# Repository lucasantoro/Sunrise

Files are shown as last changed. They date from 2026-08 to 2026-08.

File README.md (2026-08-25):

# Sunrise

Drone-mounted visible-light communication. The goal is an optical link that a
drone can carry: modulated light instead of RF, with the mechanical, optical,
electronic and firmware work kept as separate areas that reference each other.

The link itself works and is documented in
[`communications/openvlc/`](communications/openvlc/): two nodes, each a
Raspberry Pi with an STM32H723 Pi HAT, carrying IP traffic over Manchester OOK
at 1 Mbit/s in both directions.

## Structure

```text
Sunrise/
  communications/     the optical link — firmware, gateways, control software
  hardware/           PCBs — LED driver, photodiode front end, power, Pi HAT
  mechanical_design/  CAD: mounts, optical housing
  simulations/        link, optical, channel and integration studies
  drone_software/     flight stack and companion-computer integration
  docs/               cross-area architecture and integration notes
  outputs/            generated artefacts
```

`hardware/` and `mechanical_design/` sit beside each other deliberately: the
optical housing and the board geometry are one problem. The current open issue
on the link — isolating a node's transmitter from its own receiver — needs
both.

## Where to start

| you want to | read |
|---|---|
| run the link at the bench | [`communications/openvlc/raspberry-gateway/NOTES.md`](communications/openvlc/raspberry-gateway/NOTES.md) |
| understand how it works | [`communications/openvlc/firmware-v2/docs/modem_design.md`](communications/openvlc/firmware-v2/docs/modem_design.md) |
| know what goes over the light | [`communications/openvlc/firmware-v2/docs/wire_format.md`](communications/openvlc/firmware-v2/docs/wire_format.md) |
| see the boards | [`hardware/README.md`](hardware/README.md) |

## Status

The link is in service and measured: about 830 kbit/s of delivered UDP each
way, 124.6 of 125 frames per second, ~0.30% loss after CRC and Reed-Solomon.

Its open problem is physical rather than software. With both nodes
transmitting, a node's own LED couples into its own photodiode strongly enough
to destroy reception — the transmitter occupies roughly 90% of the frame
period, so there is no dark window to receive in. The fix is optical isolation
between the two, which is where this area meets `hardware/` and
`mechanical_design/`.

## Licence

MIT — see [`LICENSE`](LICENSE).

The Arm CMSIS and STMicroelectronics driver trees under
`communications/openvlc/firmware-v*/Drivers/` are redistributed under their own
Apache-2.0 and BSD-3-Clause terms, and `hardware/` is board design data rather
than software. [`THIRD-PARTY-NOTICES.md`](THIRD-PARTY-NOTICES.md) sets out what
the MIT licence does and does not cover.

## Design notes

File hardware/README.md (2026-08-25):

# Hardware (PCBs)

Altium Designer source and fabrication outputs for the custom boards of the
OpenVLC optical link. These are the physical layer the firmware in the sibling
firmware under communications/openvlc/ runs on: the LED transmitter, the photodiode/comparator
receiver front-end, their power and interconnect boards, and the STM32 +
Raspberry Pi carrier.

```mermaid
flowchart LR
    PDB["power/<br/>PCB_PDB<br/>power distribution"] --> TX
    PDB --> INTER
    TX["tx/<br/>PCB_TX<br/>LED driver (Cree XHP70)"] -->|light| RX
    INTER["interconnect/<br/>PCB_INTER<br/>LED carrier / interface"] --- TX
    RX["rx/<br/>PCB_RX<br/>photodiode + comparator slicer"] --> HAT
    HAT["stm32-pi-hat/<br/>STM32_Pi_HAT<br/>STM32 RX MCU + Pi carrier"]
```

| Folder | Board family | Role in the link |
| --- | --- | --- |
| [`tx/`](tx/) | `PCB_TX` | Optical **transmitter** — high-power LED (Cree XHP70) driver. Driven by the Pi HAT in [`../firmware-v2/`](../communications/openvlc/firmware-v2/). |
| [`rx/`](rx/) | `PCB_RX` | Optical **receiver** front-end — photodiode + analog comparator slicer feeding the STM32. Feeds the Pi HAT in [`../firmware-v2/`](../communications/openvlc/firmware-v2/). |
| [`interconnect/`](interconnect/) | `PCB_INTER` | Interconnect / LED carrier board between the driver and the optics. |
| [`power/`](power/) | `PCB_PDB` | Power Distribution Board supplying the LED / driver chain. |
| [`stm32-pi-hat/`](stm32-pi-hat/) | `STM32_Pi_HAT` | Carrier HAT for the STM32 receiver MCU and the Raspberry Pi gateway ([`../raspberry-gateway/`](../communications/openvlc/raspberry-gateway/)). |

## Revision history

Newest revision per family is listed last and is the current design. A
**Fab date** means a manufacturer order package (`P-<job>_<date>_…`) is
included, i.e. that revision was actually built; revisions with only a
*Project Outputs* archive are design/output snapshots.

### Transmitter — `tx/`
| Revision | 3D | Fab package | Notes |
| --- | :-: | --- | --- |
| `PCB_TX_V2.1.3_B` | ✓ | output archive | bundles footprint libs (XHP70 LED, 0603 R/C) |
| `PCB_TX_V2.1.3_C` | ✓ | output archive | |
| `PCB_TX_V2.2_A` | ✓ | output archive | **current TX** |

### Receiver — `rx/`
| Revision | 3D | Fab package | Notes |
| --- | :-: | --- | --- |
| `PCB_RX_V2.4` | ✓ | — | with footprint libs |
| `PCB_RX_V2.4_B` | ✓ | — | with footprint libs |
| `PCB_RX_V2.5_A` | ✓ | output archive | |
| `PCB_RX_V2.5_B` | ✓ | output archive | |
| `PCB_RX_V2.5_C` | ✓ | output archive | |
| `PCB_RX_V2.6` | ✓ | **2025-12-13** (P-17464) | manufactured |
| `PCB_RX_V2.7` | ✓ | **2025-12-13** (P-17464) | manufactured — **current RX** |

### Interconnect — `interconnect/`
| Revision | 3D | Fab package | Notes |
| --- | :-: | --- | --- |
| `PCB_INTER_V1.1` | ✓ | — | with footprint libs |
| `PCB_INTER_V1.2` | ✓ | **2025-12-13** (P-17464) | manufactured — **current** |

### Power Distribution — `power/`
| Revision | 3D | Fab package | Notes |
| --- | :-: | --- | --- |
| `PCB_PDB_V1.1` | ✓ | — | with footprint libs |
| `PCB_PDB_V1.2` | — | output archive | **current** |

### STM32 / Raspberry Pi carrier — `stm32-pi-hat/`
| Revision | 3D | Fab package | Notes |
| --- | :-: | --- | --- |
| `STM32_Pi_HAT` | ✓ | **2026-05-29** (P-18729) | manufactured. Schematic file is `SRM32_Pi_HAT.SchDoc` (original typo, kept to preserve the Altium project link). |

## What each revision folder contains

- **Editable source** (open in Altium Designer):
  - `*.PrjPcb` — the project file (open this);
  - `*.SchDoc` — schematic;
  - `*.PcbDoc` — board layout;
  - `*.PcbLib` — local footprint libraries used by that revision (where present).
- **`*.step`** — 3D model of the assembled board (mechanical / enclosure work).
- **Fabrication package** — a `.zip` of Gerbers, NC drill, and drill reports,
  ready to send to a board house. The `P-<job>_<date>_…` archives are the
  exact packages that were ordered.

## What was intentionally excluded

To keep the repository lean, the following Altium working artifacts were **not**
imported (they are regenerated locally by Altium and were ~1.1 GB):

- `History/` — automatic per-save backups;
- per-board nested `.git/` repositories (would have become broken submodules);
- `__Previews/`, `Project Logs for …/`;
- `*.PrjPcbStructure`, `*.SchDocPreview` — regenerated index/preview files;
- the loose `Project Outputs for …/` Gerber folders — already captured by the
  per-revision fabrication `.zip`.

See [`../.gitignore`](../communications/openvlc/.gitignore) for the patterns that keep these out if the
original Altium folders are ever re-synced over this tree.

## Opening a board

1. Install Altium Designer.
2. Open the revision's `*.PrjPcb`.
3. The schematic, layout, and local libraries resolve relative to that file.

To re-manufacture a revision, send its fabrication `.zip` to a board house
as-is, or regenerate outputs from Altium (Fabrication Outputs → Gerber/NC Drill).

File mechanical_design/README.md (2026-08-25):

# Mechanical Design

Use this folder for drone-mounted VLC hardware design.

Suggested structure:

```text
mechanical_design/
  inventor/       # Native Autodesk Inventor files
  exports/        # STEP/STL/PDF exports intended for sharing
  mounts/         # LED, photodiode, lens, and PCB supports
  notes/          # Assembly notes, tolerances, alignment notes
```

Avoid committing large generated exports unless they are needed for review or fabrication.

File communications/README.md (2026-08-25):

# Communications

Communication systems for Sunrise. At present that is one thing: the
visible-light link.

```text
communications/
  openvlc/       the VLC link — firmware, Raspberry Pi gateway, control panel
```

## openvlc

An OpenVLC-derived optical link carrying ordinary IP traffic. Two nodes, each a
Raspberry Pi with an STM32H723 Pi HAT, exchange packets over modulated light
and present the result to Linux as a `tun0` interface — so anything with an IP
address on one Pi reaches the other.

Manchester OOK at 1 Mbit/s, full duplex, framed with Reed-Solomon and a CRC.

| | |
|---|---|
| in service | `openvlc/firmware-v2/` |
| in development | `openvlc/firmware-v3/` |
| superseded | five earlier STM32 stages and a BeagleBone chain — not published |

Start at [`openvlc/README.md`](openvlc/README.md).

The boards are not here: they are in [`../hardware/`](../hardware/), beside the
mechanical design, because the PCB geometry and the optical housing are one
problem.

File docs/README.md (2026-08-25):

# System Documentation

Use this folder for Sunrise-level documentation that spans mechanical design, simulations, drone software, and communication firmware.

Suggested documents:

- system architecture;
- drone integration plan;
- hardware block diagrams;
- optical alignment notes;
- test campaign reports;
- bill of materials;
- risk and limitation notes.

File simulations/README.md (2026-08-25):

# Simulations

Use this folder for simulations related to the drone-mounted VLC link.

Possible topics:

- optical link budget;
- LED/photodiode geometry;
- drone motion and pointing error;
- channel noise and ambient light;
- BER/PER simulations;
- network behavior between drones.

Suggested structure:

```text
simulations/
  optical_link/
  drone_motion/
  channel_model/
  notebooks/
  results_sample/
```

## What is here

| file | |
|---|---|
| `Carclo10391_CREE_XHP35_White.zmx` | Zemax model: Carclo 10391 lens over a CREE XHP35 White emitter |

The matching `.ZDA` ray database is **not** in the repository. It is 1.4 GB of
traced rays generated from the `.zmx` above, which exceeds GitHub's 100 MB
per-file limit; Zemax regenerates it from the source model, and the emitter ray
file it starts from comes from the LED vendor.

Keep heavy generated results outside Git or store them as release artifacts.

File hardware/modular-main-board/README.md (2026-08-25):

# OpenVLC modular main board proposal

This note defines a manufacturable direction for splitting the current OpenVLC
hardware into three boards:

- `TX_MODULE`: optical transmitter daughterboard.
- `RX_MODULE`: optical receiver daughterboard.
- `MAIN_BOARD`: power, host/control, protection, service connectors, and
  interconnect between TX/RX.

## Source revisions used

Current hardware in this repository:

| Function | Current source | Fab/output package | Notes |
| --- | --- | --- | --- |
| TX | `tx/PCB_TX_V2.2_A` | `Project Outputs for PCB_TX_V2.2_A.zip` | Current transmitter; ODB++ package present. |
| RX | `rx/PCB_RX_V2.7` | `P-17464_2025-12-13_IMDEA_PCB_RX_V2.7.zip` | Current receiver; manufactured package present. |
| Power | `power/PCB_PDB_V1.2` | `Project Outputs for PCB_PDB_V1.2.zip` | Current PDB. |
| STM32/Pi carrier | `stm32-pi-hat/STM32_Pi_HAT` | `P-18729_2026-05-29_IMDEA_STM32_Pi_HAT.zip` | Current host carrier. |

The source files are Altium `.SchDoc/.PcbDoc`. Gerbers for a new design should
be regenerated from Altium after schematic/layout work and DRC/ERC. The current
workspace does not include an EDA CLI capable of modifying Altium files or
producing verified new Gerbers directly.

## Current board facts

Measured from Gerber/ODB extents:

| Board | Approx. size |
| --- | ---: |
| `PCB_TX_V2.2_A` | 85.0 mm x 54.6 mm |
| `PCB_RX_V2.7` | 85.0 mm x 54.6 mm |
| `PCB_INTER_V1.2` | 48.0 mm x 54.6 mm |
| `PCB_PDB_V1.2` | 100.0 mm x 100.0 mm |
| `STM32_Pi_HAT` | 175.1 mm x 124.4 mm |

Important TX nets/components identified:

- Rails/signals: `+13.8V`, `+5V`, `+3.3V`, `GND`, `P8_45`, `PS_ON`,
  `CS_PD`, `MISO_PD`, `MOSI_PD`, `LED`, `HeatSink`.
- Core TX parts: `LM3409QMY/NOPB`, `LZ4-04MDCA-0000`, `SLF12575T-330M3R2-PF`,
  `PMEG3050EP`, `FDC6333C`, `DMT67M8LSS-13`, `ZXMP7A17KTC`,
  `SN74AHC1G126DBVR`, current-sense resistor `CRA2512-FZ-R075ELF`.

Important RX rails/signals identified:

- Rails/signals: `+5V`, `-5V`, `VCC`, `GND`, `VREF`, `VAGC`, `MODE`, `OFSN`,
  `AGC_P`, `AGC_N`, `LNA_P`, `LNA_N`, `BPF_P`, `BPF_N`, `LPF_IN`, `LPF_OUT`,
  `GAIN_OUT`, `ADC_IN`, `CS_PD`, `MISO_PD`, `MOSI_PD`, `+IP`, `-IP`,
  `+VT`, `-VT`, `+VB`, `-VB`, `+eOP`, `-eOP`.
- Core RX parts visible in schematic: `ADA4817-2`, `AD80xx` gain/filter
  stages, `ADS788x` ADC, `LM2661` charge pump, trim pots, analog filters and
  bias networks.

## Proposed partition

### TX_MODULE

Keep the high-current optical transmitter loop on the TX module:

- LED and optics/mechanical alignment.
- LM3409 LED driver, switch MOSFET, diode, inductor, current-sense resistor,
  compensation network, and local high-frequency decoupling.
- Gate/control buffer only if needed to preserve PWM edge quality at the
  driver.
- Local temperature/fan connector if mechanically tied to the LED/heatsink.

Move to `MAIN_BOARD`:

- BeagleBone/Pi/STM32 headers and host-specific wiring.
- Global `+13.8V`, `+5V`, `+3.3V` generation and power sequencing.
- Bulk input protection, fuse/eFuse, reverse polarity protection, power switch,
  service/test connectors.
- Any debug-only test headers not required at the optical module.

Reason: the LED switching current loop must stay physically compact. Moving the
LM3409 power stage to the main board and routing LED current over a connector
would increase EMI and optical-current ringing.

### RX_MODULE

Keep the low-noise receive chain on the RX module:

- Photodiode and optical/mechanical interface.
- First transimpedance/low-noise amplifier stage.
- Critical gain/filter stages whose nodes are `LNA_*`, `BPF_*`, `LPF_*`.
- ADC or comparator/slicer close to the analog front-end unless the main board
  can guarantee a shielded, controlled-impedance short analog path.
- Local analog decoupling, guard ring, and bias/reference filtering.

Move to `MAIN_BOARD`:

- Host MCU/Raspberry Pi/BeagleBone carrier functions.
- SPI/UART/control routing and level shifting.
- Global rails and power supervision.
- Non-critical debug headers.

Preferred RX interface is digital after ADC/comparator. Exporting `ADC_IN` as
an analog signal across a board-to-board connector is possible but should be
treated as the fallback option because it is the most noise-sensitive boundary.

### MAIN_BOARD

Integrate the current PDB and STM32/Pi carrier roles:

- Input power connector, fuse/eFuse, reverse polarity, TVS, current monitoring.
- Buck rail generation: `+13.8V` distribution, `+5V`, `+3.3V`.
- Quiet analog rail generation/filtering for RX: `+5VA`, `-5VA`, `VREF`.
- MCU/host connector and firmware/debug access.
- Board-to-board connectors for one or more TX/RX modules.
- Star-ground strategy and physical zoning for power, digital, and analog.

## Proposed module interfaces

Use locking board-to-board or cable connectors with ground pins interleaved
between noisy or sensitive signals. Do not reuse generic 2.54 mm headers for
final flight/field hardware unless mechanical retention is added.

### TX connector

Minimum signals:

| Pin group | Signal |
| --- | --- |
| Power | `+13.8V_LED`, multiple pins |
| Power return | `PGND_LED`, multiple pins adjacent to `+13.8V_LED` |
| Logic | `TX_PWM` / current modulation input |
| Control | `TX_EN` / `PS_ON` |
| Telemetry | `TX_FAULT`, `TX_TEMP` optional |
| Service | `SCL/SDA` or spare GPIO optional |
| Shield | Chassis/shield if cable is used |

Keep `+13.8V_LED` and `PGND_LED` connector current rating at least 2x the
expected continuous LED current, with derating for temperature.

### RX connector

Preferred digital boundary:

| Pin group | Signal |
| --- | --- |
| Analog power | `+5VA`, `-5VA`, `AGND` |
| Digital power | `+3V3D` or `+5VD`, `DGND` |
| Data | `RX_SPI_SCK`, `RX_SPI_MISO`, `RX_SPI_MOSI`, `RX_CS` |
| Timing | `RX_SAMPLE_CLK` or `RX_DATA_READY` |
| Control | `RX_MODE`, `RX_GAIN`, `RX_EN` |
| Reference/monitor | `VREF_MON`, `RSSI/GAIN_OUT` optional |

Fallback analog boundary:

- `ADC_IN` must be surrounded by ground pins, routed short, shielded, and kept
  away from TX power routing.
- Add an RC input filter and clamp at the main-board ADC input.

## EMC, noise, and layout constraints

- Use at least a 4-layer stackup for the main board: signal, solid GND, power,
  signal. Prefer 6 layers if TX current and RX analog coexist on the same PCB.
- Physically separate zones: TX power stage, digital host/MCU, RX analog.
- Put RX analog at the quiet edge of the board. Put TX power at the opposite
  edge. Do not route LED current below the RX module.
- Use a single low-impedance ground system, but route high-current LED return
  directly back to the input/power stage so it does not share narrow copper with
  RX analog returns.
- Add ferrite beads or small LC filters at RX module power entry:
  `+5V_MAIN -> +5VA_RX`, `-5V_MAIN -> -5VA_RX`.
- Keep switching converters, charge pumps, inductors, and fast LED nodes away
  from photodiode/TIA input. If `LM2661` remains on RX, place it in its own
  noisy island with filtering and guard spacing from the photodiode input.
- Route SPI/control to RX with series damping resistors near the driver and
  ground reference pins beside the clock/chip-select.
- Route TX PWM/enable with series damping near the MCU/buffer. Avoid long,
  unterminated fast edges into the LED driver.
- Add TVS/ESD at external connectors, not at the sensitive photodiode node.
- Place test points for `+13.8V`, `+5V`, `+3.3V`, `+5VA`, `-5VA`, `TX_PWM`,
  `TX_EN`, `RX_CS`, `RX_MISO`, `ADC_IN`/digital RX output, and `GND`.

## Gerber/schematic generation path

1. Clone `PCB_TX_V2.2_A` and `PCB_RX_V2.7` into new Altium projects:
   `TX_MODULE_V1`, `RX_MODULE_V1`, `MAIN_BOARD_V1`.
2. Remove host/header/global-power circuitry from TX/RX according to the
   partition above.
3. Add explicit board-to-board connector symbols with locked pinout tables.
4. Move PDB and STM32/Pi carrier functions into `MAIN_BOARD_V1`.
5. Compile all three projects and run ERC.
6. Push ECO from schematic to PCB for each board.
7. Layout with the EMC constraints above; run DRC.
8. Generate Gerber X2, NC drill, ODB++, pick/place, BOM, and STEP.
9. Before fabrication, review Gerbers in an independent viewer and check:
   board outline, drill registration, polarity, solder mask openings,
   connector pin-1 orientation, and TX/RX mating orientation.

## Open decisions before layout

- Number of TX/RX module slots: single link, dual link, or multi-TX array.
- Host architecture: keep STM32 + Raspberry Pi HAT, or replace with a custom
  MCU section on the main board.
- RX boundary: digital after ADC/comparator, or analog `ADC_IN` to main board.
- Mechanical stack: mezzanine modules, cabled modules, or edge-mounted modules.
- LED thermal solution and whether fan control is local to TX or on main board.

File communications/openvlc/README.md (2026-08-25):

# OpenVLC

A visible-light IP link. Two nodes, each a Raspberry Pi carrying an STM32H723
Pi HAT, exchange Linux IP traffic over modulated light — Manchester OOK at
1 Mbit/s, full duplex, presented to Linux as an ordinary `tun0` interface.

```text
   Pi node A                                   Pi node B
   tun0 192.168.0.1                            tun0 192.168.0.2
        |                                            |
   UART 2 Mbaud                                 UART 2 Mbaud
        |                                            |
   H723 Pi HAT      ~~~~~ modulated light ~~~~~  H723 Pi HAT
   optical addr 7      TIM1 TX / COMP1 RX        optical addr 8
```

Anything with an IP address on one Pi can reach the other. The bench runs
`iperf` and streams video over it.

## State

| | |
|---|---|
| **In service** | [`firmware-v2/`](firmware-v2/) |
| Best measured | 124.6 of 125 frames/s delivered, ~0.30% loss, ~830 kbit/s each way |
| **In development** | [`firmware-v3/`](firmware-v3/) — not deployed |
| Superseded | five earlier STM32 stages and the BeagleBone chain — not published |

**Open issue, physical:** with both nodes transmitting, a node's own LED
couples into its own photodiode strongly enough to destroy reception. The
transmitter occupies ~90% of the frame period, so there is no dark window to
hide in. This is being fixed with optical isolation, not in software — see
`firmware-v2/docs/two_transceiver_test.md`.

## Layout

| folder | runs on | what |
|---|---|---|
| [`firmware-v2/`](firmware-v2/) | STM32H723 Pi HAT | **the firmware in service** — comparator RX, TIM1 TX, framing, RS, CRC |
| [`firmware-v3/`](firmware-v3/) | STM32H723 Pi HAT | streaming-decoder experiment; carries a faithful port of the reference implementation for A/B work |
| [`raspberry-gateway/`](raspberry-gateway/) | Raspberry Pi | the bridge: `tun0` ↔ UART, pacing, capture collection, install scripts |
| [`control-app/`](control-app/) | lab PC | PySide6 panel driving the nodes over SSH, live telemetry, diagnostics |

The link went through five earlier STM32 stages and a BeagleBone-transmitter
chain before this one. They are not published: they are superseded, and none of
them builds against the current hardware. One thing from that lineage does
survive here — the frame layout and Reed-Solomon scheme are the upstream
OpenVLC BeagleBone protocol, which `OPENVLC_BEAGLEBONE_COMPAT` selects.

The boards these run on are one level up, in [`../../hardware/`](../../hardware/):
LED driver, photodiode front end, interconnect, power and the STM32 Pi HAT
carrier. They live beside `mechanical_design/` because the optical housing and
the PCB geometry are one problem, not two.

## Start here

**At the bench**, on a Pi:
[`raspberry-gateway/NOTES.md`](raspberry-gateway/NOTES.md) — the commands, how
to enable and save logs, and the meaning of every field in the `COMP`, `TX` and
`trx-bridge` diagnostic lines, plus the failure signatures that are worth
recognising on sight.

**Understanding the link:**

- [`firmware-v2/docs/wire_format.md`](firmware-v2/docs/wire_format.md)
  — line code, frame layout, addressing, Reed-Solomon, and the airtime budget
  that governs most of the system's behaviour
- [`firmware-v2/docs/modem_design.md`](firmware-v2/docs/modem_design.md)
  — how the transmitter and receiver work, and why the comparator threshold
  decides whether the decoder has any margin at all
- [`firmware-v2/docs/comparison_reference_impl.md`](firmware-v2/docs/comparison_reference_impl.md)
  — v2 against a colleague's 884-line implementation of the same link, measured
  side by side

**Bringing up two nodes:**
[`firmware-v2/docs/two_transceiver_test.md`](firmware-v2/docs/two_transceiver_test.md)

## Node naming

Hosts are named `nodeA`, `nodeB`, … and the Pi side derives everything from
that: node letter, tun address (`nodeC` → `192.168.0.3`), and the tag written
into capture filenames. Adding a node means naming the host and running the
installer.

The optical address is separate and set at firmware build time
(`OPENVLC_TRANSCEIVER_NODE`). A receiver discards frames carrying its own
address as source, so **the two boards must never be flashed with the same node
firmware**.

## Quick start

Install the bridge on each Pi:

```bash
cd raspberry-gateway && sudo bash ./install/install_transceiver_service.sh
```

Check the interface came up and the path carries a full-size frame:

```bash
ip -br addr show tun0 && ping -c 5 -M do -s 872 192.168.0.2
```

Measure one direction:

```bash
iperf -u -c 192.168.0.2 -b 800k -l 800 -p 10001 -t 60 -i 1
```

Watch what the modem is doing while it runs:

```bash
journalctl -u openvlc-transceiver -f | grep -E "COMP|TX uart|trx-bridge"
```

Reading those numbers is [`raspberry-gateway/NOTES.md`](raspberry-gateway/NOTES.md).

## A note on the numbers

Loss figures in this repository are counted **after** CRC and Reed-Solomon, so
a "lost" frame is one that failed integrity, not one that arrived corrupt and
was passed on. Implementations without an integrity check report a different
quantity under the same name; the comparison document above goes into why that
makes throughput numbers across implementations incomparable.

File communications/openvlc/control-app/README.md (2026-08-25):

# OpenVLC Control Panel

PySide6 desktop app that runs on the lab PC and controls OpenVLC lab nodes over
SSH. It supports both the legacy RX Pi / TX Pi / BeagleBone video chain and the
two-node STM32 Pi HAT transceiver setup (`openvlc-transceiver` on node A/B).

```mermaid
flowchart LR
    PC["PC\ncontrol panel + VLC"] -->|SSH| RX["RX Pi\nopenvlc-rx + relay"]
    PC -->|SSH| TX["TX Pi\nroute + webcam"]
    PC -->|"SSH via TX Pi"| BBB["BeagleBone\noptical TX"]
    RX -->|"TCP/UDP relay"| PC
    PC -->|SSH| A["Transceiver A Pi\nopenvlc-transceiver"]
    PC -->|SSH| B["Transceiver B Pi\nopenvlc-transceiver"]
    A <-->|"optical + UART bridge"| B
```

## Install on Windows

```powershell
winget install Python.Python.3.12
cd communications\openvlc\control-app
py -m venv .venv
.\.venv\Scripts\Activate.ps1
pip install -r requirements.txt
py run.py
```

Install VLC on the PC and keep the path configured in the Settings tab.

## First run

1. Open **Settings**.
2. Fill in the SSH settings for the nodes you use. For the Pi HAT transceiver
   workflow, configure **Transceiver A Pi** and **Transceiver B Pi**. For the
   legacy video workflow, configure **RX Pi**, **TX Pi**, and **BeagleBone TX**.
   The BBB can use the TX Pi as jump host when it is reachable only through USB
   gadget Ethernet.
3. Set **This PC IP**, **VLC path**, and the validated **TX budget profile**.
4. Save, then run **Test connections**.
5. Run **Check system** before starting traffic.

The configuration is stored in `~/.openvlc_panel.json`. It is plain JSON for lab
convenience, not secure credential storage.

The **RX bridge** and **TX route** buttons run privileged commands on the
Raspberry Pis. Either save the SSH password for those devices in Settings or
configure passwordless sudo for the lab user. Without one of those, systemd and
route setup commands fail with `sudo: a terminal is required`.

For the BBB, prefer a numeric host address. The usual direct USB-gadget target
is `192.168.7.2`; if the BBB is reachable only from the TX Pi, set
`192.168.7.2` as the BBB host and configure the TX Pi fields as its jump host.

## Tabs

### Control

The first tab separates the workflow into three explicit stages:

1. **Verify** - run read-only checks for devices, paths, routes and tools.
2. **Prepare link** - start monitoring, restart the RX bridge, configure the
   TX route and start the selected BBB optical profile.
3. **Performance test** - choose UDP target rate, duration and direction, then
   run iperf.

For the Pi HAT transceiver workflow, the app provides service controls for
node A, node B, and A+B together. The `openvlc-transceiver` daemon is
bidirectional by design, so the app separates TX and RX at test level:

- **Transceiver A -> B** starts iperf server on B and client on A.
- **Transceiver B -> A** starts iperf server on A and client on B.
- **Transceiver full duplex** starts servers on both nodes and clients in both
  directions concurrently.

The **Journal TRX A/B** buttons switch the live monitor to
`journalctl -u openvlc-transceiver -f -o cat -n 0` on the selected node.

Video controls are intentionally absent from this tab. The complete live
session is started and stopped from the **Video** tab.

The iperf result shown by the panel is based on the receiver/server output for
each flow, because that is the authoritative result for delivered throughput
and loss. The transmitter/client output is still included for context.

The iperf runner starts remote processes through PID files:

- receiver/server: `/tmp/openvlc_panel_iperf_server.pid` and
  `/tmp/openvlc_panel_iperf_server.log`;
- transmitter/client: `/tmp/openvlc_panel_iperf_client.pid` and
  `/tmp/openvlc_panel_iperf_client.log`.

Use **Stop iperf** to terminate any server/client started by the panel. The app
then collects the receiver and transmitter logs and prints them in the Activity
log.

When iperf starts, the GUI also starts the monitor if needed and records link
quality samples for the test interval. It does not start or restart the RX
bridge, TX route, or BBB optical TX; those belong to Prepare link. The final iperf
output includes:

- RX goodput.
- RX loss.
- quality verdict.
- score average/min/max.
- jitter average/max.
- timing quality average.
- Reed-Solomon correction average/max.
- SFD lock and SFD error summary.

### Link Quality

- **Start monitor** tails the selected link service:
  `openvlc-rx` for the legacy RX Pi or `openvlc-transceiver` for transceiver
  A/B. The monitor shows the latest 80 journal lines immediately and then
  follows new output. Raw journal text appears in both the Control Activity log
  and the Link Quality live journal console.
- **Check system** runs a preflight across RX Pi, TX Pi, BBB, local VLC path,
  routes, camera presence, services, and tool availability.
- **Collect diagnostics** writes a local report in `~/Downloads`.
- The link badge checks stale logs, bridge errors, host/ring drops, zero valid
  packets while traffic is present, SFD errors, and excessive timing jitter.

Readouts include IP rate, frame rate, transceiver TX/RX kbps/fps, last iperf
goodput, `ok/s`, `seen/s`, `ok/seen` diagnostic ratio, per-interval
`seq_gap`, transceiver RX gap, TX drop, ring/host drops, host errors, invalid
IP packets, serial CRC/header errors, edge rate, glitch rate/permille,
comparator threshold, half-cell estimate, decode time, compact firmware
CRC/sync/frame-fail counters, quality score, score minimum, jitter, timing
quality (`tq`), Reed-Solomon corrections, SFD lock/sync/pre-reject counters,
payload length, raw frame length, and PHY status.

Raw comparator metrics can be non-zero even when the opposite optical TX is
off. Ambient light, analog front-end noise, threshold servo activity, and
periodic firmware reporting can still produce `COMP` log lines. The link badge
therefore does not treat raw `edge/s`, duty, or threshold updates as a valid
link. It reports **idle (no valid RX packets)** unless recent receiver-side
valid packets, bridge RX rate, or packet logs are present. During an iperf run,
the same condition is reported as degraded.

The **Live metrics** summary uses `IP rate` for the live bridge throughput. The
separate `iperf RX goodput` field is only populated after an iperf run.
Goodput means the receiver-measured useful UDP/application payload rate for
that test. It is the throughput that applications can actually consume, after
PHY overhead, preamble/SFD/header bytes, Reed-Solomon parity, inter-frame gaps,
and rejected packets. It is not the BBB enqueue rate and it is not the raw
Manchester symbol rate.

The quality score is the packet-level metric emitted by the STM32 receiver. In
host-forward mode the firmware suppresses per-packet `VLC_RX packet` text to
save UART bandwidth, so the latest valid packet quality is carried on the
periodic `COMP` line as `qvalid=1 score=... jitter=... tq=... rs=...`. Older
or non-forwarding firmware may log the same values as `lqi` and `tjit`; the GUI
normalizes them to `score` and `jitter`. This metric is not electrical SNR. It
summarizes decoder margin from the edge-timing architecture: stable timing,
valid SFD lock, valid Manchester reconstruction, low jitter, and packet
validation behavior. It is the metric to watch when changing AGC, comparator
threshold, TX budget, optics, or distance. It is available only after at least
one packet is accepted in the current reporting interval (`qvalid=1` in the
STM32 log).

The `seq_gap / ringdrop` chart shows new events per log interval, not lifetime
counter totals. When the monitor goes stale, transient readouts are cleared and
the interval-rate plots are driven back to zero so old drops are not shown as
current link failures.

`ok/seen` is intentionally not used as a degraded-link gate. `seen/s` includes
candidate bursts and false starts submitted to the PHY, while `ok/s` is the
validated IP packet rate. A low `ok/seen` ratio can be normal when `ok/s`,
goodput, score, jitter, `seq_gap`, and `ringdrop` are healthy.

### Diagnostics

Dedicated tab for preflight, SSH connection test, and report collection. Output
is mirrored from the Control tab so command results are easy to copy.

For transceiver nodes the report includes `openvlc-transceiver` service state,
recent STM32 journal, `/etc/default/openvlc-transceiver`, `tun0`, route to the
peer TUN IP, serial devices, and running bridge/iperf processes.

### Video

**Start video session** performs the complete operation in order: it starts the
RX relay/player and, after the relay is ready, starts the selected TX camera
profile. **Stop video session** stops both sides. There is no separate,
duplicated live-start step.

The **Camera location** selector controls the complete video route:

- **Camera on Node B → receive on Node A** uses the `Transceiver B Pi` SSH
  endpoint, sends to the configured Transceiver A TUN IP (normally
  `192.168.0.1`), and starts the relay on `Transceiver A Pi`. This is the
  default.
- **Camera on Node A → receive on Node B** uses the `Transceiver A Pi`, sends
  to the Transceiver B TUN IP (normally `192.168.0.2`), and starts the relay on
  `Transceiver B Pi`.
- **Legacy TX Pi → RX Pi** preserves the BeagleBone/one-way setup.

The selection is saved in `~/.openvlc_panel.json` as `video_camera_node`.
Changing it does not require editing Python or duplicating transceiver
credentials into the legacy TX/RX fields. The selector is locked while a video
session is active so stop, status checks and cleanup always target the same
machines that were used at session start.

The session badge now represents the video pipeline, not only the optical-link
badge:

- `STARTING`: creating the RX relay and local player;
- `BUFFERING`: relay and encoder are alive, VLC has not decoded video yet;
- `LIVE`: embedded VLC reached `Playing`;
- `TX ERROR` / `RELAY ERROR`: the corresponding remote process exited;
- `NO VIDEO`: both remote processes are alive but the player did not decode a
  stream within the startup window.

The text below the preview reports the player state. On an error, the Control
log includes the tails of `/tmp/openvlc_panel_relay.log` and
`/tmp/openvlc_panel_tx_video.log`. The main link-health badge can remain healthy
when video fails because it validates the optical/packet path, not FFmpeg,
UDP/5000, the relay, or VLC decoding.

The configured video port is passed explicitly to both ends of the session.
FFmpeg transmits to the TUN address automatically derived from **Camera
location**, and the relay on the opposite node listens on the same
`<video_port>`. This is required when using a non-default value; previously the
destination was hardcoded to `192.168.0.2` and the relay followed only the
legacy RX Pi setting.

The live viewer can use:

- **TCP relay** for cleaner PC playback and fewer firewall issues.
- **UDP relay** for lower latency.
- Embedded VLC via `python-vlc`, or an external VLC window as fallback.

TX video uses named profiles first. Advanced encoding fields are collapsed by
default and can be expanded when needed:
capture/output size, fps, bitrate, MPEG-TS muxrate, rate mode, CRF, x264 preset,
VBV buffer, mux delay, and V4L2 input format.

After an iperf run, the video panel compares the selected `MUXRATE` with the
measured RX goodput and displays the capacity margin. Keep a practical margin
of at least 10-15 percent for stable video.

### Settings

Settings are split between:

- Device SSH endpoints.
- Local PC settings and validated TX budget profile.
- Advanced remote directories, transceiver TUN IPs, iperf payload size and
  ports.

Only validated TX budget profiles are selectable. This avoids the old failure
mode where the UI accepted values that had no matching BBB script/RX profile.

## Remote process management

Processes started by the panel use PID files instead of broad `pkill` commands:

| Process | PID file | Log |
| --- | --- | --- |
| RX live relay | `/tmp/openvlc_panel_relay.pid` | `/tmp/openvlc_panel_relay.log` |
| TX video | `/tmp/openvlc_panel_tx_video.pid` | `/tmp/openvlc_panel_tx_video.log` |
| iperf receiver/server | `/tmp/openvlc_panel_iperf_server.pid` | `/tmp/openvlc_panel_iperf_server.log` |
| iperf transmitter/client | `/tmp/openvlc_panel_iperf_client.pid` | `/tmp/openvlc_panel_iperf_client.log` |

The GUI only stops processes it started. If a manual `ffmpeg`, `socat`, or
iperf instance is already running, the preflight/diagnostics output makes that
visible so it can be handled intentionally.

## Diagnostics

**Collect diagnostics** creates:

```text
~/Downloads/openvlc_diag_YYYYMMDD_HHMMSS.txt
```

The report includes sanitized local configuration, recent RX bridge journal,
network interfaces/routes, TX camera formats, current media processes, BBB TX
profile, BBB `VLC: params`, `vlc0` counters, and qdisc state.

Attach this file when debugging GUI, routing, link, or video issues.

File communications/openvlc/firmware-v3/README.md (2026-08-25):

# OpenVLC STM32H723 full-duplex transceiver - Raspberry Pi HAT (v2)

This directory is the maintained Pi-HAT firmware variant. Its active receiver
is comparator-edge based; sampled ADC and software-timer RX paths are not used.

## v2 deltas vs the original

| Change | Where | Why |
|---|---|---|
| Packet-local timing recovery | `openvlc_phy.c` | Every burst estimates `t0`, `t1`, and `T`; independent run quantisation with a profile-scaled 1/16-cell bias avoids propagating a defective crossing. |
| Pair-aware cell timing | `openvlc_phy.c` | If two adjacent comparator intervals still total two cells, the decoder applies the only possible `1+1` decomposition instead of inserting a false cell when one crossing moves. |
| CRC-gated differential fallback | `openvlc_phy.c` | In the same edge pass, retain the independent event-timing interpretation in a compact bit stream; parse it only after a complete primary frame fails CRC (`m=51` on recovery). |
| Deadline-bound recovery | `openvlc_phy.c`, `openvlc_stm32_hal.c` | The measured packet cadence limits complete decoder passes; a damaged frame cannot consume several following 8 ms periods and collapse the capture ring. |
| Bounded timing training | `openvlc_phy.c` | Timing is estimated from the first 1536 edges, which retain the validated 37/27-tick training run without scanning the complete payload twice. |
| Fast verified Reed-Solomon | `openvlc_frame.c` | Data and parity remain correctable and are rechecked, but precomputed syndrome transitions replace per-byte GF log/modulo work. Tables are initialized before capture starts. |
| Constant-time compatibility length | `openvlc_phy.c`, `openvlc_frame.c` | Payload length is resolved from at most five possible RS block counts instead of scanning all 901 payload sizes twice per frame. |
| Length-vs-burst sanity check | `openvlc_phy.c` (after length accept) | A corrupted 16-bit length that cannot fit in the burst's remaining cell budget is rejected immediately (relock) instead of consuming thousands of cells in the wrong phase. |
| Lean compact instrumentation | `OPENVLC_DIAGNOSTIC_LEVEL` | Compact health logs no longer enable a second edge pass or per-edge residual tracking; the edge-rate counter is accumulated once per polling visit instead of with a volatile store per edge. |
| Decimated quality estimator | `OPENVLC_RX_QUALITY_DECIMATION` | Link jitter/LQI remains available without executing a 64-bit timing-square for every received interval. |
| RX idle-time burst finalization | `OPENVLC_RX_IDLE_TIMEOUT_FLUSH` | Double-checks the DMA head around the timer sample, then starts decoding at the end of the current burst instead of waiting for the first edge of the next frame. |
| Corpus-bounded RX delimiter | `OPENVLC_EDGE_GAP_US` | At 1 Mbit/s the single 6-us delimiter retains the measured 3.86-us in-frame maximum without the ring pressure caused by a speculative full decode or the frame merging observed at 8 us. |
| Bounded TX inter-frame pacing | `OPENVLC_STM32_TX_INTERFRAME_GUARD_US` | READY slots retain FIFO order but cannot be chained with only the 32-cell electrical tail; the 400 us guard smooths Linux/UART bursts while retaining capacity for 828-byte packets at 125 fps. |
| Duty-servo target trim | `openvlc_stm32_hal.c` (`comp_duty_target_trim`), `OPENVLC_COMP_DUTY_TRIM*` in `openvlc_board.h` | duty=50% is the DC mean, but the measured impossible-run minimum sits 1-2 steps off centre (asymmetric hysteresis/propagation). A slow hill-climb moves the servo setpoint to minimise `longps` - the direct measure of lost transitions. Logs `COMP TRIM ...`. |
| `.ioc` hysteresis aligned to `COMP_HYSTERESIS_LOW` | `stm32.ioc` | `comp.c` was already LOW but the `.ioc` still said HIGH: a CubeMX regeneration would have silently reverted it. (The ORIGINAL project still has this trap.) |

The earlier integer timing IIR, DPLL residual carry, and experimental local
timing grid were removed: real and live Pi-HAT traffic showed that they could
propagate a local crossing defect through otherwise valid packet timing. Run
decisions therefore remain independent.

---

This is the pin-remapped Raspberry Pi HAT variant of the validated comparator
receiver and STM32 transmitter. It preserves the OpenVLC PHY, framing,
2 Mbaud host protocol, DMA queues, symbol profiles, and 192 MHz TX timer clock.

## Hardware

Target: **custom Raspberry Pi HAT / STM32H723VET6 (LQFP100)**

For the autonomous `OWC_TX` boot waveform and fault/heartbeat LED meanings,
see [docs/pi_hat_tx_diagnostics.md](docs/pi_hat_tx_diagnostics.md).

| Function | MCU pin | Peripheral |
|---|---|---|
| RX analog input | PB0 | COMP1_INP / `COMP_INPUT_PLUS_IO1` |
| RX capture | internal | COMP1_OUT -> TIM2_TI4 mux |
| RX diagnostic output | PC5 | optional; set `OPENVLC_COMP_DEBUG_OUTPUT=1` |
| RX threshold | internal | DAC1_CH1 -> COMP1_INM |
| TX modulation | PE9 | TIM1_CH1, AF1, low slew rate |
| TX alternate-path disable | PB5 | GPIO low |
| Raspberry serial TX/RX | PB10 / PB11 | USART3_TX / USART3_RX, AF7 |

No PC5-to-PB11 jumper is required. The firmware selects the internal
TIM2_TI4_COMP1 route with `HAL_TIMEx_TISelection()`, leaving PB11 available for
USART3_RX. RX and TX optical front ends must share ground with the STM32 and
Raspberry Pi. See [`docs/pi_hat_port.md`](docs/pi_hat_port.md) for wiring and
bring-up checks. Pin references in inherited architecture documents are
superseded by the table above.

## Runtime architecture

- RX edges: COMP1 -> TIM2_CH4 -> DMA1 Stream1 -> 128 KB circular ring.
- TX cells: TIM1_CH1, with TIM1_CH4 requesting DMA2 Stream0 updates.
- Raspberry input: USART3 RX -> DMA1 Stream2 circular buffer.
- Raspberry output: USART3 TX interrupt queue.
DMA1 is intentionally reserved for the latency-sensitive comparator capture
path. Putting the high-rate TIM1 cell stream on DMA1 causes TIM2 overcapture
and deterministic RX loss during simultaneous TX/RX operation.
TIM1 belongs exclusively to the hardware TX generator. ADC1 and TIM6 are not
used for sampling; TIM6 is reserved as the 1 MHz one-shot that releases a
queued TX slot after the inter-frame guard.

The serial interface is electrically full duplex. At 2 Mbaud, each direction
has its own 2 Mbaud line capacity; RX and TX traffic are not added onto one
half-duplex budget.

## Runtime diagnostics

Set only `OPENVLC_DIAGNOSTIC_LEVEL` in `Core/Inc/openvlc_board.h`:

| Level | Intended use | Runtime cost |
|---:|---|---|
| `0` | deployment and iperf | no periodic STM32 logs, no diagnostic burst scan, no TX hardware monitor |
| `1` | link health | one-second RX/TX summaries and heartbeat text |
| `2` | fault investigation | register snapshots, decoder detail, TX pin probe and 10 kHz TX monitor |

Level `1` is the current validation default; select level `0` for the final
minimum-overhead deployment image. Comparator auto-threshold and duty-servo control are
independent of logging: if either feature is enabled, its control loop still
runs with diagnostic text disabled.

At diagnostic levels 1 and 2, the compact `COMP` record also reports the raw
TIM2 interval rates before software deglitching: `r07`, `r811`, `r1215`,
`r1619`, `r2023`, and `r24p`. The names denote tick ranges (for example,
`r1619` is the number of consecutive raw edges per second separated by 16--19
ticks); `r24p` is the remainder at 24 ticks or longer. These bins distinguish
comparator/filter pulse loss from pulses rejected by the software gate without
changing the deployed level-0 hot path.

`OPENVLC_RX_CAPTURE` is also independent of periodic diagnostics. When
enabled, it builds a spaced, balanced good/failure population. Version-2 files
preserve raw pre-filter comparator intervals, and the Raspberry bridge saves a
validated `.bin` plus `.json` for deterministic offline replay.
See [RX signal capture and offline replay](docs/rx_failure_trace.md).
See [bounded RX list decoding](docs/rx_list_decoder.md) for the CRC-gated
multi-slip recovery used by the 1-Mbit/s Pi-HAT profile.
The deterministic [synthetic channel campaign](docs/synthetic_channel_tests.md)
tests the decoder against timing drift, jitter, duty-cycle distortion, extra
and missing edges, glitches, clipped captures, and truncated frames.

## Build

Import STM32CubeIDE/ as project stm32-transceiver-pi-hat and build Debug.
The build is fixed to STM32H723xx; selecting an H743 target fails at compile
time.

On Windows, import the project through a local or mapped-drive path such as
`Z:\Projects\Sunrise\...`. STM32CubeIDE's generated makefiles do not resolve
linked resources correctly when the project is imported directly from a UNC
path such as `\\server\share\...`.

The linker enforces the real H723 memory limits:

- Flash: 512 KB
- DTCM: 128 KB
- AXI SRAM: 320 KB
- D2 SRAM: 32 KB

Current Debug allocation is approximately 55 KB Flash, 76 KB DTCM, 287 KB AXI
SRAM, and 8 KB D2 SRAM.

## Raspberry bridge

Use the single bidirectional bridge. Do not run the standalone RX and TX
services against the same serial port.

On each Raspberry Pi, first disable the serial login console and enable the
hardware UART with `sudo raspi-config`, then reboot. Install the GPIO-UART
profile from `communications/openvlc/raspberry-gateway`:

~~~bash
# Node A (.1, peer .2)
sudo ./install_transceiver_service.sh --node a --pi-hat

# Or node B (.2, peer .1)
sudo ./install_transceiver_service.sh --node b --pi-hat
~~~

The installer selects `/dev/serial0`, requires 2 Mbaud, and runs
`check_pi_hat_uart.sh`. It deliberately rejects the mini-UART (`ttyS*`) and an
active serial console. This avoids `auto` selecting the connected ST-LINK VCP.

~~~bash
sudo python3 ./vlc_transceiver_bridge.py \
  --port /dev/serial0 \
  --baud 2000000 \
  --dev tun0 \
  --ip 192.168.0.2/24 \
  --peer-ip 192.168.0.1 \
  --source-route 10.0.0.0/24 \
  --mtu 900
~~~

A service template is provided as openvlc-transceiver.service. These defaults
configure the current transceiver as node `.2`, interoperable with the legacy
BBB TX path. A second transceiver at the opposite end must use `.1/24`, peer
`.2`, and a source route appropriate to its local network.

By default the bridge forwards TUN egress to the STM32 TX only when the IP
destination is the configured optical peer (`192.168.0.1/32` on node `.2`).
This prevents iperf server feedback and kernel ICMP traffic addressed to the
legacy `10.0.0.0/24` source network from activating the LED while receiving.
Use repeated `--tx-allow CIDR` options for additional remote networks, or
`--forward-all` only when the optical link is intended to be a general router.

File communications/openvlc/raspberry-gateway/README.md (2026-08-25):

# Raspberry Pi OpenVLC video path

> **Full operations & testing runbook + parameter reference:**
> [`docs/operations.md`](docs/operations.md) - bring-up, end-to-end iperf,
> headless video viewing, latency tuning, every configurable parameter, and a
> troubleshooting table.

This directory contains the companion-computer software for a one-way video
link:

```text
USB webcam
  -> TX Raspberry Pi
  -> Linux TUN interface, 192.168.0.1/24
  -> framed USART3 stream, 2 Mbit/s
  -> STM32H7 OpenVLC transmitter
  -> optical Manchester link
  -> STM32H7 COMP1/TIM2 receiver
  -> 2 Mbit/s framed USART3 stream
  -> RX Raspberry Pi (tun0)
  -> ffplay or mpv
```

The STM32 outputs the original decoded IP datagram. The receiver bridge only
checks the serial record and the IP header, then writes the packet to a Linux
TUN interface. No custom video protocol is required.

The optical path is one-way. Use UDP video and iperf2 UDP. Do not use iperf3,
TCP, RTSP control sessions, or protocols that require acknowledgements from
the receiver.

## Layout

The runtime Python sits flat at the root on purpose: the modules import each
other by bare name and the installer copies them into one directory on the Pi,
so the deployed layout and this one match. Everything that is not runtime is
grouped.

```
NOTES.md          bench notes: commands, logs, every diagnostic field
README.md         this file
collect_logs.sh   save a run into logs/

vlc_transceiver_bridge.py   the v2 transceiver bridge (current)
vlc_rx_bridge.py            legacy receive-only bridge
vlc_stm32_tx_bridge.py      legacy STM32 TX bridge
vlc_host_protocol.py        host <-> STM32 framing
vlc_capture.py              RX capture validation and writing
vlc_pacing.py               transmit pacing
vlc_udp_pacer.py            UDP pacing helper

docs/       operations notes
install/    install_*.sh and setup_*.sh
systemd/    unit and default files
tools/      diagnostics, link tests, video helpers
tests/      unittest, no hardware needed
logs/       all bench output; not tracked
```

**Start with [NOTES.md](NOTES.md)** if you are at the bench: it has the
commands, how to enable and save logs, and the meaning of every field in the
`COMP`, `TX` and `trx-bridge` lines.

Run the tests with:

```bash
python -m unittest discover -s tests -t .
```

## Physical connections

Power all boards off before changing the optical-front-end wiring.

### Transmitter side

```text
USB webcam
  -> TX Raspberry Pi USB

TX Raspberry Pi USB
  -> STM32 TX ST-Link virtual COM port (USART3 PD8/PD9)

STM32 TX PB4
  -> existing OpenVLC LED-driver modulation input

STM32 TX PB5
  -> OpenVLC PCB P8_46-equivalent auxiliary LED branch
  -> hold low continuously; it is not the frame enable

TX frontend hardware-enable strap
  -> 3.3 V

STM32 TX GND
  -> TX frontend GND
```

Do not drive the LED directly from `PB4`. Keep the known-working OpenVLC
driver, current limiting, and power supply. On the current TX PCB, `PB4`
replaces BBB `P8_45` and carries all OOK data. `PB5` replaces BBB `P8_46`,
which drives a second LED-current branch; keep it low exactly like
`OPENVLC_TX_ENABLE_MODE=0`. The physically swapped `P9_26` position carries
`PS_ON` and must be held at `3.3 V` to power the frontend.

### Receiver side

```text
photodiode / AGC frontend output, limited to 0..3.3 V
  -> NUCLEO-H743ZI2 PB2 / COMP1_INP

receiver frontend GND
  -> Nucleo GND

Nucleo ST-Link USB connector
  -> RX Raspberry Pi USB

RX Raspberry Pi HDMI
  -> display
```

The ST-Link USB connection powers the Nucleo if its jumper configuration is
unchanged and exposes USART3 as `/dev/ttyACM*`. No separate UART wires are
required. PC5 carries the external COMP1 output and may be connected to an
oscilloscope probe for diagnostics; it is not connected to the Raspberry Pi.

Never apply the unscaled frontend voltage to PB2. Verify the waveform remains
inside the STM32 input range before connecting it.

## Components

| File | Host | Purpose |
|---|---|---|
| `vlc_stm32_tx_bridge.py` | TX Raspberry Pi | Read IP datagrams from `tun0`, frame them, and write them to STM32 TX over USART |
| `vlc_stm32_tx_serial_test.py` | TX Raspberry Pi | Send valid frames directly over USART, bypassing TUN/routes |
| `install/install_tx_stm32_service.sh` | TX Raspberry Pi | Install and start the STM32 TX bridge as a systemd service |
| `setup_stm32_tx_pi.sh` | TX Raspberry Pi | Run the STM32 TX bridge in the foreground for debug |
| `tools/vlc_tx_video.sh` | TX Raspberry Pi | Capture and encode the webcam into a bounded UDP MPEG-TS stream |
| `vlc_rx_bridge.py` | RX Raspberry Pi | Parse STM32 records, validate IP packets, and inject them into `tun0` |
| `install/install_rx_service.sh` | RX Raspberry Pi | Install and start the bridge as a systemd service |
| `vlc_rx_view.sh` | RX Raspberry Pi | Display the UDP video stream |
| `tools/vlc_link_test.sh` | both sides | Measure one-way UDP goodput and loss with iperf2 |

The legacy BBB TX scripts are kept for comparison and fallback only. Do not use
them in the final STM32-TX path.

## Network plan

| Interface | Address | MTU |
|---|---:|---:|
| TX Pi `tun0` | `192.168.0.1/24` | `900` |
| RX Pi `tun0` | `192.168.0.2/24` | kernel TUN |

The OpenVLC STM32 payload limit is 900 bytes. The video scripts use a 752-byte
UDP payload, which produces a 780-byte IPv4 datagram and avoids fragmentation.
The validated budget-50 link has delivered roughly 0.8-1.0 Mbit/s under iperf2
with approximately zero steady-state loss after startup when the optical path is
clean. The stable video profile intentionally uses a 650 kbit/s MPEG-TS rate to
retain margin for scheduling jitter and protocol overhead.

## 1. STM32 receiver profile

The desktop GUI in `../control-app` can run the same setup scripts, monitor the
RX bridge, start iperf, and display the STM32 link-quality metric. Use the
commands below when operating manually or when debugging the GUI's remote
actions.

The companion profile in `Core/Inc/openvlc_board.h` uses:

```c
#define OPENVLC_RX_HOST_FORWARD 1
#define OPENVLC_HOST_UART_BAUD 2000000u
```

USART3 is the NUCLEO ST-Link virtual COM port on PD8/PD9. Connect the NUCLEO
USB debug port to the RX Raspberry Pi and identify the device:

```bash
ls -l /dev/ttyACM*
```

The decoder remains COMP1 plus TIM2 input capture. Host records are queued
during packet decoding. TIM2/DMA is restarted before USART transmission, so a
large IP packet no longer extends the receiver blind interval.

Flash `communications/openvlc/stm32-rx/STM32CubeIDE/Debug/stm32.elf` with
STM32CubeIDE or the ST-Link programmer before installing the Raspberry bridge.

## 2. STM32 transmitter

Build and flash:

```text
communications/openvlc/stm32-tx/STM32CubeIDE/Debug/stm32-tx.elf
```

The default firmware profile is budget 40, with USART3 host mode at 2 Mbit/s.
The Raspberry TX bridge sends IP datagrams over that serial link using the same
host-frame CRC format used by the STM32 RX bridge.

Install the bridge on the TX Raspberry Pi:

```bash
cd communications/openvlc/raspberry-gateway
sudo bash ./install/install_tx_stm32_service.sh
sudo systemctl status openvlc-tx-stm32
```

For foreground debug instead of systemd:

```bash
cd communications/openvlc/raspberry-gateway
sudo bash ./install/setup_stm32_tx_pi.sh
```

After the bridge starts, traffic sent to `192.168.0.2` leaves through `tun0`,
is framed on USART3, and is transmitted by the STM32.

The bridge installs an explicit `192.168.0.2/32` route on `tun0`. This replaces
any stale route through `eth0` left by the legacy BBB topology. Verify:

```bash
ip route get 192.168.0.2
```

The first line must contain `dev tun0 src 192.168.0.1`.

## 2b. Legacy BeagleBone transmitter

The former BBB path is still useful as a reference transmitter. Copy or clone
the repository on the BBB, then run:

```bash
cd communications/openvlc/raspberry-gateway
bash ./install/setup_bbb_tx_router.sh
```

The script supports both repository layouts:

- `communications/openvlc/{raspberry-gateway,beaglebone-reference}`;
- `~/beaglebone-reference/raspberry-gateway`.

It writes the PRU build profile to `/run/openvlc-tx-profile`. The statistics
script reports a warning when this marker is missing, because the kernel module
parameters do not contain the PRU symbol wait budget.

The script loads this known TX profile:

```text
OPENVLC_PREAMBLE_LEN=8
OPENVLC_PREAMBLE_MODE=0
OPENVLC_TX_LINE_CODE=1
OPENVLC_TX_ENABLE_MODE=0
OPENVLC_TX_SYMBOL_WAIT_BUDGET=50
rx=0 self_id=7 dst_id=8 pool_size=50
```

Override `PI_IF` if the Ethernet interface connected to the TX Pi is not
`eth0`.

This must be paired with `OPENVLC_PHY_RATE_KBPS=1000` in the STM32 firmware.
The STM32 boot line is the authority: verify it prints `rate=1000k` before
testing this budget-50 profile.
The setup script also replaces any TBF left by capacity experiments with a
small FIFO. Do not leave a manual `650kbit` TBF active: FFmpeg now performs
constant-rate MPEG-TS pacing itself.

The experimental budget-40 profile uses
`beaglebone-tx/TX_setup_budget40.sh` and must be paired with
`OPENVLC_PHY_RATE_KBPS=1250` on the STM32. The corresponding boot line is
`rate=1250k`. Keep video on the validated budget-50 profile until the
budget-40 iperf procedure passes without growing BBB queues, STM32
`ringdrop`/`hostdrop`, or bridge sequence gaps.

## 3. TX Raspberry Pi traffic generation

Install the runtime and verify the STM32 TX TUN route:

```bash
sudo apt install ffmpeg iperf v4l-utils iproute2
cd communications/openvlc/raspberry-gateway
sudo systemctl status openvlc-tx-stm32
ip route get 192.168.0.2
v4l2-ctl --list-formats-ext -d /dev/video0
```

Start the stable profile:

```bash
INPUT_FORMAT=mjpeg SIZE=640x360 FPS=15 \
  OUT_SIZE=640x360 OUT_FPS=15 \
  BITRATE=500k MUXRATE=650k \
  bash ./tools/vlc_tx_video.sh
```

For the Logitech C270 this is a native mode, so FFmpeg does not need a scaling
stage. For more detail at the same frame rate:

```bash
INPUT_FORMAT=mjpeg SIZE=864x480 FPS=15 \
  OUT_SIZE=864x480 OUT_FPS=15 \
  RATE_MODE=capped-crf CRF=24 \
  BITRATE=680k BUFSIZE=220k MUXRATE=800k \
  bash ./tools/vlc_tx_video.sh
```

`BITRATE` controls the H.264 elementary stream. `MUXRATE` controls the actual
constant-rate MPEG-TS stream and must be higher than `BITRATE`. The remaining
rate carries TS headers, repeated PAT/PMT, PCR, and null packets. Constant-rate
muxing avoids delivering a whole video frame to the BBB as a short packet
burst. The FFmpeg UDP output is additionally rate-limited to `MUXRATE` with a
one-datagram burst allowance, so the 752-byte packets are distributed across
time instead of being released together. This keeps driver queues and the
optical AGC operating steadily.

With `MUXRATE=650k` and `PKT=752`, the sender emits approximately 108 UDP
datagrams per second. Including the 28-byte IPv4/UDP header, the BBB receives
about 674 kbit/s of network data. The STM32 host record adds 11 bytes and UART
8N1 framing, consuming about 855 kbit/s on the 2 Mbaud companion link. Both
figures remain below their measured limits.

The encoder uses:

- H.264 Baseline without B-frames;
- one IDR per second;
- repeated codec and MPEG-TS headers;
- slices bounded to approximately 600 bytes;
- 752-byte UDP payloads;
- a 250 kbit VBV buffer;
- a 600 ms MPEG-TS decode delay so DTS remains ahead of PCR during IDR
  bursts;
- square output pixels, preventing camera sample-aspect-ratio metadata from
  turning a 640x360 stream into a 4:3 display image.

These settings limit the visible effect of a lost datagram and allow the
decoder to recover at the next IDR without restarting the stream.
The decode delay is deliberately larger than `BUFSIZE / MUXRATE`
(`250 kbit / 650 kbit/s`, approximately 385 ms). A smaller delay can make the
constant-rate PCR overtake an IDR packet DTS, producing FFmpeg's
`dts < pcr, TS is invalid` warning. Override `MUXDELAY` only together with
`BUFSIZE`; lowering it reduces latency but also reduces the permitted encoder
burst margin.

## 4. RX Raspberry Pi

Install and start the bridge:

```bash
cd communications/openvlc/raspberry-gateway
sudo bash ./install/install_rx_service.sh
journalctl -u openvlc-rx -f
ip address show tun0
```

The default `OPENVLC_SERIAL_PORT=auto` prefers the stable ST-Link path under
`/dev/serial/by-id`. Existing installations may still contain
`/dev/ttyACM0`; change them to `auto` or the exact by-id path:

```bash
sudo sed -i 's|^OPENVLC_SERIAL_PORT=.*|OPENVLC_SERIAL_PORT=auto|' \
  /etc/default/openvlc-rx
sudo systemctl restart openvlc-rx
```

For the `stm32-transceiver-pi-hat` GPIO-UART variant, do not use `auto`: an
attached ST-LINK can otherwise be selected instead of the HAT UART. Enable the
hardware serial port, disable the serial console, reboot, then install with:

```bash
sudo ./install/install_transceiver_service.sh --pi-hat            # node derived from the hostname
# or, if the host is not named nodeX: --node b --peer 192.168.0.1
```

This sets `OPENVLC_SERIAL_PORT=/dev/serial0` and runs the 2 Mbaud PL011
preflight in `tools/check_pi_hat_uart.sh` before starting the service.

The full-duplex bridge also sets `OPENVLC_TX_MAX_FPS=125`. This is a maximum,
not a traffic generator: lower-rate traffic passes immediately, while a burst
of queued iperf datagrams is released to the STM32 at one record every 8 ms.
Late Linux scheduling never causes a catch-up burst. Set the value to `0` only
for an explicit unpaced stress test; normal Pi-HAT operation should retain
`125`.

The bridge also installs `10.0.0.0/24 dev tun0`. This makes Linux reverse-path
validation consistent with packets whose source is the TX Raspberry Pi. Change
`OPENVLC_SOURCE_ROUTE` if the Ethernet subnet between the TX Pi and BBB differs.

For foreground diagnostics:

```bash
sudo systemctl stop openvlc-rx
sudo python3 ./vlc_rx_bridge.py --port /dev/ttyACM0 --baud 2000000
```

Start the viewer in another terminal:

```bash
bash ./vlc_rx_view.sh
```

The default `MODE=stable` allows approximately 500 ms of receiver buffering.
This absorbs normal packet and scheduling jitter. For latency experiments:

```bash
MODE=low-latency bash ./vlc_rx_view.sh
```

Use the low-latency mode only after the stable profile is clean; zero-buffer
playback makes a single late datagram visible even when no packet was lost.

The bridge reports:

- current five-second bitrate and packet rate;
- cumulative accepted IP frames and average bitrate;
- STM32 record sequence gaps;
- serial CRC failures;
- malformed or oversized records;
- invalid IP datagrams and TUN write errors.
- RX capture records, saved captures and rejected captures as
  `cap=records/saved/errors`.

The STM32 `COMP` diagnostic also reports `hostq`, `hostsent`, `hostdrop`, and
`hosterr`. Nonzero `hostdrop` or `hosterr` identifies the companion transport
rather than the optical decoder as the loss point.

With `OPENVLC_RX_CAPTURE=1` in the STM32 firmware, the bridge saves qualified
successful and failed comparator bursts under `logs/captures`.
The default firmware quotas are 32 `-ok` files and 32 classified failure files
(`-crc`, `-sync`, `-length` or `-decode`). Set
`OPENVLC_CAPTURE_NODE=node-a` or `node-b` in
`/etc/default/openvlc-transceiver` so files from the two receivers remain
distinct.

## 5. Measure capacity before video

On the RX Pi:

```bash
ROLE=rx bash ./tools/vlc_link_test.sh
```

On the TX Pi:

```bash
RATE=100k bash ./tools/vlc_link_test.sh
RATE=150k bash ./tools/vlc_link_test.sh
RATE=200k bash ./tools/vlc_link_test.sh
```

Increase further only after the previous step is stable. The current
budget-50 profile has been validated up to roughly a 1 Mbit/s offered iperf2
stream on clean hardware, but the stable capacity is a measured property of the
current optical alignment, AGC/threshold point, and host load. The first iperf
interval can report old sequence numbers if the receiver was started after the
sender; assess steady-state intervals after both bridge and server are already
running.

For budget 40, begin at `800k` and step through `900k`, `950k`, `1000k`, and
`1050k`. A valid step requires steady-state UDP loss below 1%, BBB
`pru_completed` tracking enqueue, and no increase in STM32 `hostdrop`,
`hosterr`, or `ringdrop`. Stop at the first sustained failure; do not infer
capacity from a one-second interval.

While a test is running, inspect the BBB in another terminal:

```bash
WINDOW=10 bash ./vlc_bbb_tx_stats.sh
```

The updated driver exports read-only TX service counters under
`/sys/module/vlc/parameters/`. The script reports:

```text
enqueued_by_driver     packets accepted into the OpenVLC MAC queue
encoded                frames prepared by the Linux worker
pru_started            frames submitted to PRU1
pru_completed          frames whose final optical symbol was emitted
optical_completed      completed network bytes per second
queue_depth            current software backlog
backpressure_events    netdev stops caused by an exhausted packet pool
```

For a sustainable offered load, `pru_completed` should approximately equal
`tx_packets`, queue depth must not trend upward, `backlog_delta` should stay
near zero, and `backpressure_events` should remain zero. Compare
`optical_completed` with the RX bridge rate.

- low BBB rate or increasing `tx_dropped`: BBB queue/CPU/TX service bottleneck;
- `new_queue_warnings` above zero: the PRU path is applying backpressure during
  the measurement; do not interpret `enqueued_by_driver` as air goodput;
- high BBB enqueue rate, no new queue warnings, but low STM32 `ok/seen`: optical
  acquisition/demodulation loss;
- STM32 `ok` rises but bridge `seq_gap`, `hostdrop`, or `hosterr` rises:
  companion UART/queue loss.
- enqueue exceeds `optical_completed` and queue depth grows: BBB TX service is
  saturated before the optical receiver.

For a clean run, compare rates over the same time window:

```text
BBB packet_rate ~= STM32 delta(seen)/seconds
STM32 delta(ok)/delta(seen) = optical frame success ratio
bridge delta(ip)/seconds ~= STM32 delta(ok)/seconds
```

If the first equality fails, frames are being delayed before the receiver or
multiple frames are merging into one capture burst. If the second ratio is
poor, the loss is in edge acquisition/PHY decode. If the third equality fails,
the loss is in the STM32 host queue, serial protocol, or Pi bridge.

The STM32 budget-50 profile uses a `4 us` edge-idle delimiter. This is much
longer than the maximum normal Manchester edge interval but shorter than the
BBB software service gap between queued frames. Keep this value matched to the
current timing profile; a delimiter that is too long merges adjacent frames
and creates a load-dependent goodput plateau even when individual packets
decode correctly.

For stable video, keep `MUXRATE=650k` until a complete video run shows all of:

```text
BBB queue_depth remains near zero
BBB backpressure_events remains zero
STM32 hostdrop and hosterr remain zero
bridge gap, crc, invalid_ip, and tunerr remain zero
```

The H.264 `BITRATE` is not the link rate. Keep it below `MUXRATE`; keep
`MUXRATE` below the measured UDP goodput.

### Higher-quality 1 Mbit/s link profile

After the optical link sustains a `1000k` iperf2 stream without internal
queue or receiver drops, use this as the first quality upgrade:

```bash
cd communications/openvlc/raspberry-gateway
bash ./tools/vlc_tx_video_quality.sh
```

The launcher is equivalent to:

```bash
INPUT_FORMAT=mjpeg SIZE=640x360 FPS=20 \
  OUT_SIZE=640x360 OUT_FPS=20 \
  RATE_MODE=capped-crf CRF=21 PRESET=veryfast H264_PROFILE=main \
  BITRATE=720k BUFSIZE=220k MUXRATE=900k \
  bash ./tools/vlc_tx_video.sh
```

`RATE_MODE=capped-crf` lets x264 use lower quantization on frames that benefit
from it while `BITRATE` remains a hard maximum. Lower `CRF` means less
quantization and a sharper image; it does not override the maximum bitrate.
Values below about 19 are usually ineffective on this link because complex
scenes immediately reach the `720k` cap.

`PRESET=veryfast` spends more Pi CPU to obtain better quality per transmitted
bit than the original `ultrafast` profile. `H264_PROFILE=main` enables CABAC,
which also improves compression efficiency; B-frames remain disabled, so the
encoder does not add frame-reordering latency. Confirm FFmpeg reports
`speed` close to or above `1.0x`. If encoding cannot run in real time, use
`PRESET=superfast` or return to `OUT_FPS=15`.

At `MUXRATE=900k` and `PKT=752`, UDP/IP traffic entering the BBB is about
934 kbit/s. Use this only after iperf shows a clean 1 Mbit/s-class link. It
also remains within the 2 Mbaud STM32 companion link.

For more spatial resolution instead of more motion resolution, try:

```bash
INPUT_FORMAT=mjpeg SIZE=1280x720 FPS=15 \
  OUT_SIZE=854x480 OUT_FPS=15 \
  RATE_MODE=capped-crf CRF=22 PRESET=veryfast H264_PROFILE=main \
  BITRATE=740k BUFSIZE=370k MUXRATE=900k \
  bash ./tools/vlc_tx_video.sh
```

Use this second profile only if the camera advertises the requested MJPEG
capture mode. At this link rate, `854x480@15` and `640x360@20` are reasonable
alternatives; attempting 720p together with higher frame rate generally
increases quantization and looks softer despite the larger frame dimensions.

## Recommended startup order

1. Power the optical TX and RX frontends and verify alignment.
2. Connect and boot the RX Nucleo and RX Raspberry Pi.
3. Start `openvlc-rx.service` and verify that `tun0` exists.
4. Boot the BBB and run `install/setup_bbb_tx_router.sh`.
5. Boot the TX Raspberry Pi and run `install/setup_tx_pi.sh`.
6. Run the one-way iperf2 test before starting video.
7. Start `vlc_rx_view.sh` on the RX Pi and leave it waiting.
8. Start `tools/vlc_tx_video.sh` on the TX Pi.

## Stable video acceptance test

Run the following profile for at least ten minutes:

```bash
# RX Pi
journalctl -u openvlc-rx -f
```

```bash
# RX Pi, second terminal
MODE=stable bash ./vlc_rx_view.sh
```

```bash
# BBB
WINDOW=600 bash ~/raspberry/vlc_bbb_tx_stats.sh
```

```bash
# TX Pi
INPUT_FORMAT=mjpeg SIZE=640x360 FPS=15 \
  OUT_SIZE=640x360 OUT_FPS=15 \
  BITRATE=500k MUXRATE=650k \
  bash ./tools/vlc_tx_video.sh
```

Accept the profile only when the image remains continuous and the counters
listed above stay at zero. If the bridge is clean but the display still
stutters, the problem is player/decoder scheduling; increase receiver margin
with `FIFO_SIZE=131072`. If bridge gaps rise, fix the serial/STM32 path. If BBB
backpressure rises, lower `MUXRATE` to `600k`.

## STM32 host record format

All multibyte fields are big-endian:

```text
A5 5A C3
version      1 byte, currently 1
type         1 byte: 1 = IP datagram, 2 = UTF-8 log
sequence     2 bytes
length       2 bytes
payload      length bytes
CRC-16       2 bytes
```

CRC-16/CCITT-FALSE covers `version` through the end of `payload`. Sequence
numbers make queue drops, UART losses, and parser resynchronization visible.
The bridge can accept the previous payload-only-CRC format with
`--accept-legacy`, but the current firmware uses the format above.

## Failure isolation

1. `tun0` missing: inspect `systemctl status openvlc-rx`.
2. Serial CRC or sequence gaps rising: verify both sides use 2,000,000 baud and
   test a shorter USB cable or a direct UART designed for that baud rate.
3. Valid serial frames but no IP frames: inspect `invalid_ip` and confirm the
   BBB sends datagrams no larger than 900 bytes.
4. IP packets arrive but applications see nothing: verify
   `ip route get 10.0.0.2` selects `tun0` and check the RX Pi firewall.
5. IP packets arrive but video does not start: lower the encoder bitrate, wait
   for the next keyframe, and inspect the UDP stream with `tcpdump -ni tun0`.
6. Optical `sync` failures rise: solve the COMP1/AGC/timing issue before tuning
   ffmpeg; the companion path cannot repair an undecoded optical frame.
7. Direct BBB traffic turns on the LED but TX Pi traffic does not: this is a
   BBB forwarding problem, not an optical problem. Re-run both setup scripts,
   then inspect the first `FORWARD` rule and both interfaces:

   ```bash
   # TX Pi
   ip route get 192.168.0.2
   ping -c 2 10.0.0.1

   # BBB
   sysctl net.ipv4.ip_forward
   sudo iptables -nvL FORWARD --line-numbers
   sudo tcpdump -ni eth0 udp port 10001
   sudo tcpdump -ni vlc0 udp port 10001
   ```

   The TX Pi route must explicitly contain `via 10.0.0.1`. The setup script
   installs a `192.168.0.2/32` host route so it takes priority over any
   DHCP/VPN route using the same `192.168.0.0/24` subnet. It also removes a
   stale local `10.0.0.1` address, which can remain if the BBB router setup was
   accidentally executed on the TX Pi.

   The packet counter on the first `eth0 -> vlc0 ACCEPT` rule must increase.
   Packets visible on BBB `eth0` but absent from `vlc0` indicate routing or
   firewall rejection. Packets absent from BBB `eth0` indicate the TX Pi route,
   cable, or interface name is wrong.

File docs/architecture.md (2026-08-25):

# Sunrise Architecture

Sunrise integrates a visible-light communication link into a drone platform.
The repository is split so mechanical design, simulations, drone software, and communication firmware can evolve independently while still sharing one system-level view.

```mermaid
flowchart TB
  drone["Drone platform"]
  mech["Mechanical design\nInventor parts, mounts, optical alignment"]
  sim["Simulations\noptical channel, motion, link budget"]
  sw["Drone software\ntelemetry, commands, health monitoring"]
  comm["Communications\nOpenVLC, BeagleBone, STM32"]

  drone --> mech
  drone --> sim
  drone --> sw
  drone --> comm

  comm --> bbb["BeagleBone Black prototype"]
  comm --> stm["STM32 target"]
  comm --> docs["PHY/MAC documentation"]
```

## Communication Prototype

The current working link combines two implementations:

```text
communications/openvlc/beaglebone_black/  network-facing TX
communications/openvlc/stm32/             embedded RX
```

Its end-to-end architecture is:

```text
Linux application
  -> Linux network stack
  -> BeagleBone OpenVLC kernel driver
  -> PRU1 OOK / Manchester transmitter
  -> LED and visible-light channel
  -> photodiode / AGC frontend
  -> STM32 COMP1 hardware slicing
  -> TIM2 CH4 both-edge input capture
  -> DMA edge timestamp ring
  -> preamble-gated SFD synchronization
  -> Manchester and physical-length recovery
  -> Reed-Solomon validation
  -> STM32 packet callback
```

The platform-specific details are documented in:

- [`../communications/openvlc/beaglebone_black/docs/architecture.md`](../communications/openvlc/beaglebone_black/docs/architecture.md);
- [`../communications/openvlc/stm32/docs/architecture.md`](../communications/openvlc/stm32/docs/architecture.md).

## STM32 Receiver

The STM32 receiver reuses the BBB frame format, raw alternating preamble,
Manchester coding, SFD, physical-length semantics, and Reed-Solomon layout. It
does not copy the Linux/PRU runtime structure.

The active receive path is:

```text
scaled AGC/Vin on PB2
  -> COMP1 with DAC1_CH1 threshold and hysteresis
  -> TIM2 CH4 input capture at 16 MHz
  -> DMA edge timestamps
  -> burst and short-pulse validation
  -> single/double interval timing recovery
  -> alternating-preamble gate
  -> exact or inverse SFD match
  -> Manchester pair recovery
  -> length, bounds, completeness, and alignment checks
  -> Reed-Solomon block validation
  -> packet delivery
```

The active STM32 receiver does not use ADC sampling or a matched filter.
Comparator edge/glitch rates, normalized edge-timing residuals, Manchester
pair errors, timing outliers, Reed-Solomon corrections, and a combined
link-quality indicator are reported as diagnostics; they do not replace final
packet integrity checks.

The complete acceptance sequence and counter semantics are specified in
[`../communications/openvlc/stm32/docs/packet_validation.md`](../communications/openvlc/stm32/docs/packet_validation.md).

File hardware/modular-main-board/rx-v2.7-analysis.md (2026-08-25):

# PCB_RX_V2.7 schematic analysis

Scope: latest RX design in `communications/openvlc/hardware/rx/PCB_RX_V2.7`.

Primary sources inspected:

- `PCB_RX.SchDoc`
- `PCB_RX.PcbDoc`
- `P-17464_2025-12-13_IMDEA_PCB_RX_V2.7.zip`
- STM32 RX documentation in `communications/openvlc/stm32-rx/docs/`
- BeagleBone hardware notes in
  `communications/openvlc/beaglebone-reference/docs/hardware/README.md`

## Executive conclusion

`PCB_RX_V2.7` is a capable analog optical front-end, but it is still shaped as
a BeagleBone/OpenVLC cape-era board. For the new modular architecture, it should
not be copied as-is. The main improvements are:

1. Remove BeagleBone P8/P9 dependency from the RX module.
2. Define a clean RX module connector around the actual chosen system boundary.
3. Keep the photodiode, first low-noise stage, AGC/filtering, and final
   slicer/ADC close together on the RX module.
4. Rework power so analog rails are quiet and separated from TX current loops.
5. Decide whether the final product uses the current STM32 comparator path or
   keeps legacy external ADC/SPI support.

The current STM32 receiver baseline does **not** use the external `ADS7886`
SPI ADC path. It uses a conditioned analog AGC/Vin signal into STM32 `PB2 /
COMP1_INP`, sliced against the STM32 DAC threshold and timestamped by `TIM2`.
That means the new RX module can be simpler than `PCB_RX_V2.7` if STM32 is the
target.

## Observed RX blocks

Extracted from the Altium schematic records:

| Block | Components / nets observed |
| --- | --- |
| Optical input | `PD` = `SFH213` photodiode |
| Low-noise input | `U1` = `ADA4817-2ACPZ-RL`, nets including `+IP`, `-IP`, `+VT`, `-VT`, `+VB`, `-VB`, `+eOP`, `-eOP` |
| Variable gain / AGC | `U1C` = `AD8338ACPZ-R7`, nets `VAGC`, `GAIN_OUT`, `MODE`, `OFSN`, `VREF` |
| Filter/gain stages | `U2C` = `OPA863ADBVR`, `U2`/`U?` = `AD8066ARZ-R7`, nets `LNA_P/N`, `BPF_P/N`, `LPF_IN/OUT` |
| Differential / ADC driver | `U1I` = `AD8139ARDZ-REEL` |
| External ADC | `ADC` = `ADS7886SBDBVR`, nets `ADC_IN`, `CS_PD`, `MISO_PD`, `MOSI_PD` |
| Analog rails | `+5V`, `-5V`, `VCC`, `GND`; `U1B` = `LM2663M/NOPB` charge pump; `U1A` = `TLV76150DCYR` |
| Legacy host interface | `P8`, `P9` = BeagleBone headers, plus pin-swap notes |
| Debug/tuning | Many 2-pin/3-pin headers and 50 k trimmers around bias, threshold and gain stages |

Board size from Gerber extents: approximately `85.0 mm x 54.6 mm`.

## Fit against the current STM32 receiver

The active STM32 firmware path is:

```text
photodiode / analog frontend / AGC
  -> voltage-limited AGC/Vin
  -> STM32 PB2 / COMP1_INP
  -> COMP1
  -> TIM2 input capture
  -> edge-timing decoder
```

The STM32 docs explicitly say the current comparator path does not use the
external ADC `SDO/MISO` line. Therefore, `ADS7886`, its SPI wiring, and part of
the BeagleBone header interface are legacy compatibility features, not required
for the current STM32 baseline.

## Recommended RX module boundary

### Preferred boundary for the new modular system

Keep on `RX_MODULE`:

- Photodiode and mechanical/optical alignment.
- First low-noise transimpedance/front-end amplifier.
- AGC or fixed-gain conditioning required to produce a clean waveform.
- Comparator/slicer **or** ADC, depending on final acquisition architecture.
- Local analog reference filtering and final output protection.

Move to `MAIN_BOARD`:

- BeagleBone P8/P9 headers.
- STM32/Pi/host interface.
- Bulk power conversion and protection.
- Service/debug connectors that do not need to live beside the photodiode.

For the STM32 comparator baseline, the best module output is either:

```text
RX_ANALOG_OUT_0V3V3 -> STM32 PB2 / COMP1_INP
```

or:

```text
RX_DIGITAL_EDGE -> STM32 timer/capture-capable GPIO
```

The first option keeps threshold control in STM32 DAC/COMP1. The second option
puts the comparator on the RX module and exports a digital edge stream.

### Compatibility boundary

If compatibility with BeagleBone ADC/SPI receive is still needed, keep the ADC
on the RX module and export digital SPI:

```text
RX_SPI_SCK
RX_SPI_MISO
RX_SPI_MOSI
RX_CS
RX_DRDY or RX_SAMPLE_CLK if added
```

Do **not** export a high-impedance analog photodiode/TIA node across the module
connector.

## Concrete improvements

### 1. Remove direct BeagleBone cape dependency

Current `P8`/`P9` headers and pin-swap notes are a source of confusion and
miswiring risk. Replace them with a purpose-built RX connector:

- Explicit signal names.
- Ground pins interleaved with fast or sensitive signals.
- Separate analog and digital return pins.
- Keyed/locking connector, not ambiguous 2.54 mm cape header orientation.

This is the highest-value schematic cleanup for modularity.

### 2. Decide ADC vs comparator now

There are two credible product directions:

| Direction | Keep | Remove/simplify |
| --- | --- | --- |
| STM32 comparator baseline | analog conditioning to `0..3.3 V` or module comparator output | external `ADS7886` path, BeagleBone SPI header dependency |
| Legacy/diagnostic ADC support | `ADS7886` and SPI boundary | BeagleBone P8/P9 physical header; still use modular SPI connector |

For the current firmware, the comparator baseline is simpler, lower latency, and
already validated in software.

### 3. Rework negative rail generation

`LM2663` charge pump on the RX board is convenient, but it is a switching noise
source close to sensitive analog circuitry. Better options:

- Provide `+5VA` and `-5VA` from the main board through filtered analog power
  pins, then add local ferrite/RC/LC filtering on RX.
- Or keep `LM2663` on RX but put it in a physically isolated power island with
  local return, shield copper/guard spacing, and post-filtering before the
  amplifier rails.

For the modular main board, the first option is cleaner if the connector and
layout can keep analog rails quiet.

### 4. Add a proper STM32-safe output stage

The current docs require scaling AGC/Vin before STM32 `PB2`:

```text
frontend AGC/Vin -> divider or buffer -> PB2 / COMP1_INP
```

Make this a defined part of the new RX schematic, not a bring-up workaround:

- Output range target: normally below `3.0 V`, absolute normal-use below
  `3.3 V`.
- Add series resistor near the RX module output.
- Add clamp/protection compatible with STM32 analog input leakage and bandwidth.
- Add optional RC footprint for edge/noise shaping.
- Label this net clearly as `RX_COMP_IN_0V3V3` or `RX_ANALOG_OUT_0V3V3`.

### 5. Reduce manual trimmers

The schematic contains several 50 k trimmers and debug headers around bias,
gain, and threshold points. They are useful on a lab board but not ideal for a
repeatable modular design.

Recommended approach:

- Keep footprints for one bring-up revision, but add fixed resistor population
  options.
- Move threshold control to STM32 DAC where possible.
- For gain/AGC control, prefer a DAC or digitally controlled setting from the
  main board if runtime adaptation is desired.
- Document default BOM values and DNP variants.

### 6. Clean annotation and BOM semantics

Items to fix before layout release:

- `U?` exists for an `AD8066ARZ-R7` block. This must be annotated.
- Multiple `U1`/`U2` entries appear as multipart symbols; verify Altium
  packaging maps exactly to the intended physical ICs.
- Connector/testpoint designators such as `5V`, `GND`, `DIFF` are readable on
  the schematic, but they are not ideal BOM designators. Prefer `Jx`/`TPx`.
- Many passives have comments `Cap` or `Res1`; ensure actual values are stored
  in visible BOM parameters before producing procurement data.

### 7. Make analog/digital grounding explicit

The RX module should have one controlled ground strategy:

- Continuous ground plane under the analog chain.
- No high-current TX return under or through the RX module.
- Digital return for SPI/control tied near ADC/comparator boundary.
- Guard/keepout around the photodiode and TIA summing node.
- Connector pinout should include several adjacent grounds near `RX_ANALOG_OUT`,
  `RX_SPI_SCK`, and `RX_CS`.

Avoid hard split planes that force return currents through narrow bridges, but
do keep placement/routing zones physically separate.

### 8. Add measurement points without adding antennas

Keep testability, but reduce stubs on sensitive nodes:

- Use high-impedance or coax-compatible test points for `RX_ANALOG_OUT`.
- Keep direct test points off the photodiode/TIA summing node unless guarded and
  very short.
- Add safe low-bandwidth monitor outputs for `VAGC`, `VREF`, `GAIN_OUT`, and
  module rail health.

## Proposed RX connector for STM32 comparator baseline

Suggested minimum pin groups:

| Group | Signals |
| --- | --- |
| Analog power | `+5VA`, `-5VA`, `AGND` |
| Digital/control power | `+3V3D` or `+5VD`, `DGND` |
| Output | `RX_ANALOG_OUT_0V3V3` or `RX_DIGITAL_EDGE` |
| Control | `RX_EN`, `RX_GAIN_CTRL` or `VAGC_DAC`, optional `RX_MODE` |
| Reference/monitor | `VREF_MON`, `GAIN_OUT_MON`, optional `RSSI` |
| Service | `I2C` or spare GPIO only if needed |

Use ground pins around the output and any control clocks.

## Proposed RX connector for ADC-compatible module

| Group | Signals |
| --- | --- |
| Analog power | `+5VA`, `-5VA`, `AGND` |
| Digital power | `+3V3D`, `DGND` |
| SPI | `RX_SPI_SCK`, `RX_SPI_MISO`, `RX_SPI_MOSI`, `RX_CS` |
| Timing | optional `RX_DRDY`, `RX_SAMPLE_CLK` |
| Monitor | `RX_ANALOG_OUT_0V3V3`, `VREF_MON`, `GAIN_OUT_MON` |
| Control | `RX_EN`, `RX_MODE`, gain/AGC control |

This keeps analog acquisition local to the RX module and exports digital data
to the main board.

## Recommended architecture choice

For the system described by the current STM32 docs, choose this:

```text
RX_MODULE:
  photodiode -> TIA/LNA -> AGC/filter -> protected 0..3.3 V analog output

MAIN_BOARD:
  STM32 PB2/COMP1 + DAC threshold + TIM2 capture
```

Add an optional comparator footprint on the RX module only if field testing
shows that the analog cable/module connector degrades edge timing.

Keep `ADS7886` only if you explicitly need BeagleBone PRU ADC compatibility or
want sampled diagnostic data. Otherwise it is extra complexity for the current
receiver.

## Validation checklist for the next revision

- RX module output never exceeds STM32 input limits under dark, ambient, aligned
  TX, saturated TX, and hot/cold conditions.
- Comparator threshold has a stable plateau; best DAC code does not sit at an
  endpoint.
- `glitchps` stays low with TX off and with ambient-light changes.
- Link score improves or remains stable versus `PCB_RX_V2.7`.
- TX high-current switching does not move RX baseline measurably.
- `+5VA`, `-5VA`, and `VREF` ripple are measured with TX active.
- Module connector orientation and pin 1 are unambiguous in schematic, PCB, and
  silkscreen.

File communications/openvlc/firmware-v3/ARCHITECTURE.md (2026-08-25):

# STM32H723 Pi HAT transceiver architecture

## Active hardware data paths

| Resource | Purpose |
|---|---|
| PB0 -> COMP1 IN+ | optical analog input |
| DAC1 CH1 -> COMP1 IN- | programmable slicing threshold |
| COMP1 -> internal TIM2 TI4 | comparator edge routing; no external jumper |
| TIM2 CH4 -> DMA1 Stream1 | both-edge timestamps into the circular RX ring |
| PE9 / TIM1 CH1 + DMA2 Stream0 | optical TX cell waveform |
| PB10 / PB11, USART3 | Raspberry Pi TX / RX at 2 Mbaud |

PC5 can expose COMP1_OUT only when `OPENVLC_COMP_DEBUG_OUTPUT=1`; it is off in
production to avoid needless switching beside the analog input. ADC1 and TIM6
are not part of the active receiver.

## RX pipeline

1. COMP1 slices PB0 against the DAC threshold in high-speed, low-hysteresis
   mode.
2. TIM2 captures both edges at 64 MHz (16 MHz in the 500-kbit/s profile) and
   DMA writes timestamps to a 128-KB non-cacheable circular ring.
3. The foreground poller segments bursts on the inter-frame gap and removes
   pulses shorter than the hardware/profile limit.
4. Every burst obtains its own robust preamble estimates: low-cell duration
   `t0`, high-cell duration `t1`, and average cell period `T`.
5. Each interval is quantized independently against those packet-local
   estimates. A conservative 1/16-cell boundary bias, validated on real
   captures, prevents borderline filter/comparator timing from inserting a
   false cell. Residual timing is measured but never fed into the next edge.
6. Strict preamble/SFD correlation fixes polarity and phase. If the normal
   decoder fails, a bounded fallback detects sustained Manchester pair errors
   and realigns by one cell. Isolated defects are left to RS, the declared
   length must fit the burst, and every recovered frame still requires full
   RS/CRC validation.
7. Timing anchors are learned across packets only from validated frames.

A missing comparator transition is lost information and cannot always be
reconstructed uniquely. The decoder tolerates timing movement and isolated
defects, but the analog chain must still produce a usable edge for nearly every
cell transition.

## TX and scheduling

Packets arriving from the Pi are parsed from the USART3 RX DMA ring, framed and
Manchester encoded directly into one of four TIM1 DMA slots. READY slots are
served by enqueue age, never by array index, preserving FIFO order under
full-duplex backlog. TIM1/DMA2 generates the PE9 waveform independently of CPU
scheduling; the 3-second boot waveform is disabled.

RX processing runs before bounded TX encoding in each foreground iteration.
The TIM2 ring is polled through DMA NDTR, so high-rate capture does not create a
DMA interrupt storm. DMA-written RX and UART rings are MPU non-cacheable; the
cacheable TX slots are cleaned before DMA starts.

## Host frame

Both serial directions use:

```text
A5 5A C3 | version | type | sequence | length | payload | CRC16-CCITT
```

One Raspberry bridge owns both the serial descriptor and TUN interface. Do not
run separate RX and TX services on the same UART.

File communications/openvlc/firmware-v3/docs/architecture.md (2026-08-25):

# Architecture

The maintained architecture description is [../ARCHITECTURE.md](../ARCHITECTURE.md).

This v2 project uses PB0/COMP1 for RX, PE9/TIM1 for optical TX, and
PB10/PB11/USART3 for the Raspberry Pi. Historical PB2, ADC sampled-RX, TIM6
software-RX, and TIM3 TX descriptions do not apply to this hardware.

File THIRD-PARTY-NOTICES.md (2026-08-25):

# Third-party components

The MIT licence in [`LICENSE`](LICENSE) covers the work in this repository.
It does **not** cover the vendor components redistributed alongside it, which
keep the licences their authors granted. Each one carries its own `LICENSE.txt`
in place; those files are authoritative.

| component | in | licence |
|---|---|---|
| Arm CMSIS (Core, DSP, Device headers) | `communications/openvlc/firmware-v*/Drivers/CMSIS/` | Apache-2.0, Arm Limited |
| STM32H7xx HAL and LL drivers | `communications/openvlc/firmware-v*/Drivers/STM32H7xx_HAL_Driver/` | BSD-3-Clause, STMicroelectronics |
| STM32H7xx CMSIS device support | `communications/openvlc/firmware-v*/Drivers/CMSIS/Device/ST/STM32H7xx/` | Apache-2.0, STMicroelectronics |

These are kept in the tree deliberately, so the firmware builds from a fresh
clone without chasing versions. Redistributing this repository means honouring
their terms as well as the MIT licence above.

## Protocol lineage

The frame layout and the Reed-Solomon scheme the firmware speaks come from the
upstream OpenVLC BeagleBone protocol, selected in the firmware by
`OPENVLC_BEAGLEBONE_COMPAT`. The implementation here is original; the wire
format it interoperates with is not.

## Hardware

`hardware/` holds PCB design files, not software. The MIT licence is a software
licence and is a poor fit for board designs — if these are to be reused, a
hardware licence such as CERN-OHL states the intent far better.

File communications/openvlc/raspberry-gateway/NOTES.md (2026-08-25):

# Bench notes

Everything needed to run an OpenVLC link from a Raspberry Pi and read what it
tells you. Target: `firmware-v2`.

- [Layout](#layout)
- [Running a node](#running-a-node)
- [Logs](#logs)
- [Traffic tests](#traffic-tests)
- [Diagnostic reference](#diagnostic-reference)
- [Reading recipes](#reading-recipes)

---

## Layout

Each node is one Raspberry Pi plus one STM32H723 Pi HAT. The Pi runs a bridge
that owns a TUN interface and speaks a framed protocol over UART to the HAT;
the HAT does the optical work (comparator RX + TIM1 TX).

```
  tun0 192.168.0.1/24          tun0 192.168.0.2/24
        Pi node A                     Pi node B
           |  UART 2 Mbaud                |
        H723 HAT   ~~~ optical ~~~    H723 HAT
        addr 7                        addr 8
```

A receiver discards frames carrying its own optical address as source, so the
two nodes must be flashed with different `OPENVLC_TRANSCEIVER_NODE` values.
Never flash the same node firmware on both boards.

Hosts are named `nodeA`, `nodeB`, ... and everything on the Pi side derives
from that: node letter, tun address, capture filenames. Adding `nodeC` means
naming the host and running the installer — no new file, no edit.

| path on the Pi | what |
|---|---|
| `/opt/openvlc-raspberry/` | deployed code |
| `/opt/openvlc-raspberry/logs/` | **all bench output** |
| `/opt/openvlc-raspberry/logs/captures/` | STM32 RX captures |
| `/etc/default/openvlc-transceiver` | this node's settings |

---

## Running a node

Install once, per node. The installer reads the node identity from the
**hostname** — hosts are named `nodeA`, `nodeB`, `nodeC`, ... — so on a
correctly named Pi there is nothing to pass:

```bash
sudo bash ./install/install_transceiver_service.sh
```

`nodeA` becomes node `a` on `192.168.0.1`, `nodeB` node `b` on `192.168.0.2`,
and so on: the letter is the host address. Captures are tagged with the
hostname, so a `.bin` from `nodeC` says so in its filename.

A host not named that way is **rejected** rather than guessed at — an earlier
version of this derivation would have turned `raspberrypi` into node `i`. Pass
it explicitly instead:

```bash
sudo bash ./install/install_transceiver_service.sh --node c --peer 192.168.0.1
```

Beyond two nodes `--peer` is required: with two, "the other one" is
unambiguous; with three or more on a shared optical medium, which peer the tun
points at is a routing decision and the installer will not invent it.

Then check what it wrote:

```bash
cat /etc/default/openvlc-transceiver && ip -br addr show tun0
```

Node A must report `192.168.0.1/24`, node B `192.168.0.2/24`.

Start, stop, restart:

```bash
sudo systemctl start openvlc-transceiver
```

```bash
sudo systemctl restart openvlc-transceiver && systemctl status openvlc-transceiver --no-pager
```

Reachability, and an MTU check in one command — `900 - 28 = 872`:

```bash
ping -c 5 -M do -s 872 192.168.0.2
```

If that fragments or fails, nothing below is worth reading.

### Changing a setting

Everything the bridge takes is an environment variable in
`/etc/default/openvlc-transceiver`. Edit, then restart.

| variable | default | what it does |
|---|---|---|
| `OPENVLC_SERIAL_PORT` | `auto` | UART to the HAT; `auto` picks the only one present |
| `OPENVLC_SERIAL_BAUD` | `2000000` | host link speed, not the optical rate |
| `OPENVLC_TUN_CIDR` | per node | this node's address |
| `OPENVLC_PEER_IP` | per node | the other end |
| `OPENVLC_MTU` | `900` | tun MTU; the optical frame carries 828 B of payload |
| `OPENVLC_TX_MAX_FPS` | `125` | frames/s handed to the HAT; `0` disables pacing |
| `OPENVLC_STATS_INTERVAL` | `5` | seconds between `[trx-bridge]` lines |
| `OPENVLC_CAPTURE_DIR` | `logs/captures` | where RX captures land |
| `OPENVLC_CAPTURE_NODE` | hostname | label written into capture filenames |

`OPENVLC_TX_MAX_FPS` is the one worth knowing: lowering it on one node while
the other stays at 125 is how you tell whether a counter follows the *local*
transmitter or the *received* traffic. See
[self-interference](#is-my-own-transmitter-blinding-my-receiver).

### Running it by hand

Stop the service first or the two fight over the serial port:

```bash
sudo systemctl stop openvlc-transceiver
```

```bash
sudo python3 /opt/openvlc-raspberry/vlc_transceiver_bridge.py --port auto --baud 2000000 --dev tun0 --ip 192.168.0.2/24 --peer-ip 192.168.0.1 --source-route="" --mtu 900 --stats-interval 5 --tx-max-fps 125 --capture-node "$(hostname)"
```

---

## Logs

The bridge prints to stdout; under systemd that becomes the journal.

**Watch live**, only the lines that carry numbers:

```bash
journalctl -u openvlc-transceiver -f | grep -E "COMP|TX uart|trx-bridge"
```

**Watch just the RX health line:**

```bash
journalctl -u openvlc-transceiver -f | grep --line-buffered "COMP "
```

**Save a run.** `collect_logs.sh` writes into `logs/` beside the captures, with
a context file recording which node, which settings and which build produced
the numbers — a log without that is hard to interpret a month later:

```bash
./collect_logs.sh -s "30 min ago" -t baffle-test
```

**Record a run as it happens:**

```bash
./collect_logs.sh -f -t long-run
```

**Hand the whole thing to someone else:**

```bash
tar czf run.tar.gz -C /opt/openvlc-raspberry logs
```

### RX captures

When the firmware hits a failure trigger it emits an interval trace, which the
bridge validates and writes to `logs/captures/` as a `.bin` plus a `.json` of
metadata. Those replay offline through `failure_replay` in the firmware tree,
so a decoder problem can be worked without the optical bench running at all:

```bash
for f in logs/captures/*.bin; do ./failure_replay_fast "$f"; done
```

Captures are disabled with `--no-capture-save` when you only want the
validation, not the files.

---

## Traffic tests

Both directions of the link are independent. Test them one at a time before
testing them together — if one direction is already bad, the simultaneous
result tells you nothing.

### UDP

Server on B:

```bash
iperf -u -s -p 10001 -i 1
```

Client on A, at the link's nominal rate:

```bash
iperf -u -c 192.168.0.2 -b 800k -l 800 -p 10001 -t 60 -i 1
```

`-l 800` because 800 B of UDP payload plus 28 B of IPv4+UDP headers is the
828 B the optical frame carries. Read the loss column, not the bandwidth: at a
fixed offered rate the bandwidth just mirrors the loss.

### TCP

```bash
iperf -s -p 5201 -i 1
```

```bash
iperf -c 192.168.0.2 -p 5201 -t 60 -i 1 -M 860
```

`-M 860` fixes the MSS at `900 - 40`. Without it TCP tries 1460 and relies on
path-MTU discovery, which adds noise to the measurement.

Expect TCP to come out well below the UDP number. Congestion control reads
optical loss as congestion and backs off; that is TCP behaving normally on a
lossy link, not a fault. `-r` runs the two directions in sequence, `-d` runs
them simultaneously — start with `-r`.

### Both directions at once

Only after each direction is clean on its own. Simultaneous traffic is when
the local transmitter and the local receiver are both active, which is exactly
the condition that exposes optical self-interference.

---

## Diagnostic reference

Three lines matter. Every field below is mapped to its firmware variable, so
the meaning is the source's, not a guess.

### `[stm32] COMP` — receive health

Rates are per logging interval; totals are cumulative since boot. Mixing the
two up is the single most common misreading: `ovf=172` standing still means the
ring overflowed 172 times *at some point*, not that it is overflowing now.
**Only a growing total is evidence.**

**Rates** — recomputed every interval:

| field | meaning |
|---|---|
| `ep` | comparator edges per second. ~1.0-1.5M on a live link |
| `bp` | bursts detected per second. Should equal the frame rate |
| `sp` | frames *seen* per second — a burst that produced an SFD hit |
| `okp` | frames *delivered* per second. This is the one that matters |
| `lp` | over-long intervals per second |
| `gpm` | glitches per mille of all edges |

**Interval histogram** — how the edge widths are distributed, in 64 MHz ticks.
A legitimate half-cell is 32 ticks and a full cell 64, so a healthy link puts
almost everything in `r24p`:

| field | bucket |
|---|---|
| `r07` | 0-7 ticks — pure noise |
| `r811` | 8-11 — glitches. Watch this one: it is the noise floor |
| `r1215` | 12-15 |
| `r1619` | 16-19 |
| `r2023` | 20-23 |
| `r24p` | 24 and above — where the signal should be |

**Timing recovery** — the most diagnostic group on the line:

| field | meaning |
|---|---|
| `hc` | recovered half-cell, ticks |
| `t0` / `t1` | recovered half-cell **per polarity**. See below |
| `tn` | nominal half-cell the decoder is working against (32) |
| `trq` | peak timing residual |
| `thr` | comparator threshold, DAC code. `mV = dac * 3300 / 4095` |

`t0` and `t1` are worth more than the rest of the line put together. They must
**sum to `2 x tn`** — if they do, the clock is correct, whatever else is wrong.
And they should be roughly **equal**: the gap between them is the duty-cycle
distortion, and it eats the margin the decoder needs to tell a 1-cell interval
from a 2-cell one. See [duty](#the-duty-is-off-centre).

**Frame counters** — cumulative:

| field | meaning |
|---|---|
| `seen` | frames attempted |
| `ok` | frames delivered to the host |
| `crc` | failed the CRC — framed correctly, payload corrupt |
| `sync` | failed framing — never reached a CRC |

`crc` against `sync` says *where* frames die, and the two lead to completely
different fixes. Payload corruption is an analog problem; framing failure is
acquisition or timing.

**Buffers and overruns** — cumulative, read as deltas:

| field | meaning |
|---|---|
| `hq` / `hd` | frames queued to the host / dropped there |
| `rp` | peak edge-ring occupancy |
| `rd` | edge-ring drops. **If this grows, stop reading the rest of the line** |
| `hwo` | timer hardware overcaptures |
| `ovf` | edge buffer overflows |

**Burst segmentation:**

| field | meaning |
|---|---|
| `fr` | bursts fragmented — a gap appeared *inside* a frame |
| `fa` | edge index where the last fragmentation happened |
| `fg` | the gap that caused it, in microseconds |
| `sg` | soft-gap probes / completed / bridged / reused |
| `br` `bl` `bok` `bf` `bsh` `bst` | last raw / segmented / ok / failed / short burst length, and the last decode status |

`fr` growing at the frame rate means every frame is being cut in two. Compare
`fg` against `OPENVLC_EDGE_GAP_US` (14 µs): a gap just over that threshold is
the segmenter mistaking a dead stretch inside a frame for a frame boundary.

**Decode cost:**

| field | meaning |
|---|---|
| `du` | last decode, microseconds |
| `dm` | worst decode, microseconds |

The frame period is 8000 µs. `du` above ~5000 means anything else added to the
CPU will push it over.

**SFD synchronisation** — why acquisition failed:

| field | meaning |
|---|---|
| `sf` | last SFD-sync result |
| `lock` | cell index the SFD locked at |
| `ss` | successful syncs |
| `pre` `pbad` `pse` | preamble rejects, bad-max, sfd-min |
| `se` | SFD bit errors |
| `m` | SFD sync mode |
| `pe` | phase edits applied |
| `ps` | parse status of the last frame (negative = failure) |

**Failure attribution** — which stage rejected the frame:

| field | rejected at |
|---|---|
| `ft` | timing |
| `fn` | no SFD found |
| `fp` | preamble |
| `fx` | parse |
| `fc` | CRC |
| `fl` | length |
| `fo` | overflow |
| `fi` | incomplete |
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

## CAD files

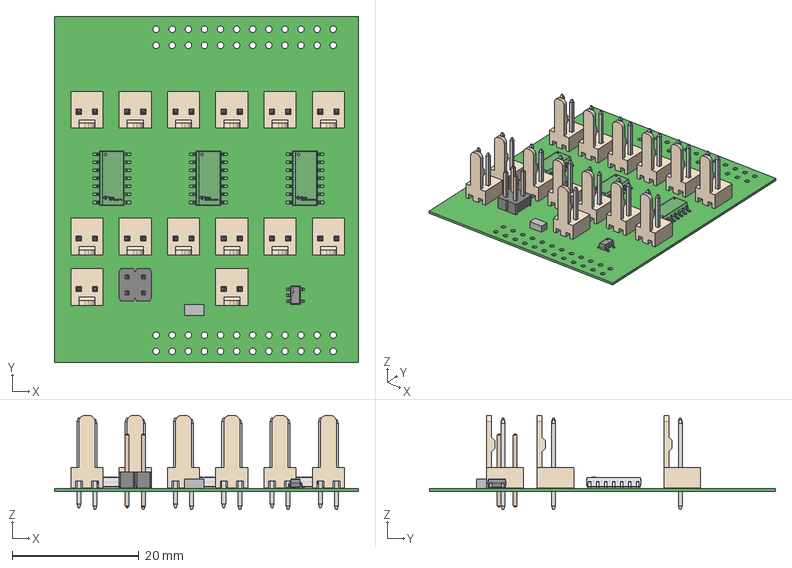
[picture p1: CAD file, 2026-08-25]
hardware/interconnect/PCB_INTER_V1.2/PCB_INTER.step
48.0 x 54.6 x 14.9 mm
6190xx11121_PIN x 28
6130xx21121_PIN x 4
IC_BODY x 3
circle x 3
IC_LEG x 21
IC_LEG_MIR8 x 21
Texas Instruments x 3
Extruded
BODY-SOT
LEAD-SOT x 5
Texas Logo Yury
Texas Logo Yury - Copy

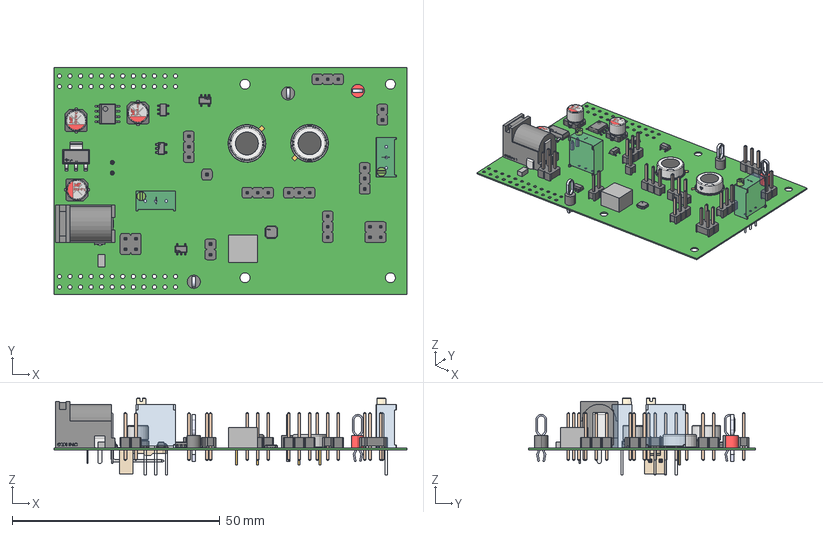
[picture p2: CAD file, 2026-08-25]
hardware/rx/PCB_RX_V2.5_A/PCB_RX_V2.5_A.step
85.0 x 54.6 x 18.4 mm
keystone-PN5011 x 2
BODY-SOT x 4
LEAD-SOT x 18
Texas Logo Yury x 4
Texas Logo Yury - Copy x 4
keystone-PN5010
Bourns x 2
base x 2
top x 2
marking x 2
6130xx11121_PIN x 23
6130xx21121_PIN x 8
6190xx11021_PIN x 2
Extruded x 2
BODY_MF05A
LEAD_MF05F x 5
LEAD-SOT-WIDE
BODY_M08A_35
LEAD_M08A_57 x 8
MANIFOLD_SOLID_BREP_2784
MANIFOLD_SOLID_BREP_2935
MANIFOLD_SOLID_BREP_3086
MANIFOLD_SOLID_BREP_3237
Analog Devices AD8338ACPZ-R7 1
Analog Devices AD8338ACPZ-R7 2
Analog Devices ss.iam
logo
capicitor_5x5.5x1.4 x 3
Base_Φ5Capacitor x 3

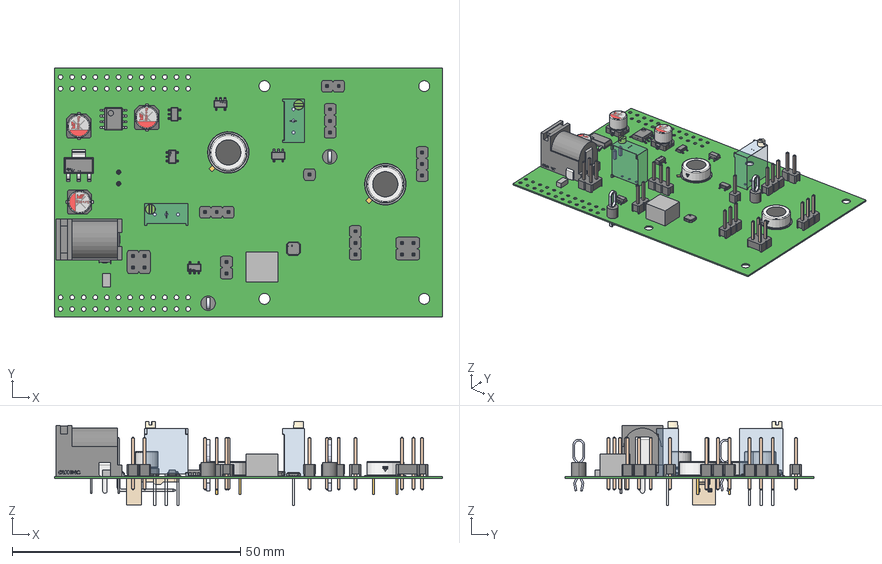
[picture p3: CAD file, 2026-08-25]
hardware/rx/PCB_RX_V2.5_C/PCB_RX_V2.5_C.step
85.0 x 54.6 x 18.4 mm
6130xx11121_PIN x 17
BODY_MF05A x 2
LEAD_MF05F x 10
keystone-PN5011 x 2
BODY-SOT x 4
LEAD-SOT x 18
Texas Logo Yury x 4
Texas Logo Yury - Copy x 4
Bourns x 2
base x 2
top x 2
marking x 2
6130xx21121_PIN x 8
6190xx11021_PIN x 2
Extruded x 2
LEAD-SOT-WIDE
BODY_M08A_35
LEAD_M08A_57 x 8
MANIFOLD_SOLID_BREP_2784
MANIFOLD_SOLID_BREP_2935
MANIFOLD_SOLID_BREP_3086
MANIFOLD_SOLID_BREP_3237
Analog Devices AD8338ACPZ-R7 1
Analog Devices AD8338ACPZ-R7 2
Analog Devices ss.iam
logo
capicitor_5x5.5x1.4 x 3
Base_Φ5Capacitor x 3

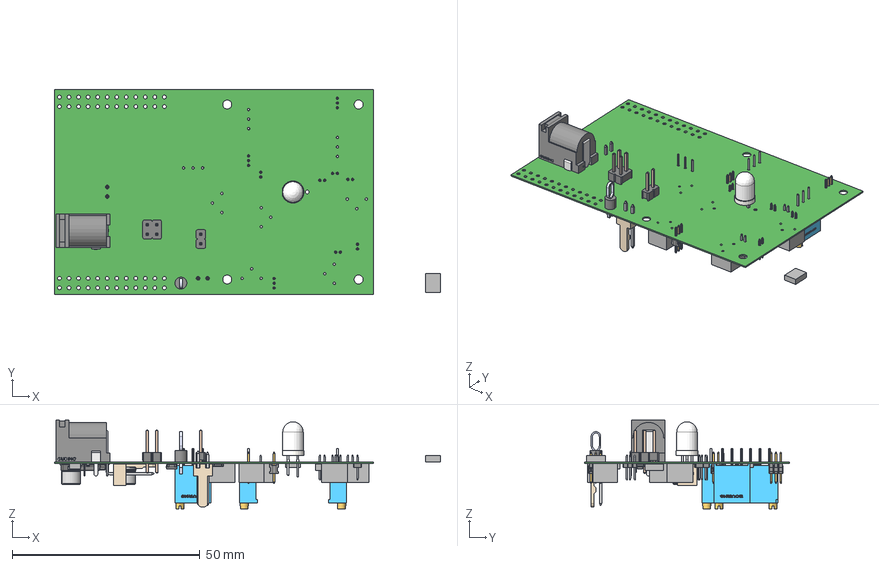
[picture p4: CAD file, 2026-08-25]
hardware/rx/PCB_RX_V2.7/PCB_RX_V2.7.step
102.8 x 54.6 x 23.6 mm
Extruded x 9
Res_Bourns_3296W-1-504LF_eec x 12
TMS-102-S_header x 3
logo x 4
terminal x 9
Pins x 6
Sullins Connector Logo x 6
6190xx11121_PIN x 2
6130xx21121_PIN x 4
`1
6190xx11021_PIN x 2
keystone-PN5011
BODY-SOT x 2
LEAD-SOT x 8
LEAD-SOT-WIDE
Texas Logo Yury x 2
Texas Logo Yury - Copy x 2
BODY_M08A_35
LEAD_M08A_57 x 8
MANIFOLD_SOLID_BREP_2784
MANIFOLD_SOLID_BREP_2935
MANIFOLD_SOLID_BREP_3086
MANIFOLD_SOLID_BREP_3237
Analog Devices AD8338ACPZ-R7 1
Analog Devices AD8338ACPZ-R7 2
Analog Devices ss.iam
6130xx11121_PIN x 2
capicitor_5x5.5x1.4 x 3
Base_Φ5Capacitor x 3

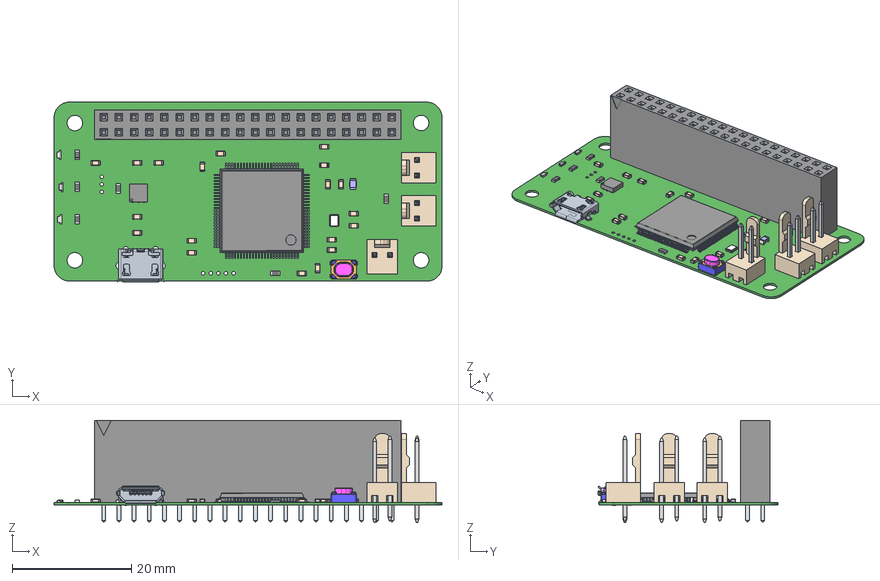
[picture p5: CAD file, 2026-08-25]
hardware/stm32-pi-hat/STM32_Pi_HAT/STM32_Pi_HAT.step
65.0 x 30.1 x 17.1 mm
6190xx11121_PIN x 6
RES0603 x 6
self-0603ME
CAP0603___ x 19
LeadsArray
ThermalPin
PinsArrayLR x 2
PinsArrayTB

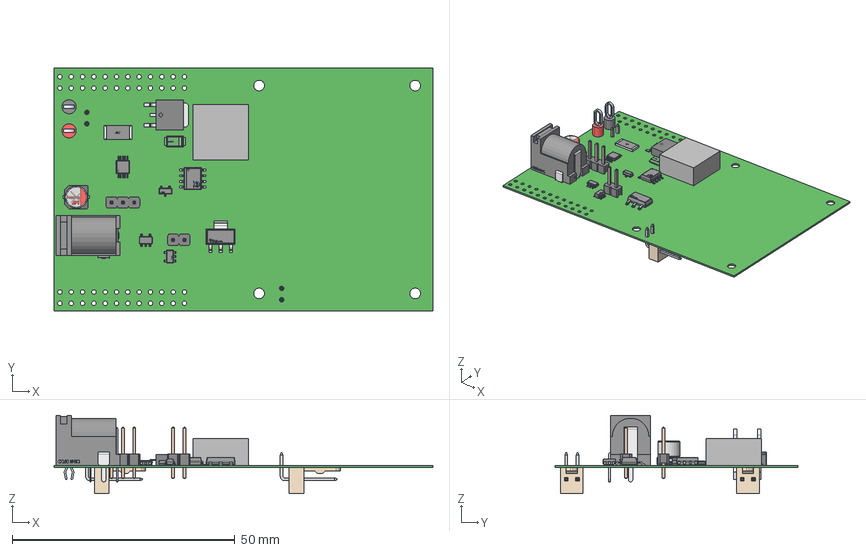
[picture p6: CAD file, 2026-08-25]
hardware/tx/PCB_TX_V2.1.3_B/PCB_TX_V2.1.3_B.step
85.0 x 54.6 x 17.5 mm
keystone-PN5011
6190xx11021_PIN x 4
BODY-SOT x 2
LEAD-SOT x 8
LEAD-SOT-WIDE
Texas Logo Yury x 2
Texas Logo Yury - Copy x 2
6130xx11121_PIN x 5
BODY_MF05A
LEAD_MF05F x 5
keystone-PN5010
pins x 2
logo x 2
Lead x 2
Trimmed_Lead
Nexperia
Sub
Terminals
Coating
Logo
Extruded
part number & logo
capicitor_5x5.5x1.4
Base_Φ5Capacitor
BODY_MUC10A
LEAD_MUC10A x 10
EXP_PAD_MUC10A

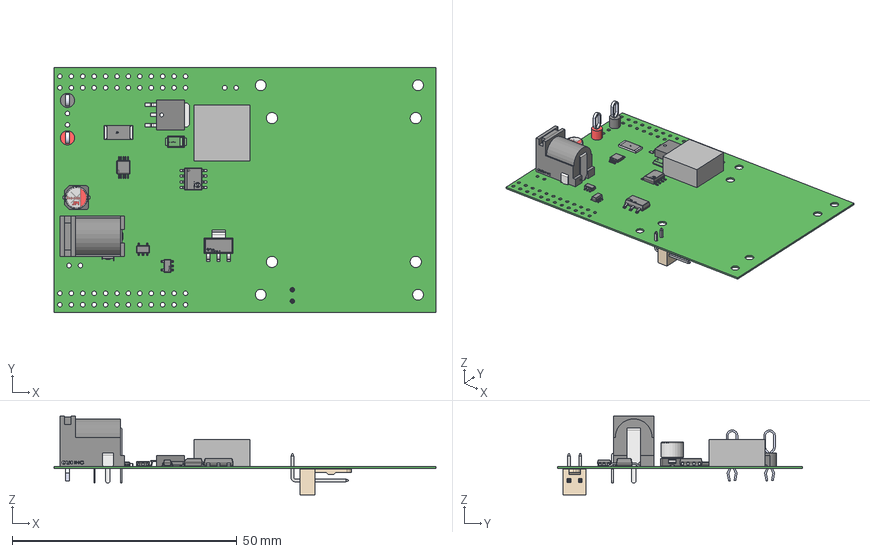
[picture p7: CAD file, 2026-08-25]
hardware/tx/PCB_TX_V2.1.3_C/PCB_TX_V2.1.3_C.step
85.0 x 54.6 x 17.5 mm
keystone-PN5011
6190xx11021_PIN x 2
BODY-SOT x 2
LEAD-SOT x 8
LEAD-SOT-WIDE
Texas Logo Yury x 2
Texas Logo Yury - Copy x 2
BODY_MF05A
LEAD_MF05F x 5
keystone-PN5010
pins
logo x 2
Lead x 2
Trimmed_Lead
Nexperia
Sub
Terminals
Coating
Logo
Extruded
capicitor_5x5.5x1.4
Base_Φ5Capacitor
BODY_MUC10A
LEAD_MUC10A x 10
EXP_PAD_MUC10A

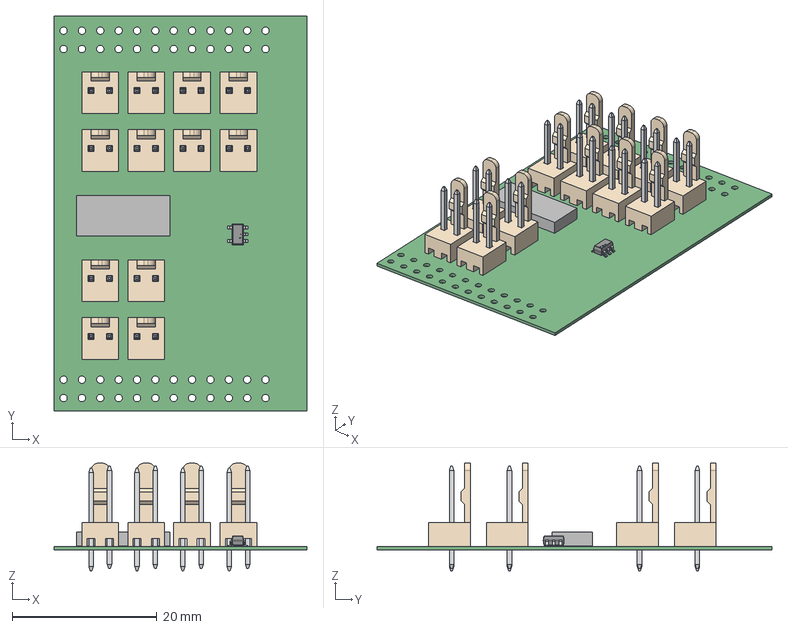
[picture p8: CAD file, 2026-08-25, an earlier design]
hardware/interconnect/PCB_INTER_V1.1/PCB_INTER.step
35.0 x 54.6 x 14.9 mm
6190xx11121_PIN x 24
BODY-SOT
LEAD-SOT x 5
Texas Logo Yury
Texas Logo Yury - Copy
Extruded

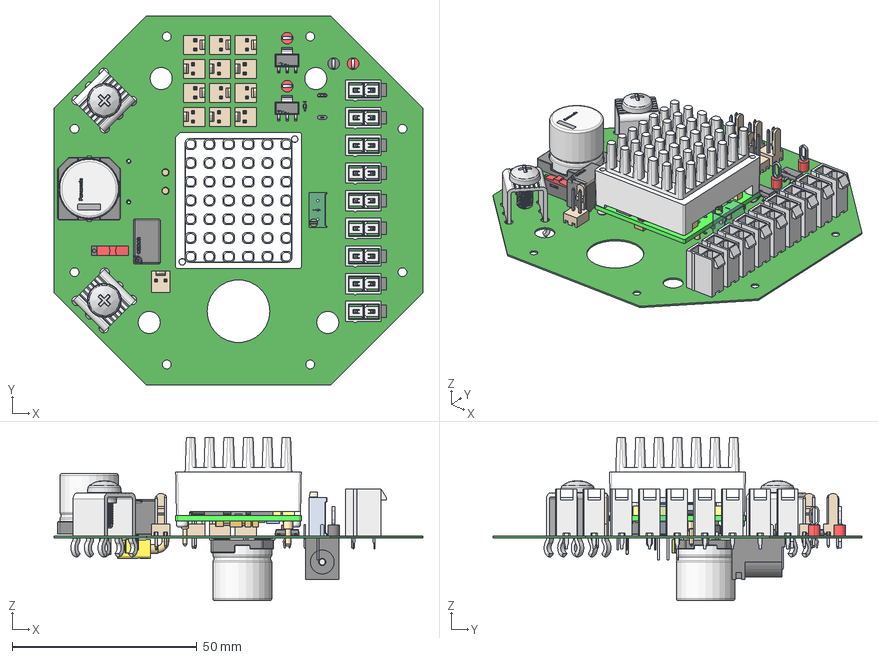
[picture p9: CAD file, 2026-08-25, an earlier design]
hardware/power/PCB_PDB_V1.1/PCB_PDB_V1.1.step
100.0 x 100.0 x 44.3 mm
logo
6190xx11121_PIN x 26
keystone-PN5011
keystone-PN5010 x 3
BODY-SOT x 2
LEAD-SOT x 6
LEAD-SOT-WIDE x 2
Texas Logo Yury x 2
Texas Logo Yury - Copy x 2
6490xx21122_PIN x 18
cover
slide
Package
Leads
Marking
Bourns
Panasonic Logo x 2
I7C_PWB
ZP00206_01 x 2
ZP00232_01 x 5
1206_CAP_COLOR x 3
1206_RLP32 x 4
0805_CAP_COLOR x 4
TSSOP28_BLOCK_01
1210_CAP_2R5MM x 8
0805_RES
POWERDI5_COLOR
5X6X1FET_BLOCK x 4
AP00029
1206_RES_COLOR x 2
ERU19_TALL_FERRITE
ERU19_TALL_WIND
EUR19_TALL_LEG2
EUR_19_BASE
EUR_19_LEG1
EUR_19_LEG3
ZP00264_SIMPLE x 2
ZP00335_01_MP
XT30PW-M

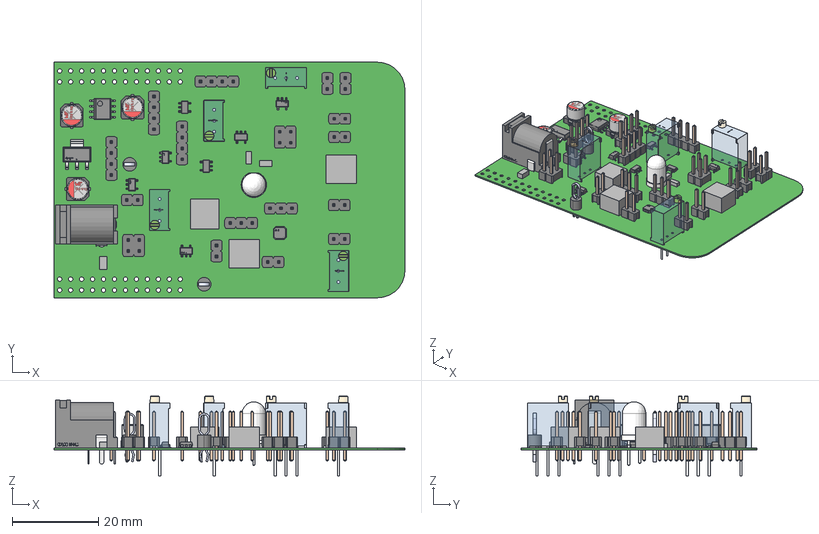
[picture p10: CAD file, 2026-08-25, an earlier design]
hardware/rx/PCB_RX_V2.4/PCB_RX_V2.4.step
81.3 x 54.6 x 18.4 mm
6130xx11121_PIN x 40
Extruded x 6
BODY-SOT x 5
LEAD-SOT x 23
Texas Logo Yury x 5
Texas Logo Yury - Copy x 5
Bourns x 4
keystone-PN5011 x 2
BODY_MF05A x 3
LEAD_MF05F x 15
LEAD-SOT-WIDE
BODY_M08A_35
LEAD_M08A_57 x 8
MANIFOLD_SOLID_BREP_2784
MANIFOLD_SOLID_BREP_2935
MANIFOLD_SOLID_BREP_3086
MANIFOLD_SOLID_BREP_3237
Analog Devices AD8338ACPZ-R7 1
Analog Devices AD8338ACPZ-R7 2
Analog Devices ss.iam
`1
6130xx21121_PIN x 8
logo
capicitor_5x5.5x1.4 x 3
Base_Φ5Capacitor x 3

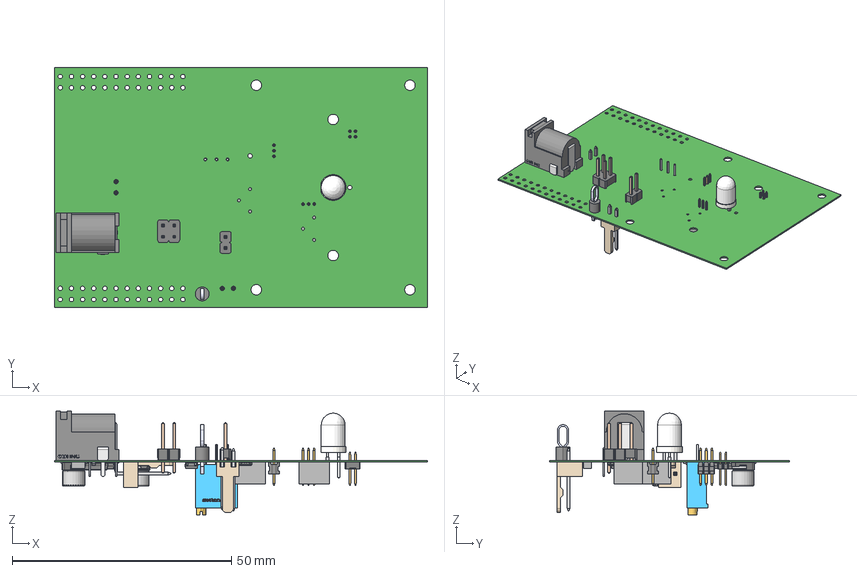
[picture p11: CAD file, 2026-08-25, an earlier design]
hardware/rx/PCB_RX_V2.6/PCB_RX_V2.6.step
85.0 x 54.6 x 23.6 mm
622xxx21121_Pin x 4
622x0421121_Housing
6190xx11121_PIN x 2
Res_Bourns_3296W-1-504LF_eec x 4
6130xx21121_PIN x 4
`1
TMS-102-S_header x 2
logo x 3
terminal x 6
Extruded x 3
BODY-SOT x 3
LEAD-SOT x 13
Texas Logo Yury x 3
Texas Logo Yury - Copy x 3
6190xx11021_PIN x 2
keystone-PN5011
LEAD-SOT-WIDE
BODY_M08A_35
LEAD_M08A_57 x 8
MANIFOLD_SOLID_BREP_2784
MANIFOLD_SOLID_BREP_2935
MANIFOLD_SOLID_BREP_3086
MANIFOLD_SOLID_BREP_3237
Analog Devices AD8338ACPZ-R7 1
Analog Devices AD8338ACPZ-R7 2
Analog Devices ss.iam
6130xx11121_PIN x 2
capicitor_5x5.5x1.4 x 3
Base_Φ5Capacitor x 3

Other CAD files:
hardware/rx/PCB_RX_V2.5_B/PCB_RX_V2.5_B.step
hardware/tx/PCB_TX_V2.2_A/PCB_TX_V2.2_A.step
hardware/rx/PCB_RX_V2.4_B/PCB_RX_V2.4_B.step
hardware/rx/PCB_RX_V2.4_B/PCB_RX_V2.4_B/PCB_RX_V2.4_B/+5V.iam
hardware/rx/PCB_RX_V2.4_B/PCB_RX_V2.4_B/PCB_RX_V2.4_B/1.ipt
hardware/rx/PCB_RX_V2.4_B/PCB_RX_V2.4_B/PCB_RX_V2.4_B/1_1.ipt
hardware/rx/PCB_RX_V2.4_B/PCB_RX_V2.4_B/PCB_RX_V2.4_B/2.ipt
hardware/rx/PCB_RX_V2.4_B/PCB_RX_V2.4_B/PCB_RX_V2.4_B/2_1.ipt
hardware/rx/PCB_RX_V2.4_B/PCB_RX_V2.4_B/PCB_RX_V2.4_B/2_2.ipt
hardware/rx/PCB_RX_V2.4_B/PCB_RX_V2.4_B/PCB_RX_V2.4_B/3.ipt
hardware/rx/PCB_RX_V2.4_B/PCB_RX_V2.4_B/PCB_RX_V2.4_B/3_1.ipt
hardware/rx/PCB_RX_V2.4_B/PCB_RX_V2.4_B/PCB_RX_V2.4_B/5x5.5x1.4.iam
hardware/rx/PCB_RX_V2.4_B/PCB_RX_V2.4_B/PCB_RX_V2.4_B/61300211121.iam
hardware/rx/PCB_RX_V2.4_B/PCB_RX_V2.4_B/PCB_RX_V2.4_B/61300211121.ipt
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

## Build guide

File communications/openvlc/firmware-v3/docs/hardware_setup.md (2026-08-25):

# Pi HAT hardware setup

| Signal | STM32 pin | Configuration |
|---|---|---|
| optical analog RX | PB0 | COMP1 IN+, analog, no pull |
| optical TX | PE9 | TIM1 CH1, AF1 |
| Pi receives from STM32 | PB10 | USART3 TX, AF7 |
| STM32 receives from Pi | PB11 | USART3 RX, AF7 |
| threshold | internal | DAC1 CH1 -> COMP1 IN- |

Connect Pi TX to PB11 and Pi RX to PB10; TX/RX names are from the device that
drives the wire. All boards and optical front ends need a common ground.

The PB0 waveform must remain inside the STM32 input range (0..3.3 V, with
margin) and cross the configured DAC threshold in both directions. Do not
drive PC5 into PB11: COMP1 reaches TIM2 through the internal mux.

For an oscilloscope view of the digital slicer output set
`OPENVLC_COMP_DEBUG_OUTPUT=1` and probe PC5. Restore it to zero for performance
tests. Probe PE9/OWC_TX for optical TX.

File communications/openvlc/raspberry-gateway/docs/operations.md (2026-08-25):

# OpenVLC Operations, Testing, and Parameter Reference

End-to-end runbook for bringing up, validating, and streaming video over the
OpenVLC optical link, plus a reference for every configurable parameter. For
the architecture and per-device detail see the repository
[`README.md`](../../README.md) and the device folders.

**Contents**
1. [Topology & device roles](#1-topology--device-roles)
2. [What to copy where](#2-what-to-copy-where)
3. [Bring-up & validation runbook](#3-bring-up--validation-runbook)
4. [Video streaming](#4-video-streaming)
5. [Watching the video headless](#5-watching-the-video-headless)
6. [Latency tuning](#6-latency-tuning)
7. [Parameter reference](#7-parameter-reference)
8. [Profile matching (TX budget vs RX rate)](#8-profile-matching-tx-budget-vs-rx-rate)
9. [Troubleshooting](#9-troubleshooting)

---

## 1. Topology & device roles

```mermaid
flowchart LR
    SRC["Video / iperf source<br/>(TX Pi or webcam)"] -->|"tun0 192.168.0.1"| TXBR["TX Pi<br/>vlc_stm32_tx_bridge"]
    TXBR -->|"USB serial 2 Mbaud"| TXSTM["STM32 TX<br/>TIM3 DMA to PB4"]
    TXSTM -->|"optical OOK"| STM["STM32 RX<br/>COMP1+TIM2 decoder"]
    STM -->|"USB serial 2 Mbaud"| RXPI["RX Pi<br/>vlc_rx_bridge to tun0<br/>192.168.0.2"]
    RXPI --> DST["iperf server / video"]
```

| Device | Hostname (example) | Job |
| --- | --- | --- |
| STM32 TX | n/a | **Transmits** optically. Receives host-framed IP packets from the TX Pi over USART3. |
| STM32H743 Nucleo | n/a | **Receives** optically, forwards decoded IP over USB serial. Flashed from CubeIDE. |
| TX Raspberry Pi | `VLCTX` | Runs the TUN-to-STM32 TX bridge; generates iperf/video toward `192.168.0.2`. |
| RX Raspberry Pi | `VLCRX` | Runs the **serial to tun0 bridge**; hosts the iperf server / records video. |

Addresses used by the final scripts: TX Pi `tun0` `192.168.0.1/24`, RX Pi
`tun0` `192.168.0.2/24`. Legacy BBB transmitter notes remain in this document
for comparison, but the final STM32-TX path does not route through the BBB.

---

## 2. What to copy where

Source of truth is this repo on your workstation. Each device needs only its
own folder.

**STM32 TX Raspberry Pi** - needs `raspberry-gateway/`:
```bash
scp -r .../openvlc/raspberry-gateway vlctx@<PI_TX>:~/
```

**Legacy BeagleBone TX** - optional reference only. It needs `beaglebone-tx/`
(the PRU compiler `clpru` lives only on the BBB, so the TX is **built on the
BBB**, never on the Pi):
```bash
# workstation -> TX Pi -> BBB (BBB usually reachable only via the Pi/USB):
scp -r .../openvlc/beaglebone-tx vlctx@<PI_TX>:~/
# from the TX Pi to the BBB (old Debian 8 SSH needs legacy scp or tar):
scp -O -r ~/beaglebone-tx debian@192.168.7.2:/home/debian/
#   if scp still fails (old<->new OpenSSH), use tar over ssh:
tar czf - -C ~ beaglebone-tx | ssh debian@192.168.7.2 'tar xzf - -C /home/debian'
```

**RX Raspberry Pi** - needs `raspberry-gateway/`:
```bash
scp -r .../openvlc/raspberry-gateway vlcrx@<PI_RX>:~/
```

**TX Raspberry Pi** - needs `raspberry-gateway/` (for
`install/install_tx_stm32_service.sh`, `tools/vlc_link_test.sh`, `tools/vlc_tx_video.sh`).

**STM32 (RX)** - no copy; build and flash from STM32CubeIDE on the workstation.

---

## 3. Bring-up & validation runbook

### 3.1 STM32 receiver
1. In `stm32-rx/Core/Inc/openvlc_board.h` confirm the profile matches the TX
   budget you will run (see [section 8](#8-profile-matching-tx-budget-vs-rx-rate)) and
   that diagnostics are off (`OPENVLC_BURST_TRACE 0`,
   `OPENVLC_COMP_THRESHOLD_SWEEP 0`).
2. Build (**Release / -O2**) and flash from CubeIDE.
3. Boot log should show `... rate=1000k` (or `1250k`) followed by
   `BOOT: COMP1/DAC1/TIM2-IC started`, with no HardFault.

### 3.2 STM32 transmitter bridge (run on the TX Pi)
```bash
cd ~/raspberry-gateway
sudo bash ./install/install_tx_stm32_service.sh
sudo systemctl status openvlc-tx-stm32
ip route get 192.168.0.2
```

The route must report `dev tun0 src 192.168.0.1`. The STM32 bridge installs a
peer `/32` route deliberately, replacing any more-specific route through
`eth0` left by the former BBB setup.

Foreground debug:
```bash
cd ~/raspberry-gateway
sudo bash ./install/setup_stm32_tx_pi.sh
```

### 3.2b Legacy BeagleBone transmitter (run **on the BBB**, optional)
```bash
cd ~/beaglebone-tx
# budget 50 (validated) via the router that also sets up eth0->vlc0 forwarding:
OPENVLC_TX_ENABLE_MODE=0 PI_IF=eth0 \
  OPENVLC_TX_SYMBOL_WAIT_BUDGET=50 bash ./install/setup_bbb_tx_router.sh
```
Validate: `ip -s link show vlc0` (UP, TX counters rising),
`dmesg | grep 'VLC: params' | tail -1`.

### 3.3 TX Pi traffic source
Use the same TX Pi that is running `openvlc-tx-stm32`. Traffic to
`192.168.0.2` should route to `tun0`.

### 3.4 RX Pi (serial bridge)
```bash
cd ~/raspberry-gateway
sudo bash ./install/install_rx_service.sh
grep OPENVLC_SERIAL_BAUD /etc/default/openvlc-rx     # must equal firmware (2000000)
sudo systemctl restart openvlc-rx
```

### 3.5 End-to-end link test (iperf2 UDP)
```bash
# RX Pi (server):
ROLE=rx bash /opt/openvlc-raspberry/vlc_link_test.sh
# TX Pi (client), budget-40 initial validation:
RATE=800k DURATION=60 bash /opt/openvlc-raspberry/vlc_link_test.sh
```
The **server (RX) report is authoritative**. Watch the PHY at the same time on
the RX Pi:
```bash
journalctl -u openvlc-rx -f | grep --line-buffered -E "COMP |RXRATE|\[bridge\]"
```
Healthy: `ok` near the offered frame rate, `hostdrop=0`, `ringdrop` not
climbing, `[bridge] rate` rising. The validated budget-50 operating point is
roughly 0.8-1.0 Mbit/s of delivered UDP/IP under clean conditions.

`iperf -b` counts UDP payload bits. The bridge rate counts complete IPv4
packets, including the 20-byte IPv4 and 8-byte UDP headers. With the default
752-byte payload, an offered `800k` therefore appears near `830 kbit/s` in the
bridge log; `400k` appears near `415 kbit/s`. This is accounting overhead, not
a PHY-rate limit.

### 3.6 Desktop control panel

The host PC can run the PySide6 control panel in
[`control-app/`](../../control-app/) instead of typing the bring-up commands by
hand.

Recommended GUI order:

1. **Settings -> Save -> Test connections**.
2. **Check system** to verify SSH, routes, tools, camera, service state, and BBB
   TX profile.
3. **Start monitor** to stream `openvlc-rx` logs into the Link Quality tab.
4. **RX bridge** to restart the serial bridge.
5. **TX route** to configure the TX Pi route through the BBB.
6. **BBB TX** to start one of the validated TX budget profiles.
7. **iperf** to measure delivered RX goodput. The panel reports the RX server
   result as authoritative.
8. **Video** to start a selected webcam profile and check its muxrate margin
   against the measured goodput.

The GUI's **Link Quality** tab parses `COMP`, `RXRATE`, `PHY`, `SFDSYNC`, and
optional `VLC_RX packet` lines. In host-forward mode the STM32 suppresses
per-packet text logs, so the periodic `COMP` line also carries the latest
quality sample for intervals that delivered at least one packet:
`qvalid=1 score=... jitter=... tq=... rs=...`. During iperf the GUI records
the receiver's packet-level quality score (`lqi`/`score`), timing jitter
(`tjit`/`jitter`), Reed-Solomon corrections, SFD lock/error state, and PHY
status alongside the RX goodput/loss report. This score is a decoder-margin
metric for the comparator/edge-timing receiver; it is more actionable for this
architecture than electrical SNR.

The GUI displays `seq_gap`, `ringdrop`, `hostdrop`, and `hosterr` as
per-interval events. The raw log fields remain cumulative counters, but a flat
counter means a healthy interval and should appear as zero in the chart.

The GUI intentionally exposes only validated BBB TX budget profiles. If a new
budget is added later, add the matching BBB setup script and STM32 RX timing
profile before exposing it in the panel.

Use **Collect diagnostics** before changing parameters when something looks
wrong. It captures RX journal output, interface state, camera formats, BBB TX
profile, `vlc0` counters, qdisc state, and local GUI configuration into a single
report under `~/Downloads`.

---

## 4. Video streaming

H.264 in MPEG-TS over UDP to `192.168.0.2:5000`.

```bash
# TX Pi, stable baseline:
BITRATE=500k MUXRATE=650k bash vlc_tx_video.sh

# TX Pi, higher-quality profile after iperf validates enough margin:
bash ./tools/vlc_tx_video_quality.sh
```

Keep `MUXRATE` (the wire load) below measured link capacity. FFmpeg performs
constant-rate MPEG-TS pacing; do not leave a manual BBB `tc tbf` rate limiter
active unless you are deliberately running a queueing experiment. See
[section 7](#7-parameter-reference) for all knobs and
[cbr vs capped-crf](#rate-control-cbr-vs-capped-crf).

---

## 5. Watching the video headless

You are usually on the RX Pi over SSH, with no display. The video lands on
`udp://0.0.0.0:5000` on the RX Pi. Three ways out:

```mermaid
flowchart TD
    RX["RX Pi udp:5000<br/>(clean stream from the link)"]
    RX --> A["A. ffmpeg decode to null<br/>(quality check, no display)"]
    RX --> B["B. record .ts + scp to PC<br/>(foolproof, plays local file)"]
    RX --> C["C. re-stream to PC<br/>(live: TCP-out or UDP)"]
```

**A - quality check (no display):**
```bash
ffmpeg -hide_banner -fflags +discardcorrupt \
  -i "udp://0.0.0.0:5000?fifo_size=65536&overrun_nonfatal=1" \
  -t 20 -f null - 2>&1 | grep -iE "corrupt|concealing|frame=" | tail
```
`frame=` rising with few/zero `corrupt`/`concealing` = the link delivers clean
video.

**B - record and view on your PC (no firewall/routing involved):**
```bash
# RX Pi (only ONE reader of port 5000 at a time):
ffmpeg -hide_banner -i "udp://0.0.0.0:5000?fifo_size=65536&overrun_nonfatal=1" \
  -c copy -t 15 ~/rx_capture.ts
```
```powershell
# PC:
scp vlcrx@<PI_RX>:~/rx_capture.ts .
# play the LOCAL file (no network -> firewall cannot block it):
& "C:\Program Files\VideoLAN\VLC\vlc.exe" rx_capture.ts
```

**C - live view on your PC.** Two transports, pick by need:

> ### Live-view golden rules (learned the hard way)
> 1. **Play with `--avcodec-hw=none`.** VLC's hardware H.264 decoder glitches on
>    *live* streams (blocks / frozen bands) while the same content plays clean
>    as a file. Software decode fixes it. In that failure mode the optical link
>    can be clean (`seq_gap=0`) while playback still looks corrupted.
> 2. **Exactly one reader of UDP 5000.** Leftover `ffmpeg`/`socat` processes
>    steal packets and cause blocks. Before every attempt:
>    `sudo pkill -9 ffmpeg socat ; sudo ss -lunp | grep ':5000'` (must be empty).
> 3. **Don't over-tune for latency.** `-fflags nobuffer`, `-flags low_delay`,
>    `--drop-late-frames` and tiny `fifo_size` *cause* the gray bands (they
>    truncate frames). Keep generous buffers; control latency only with the
>    player's `--network-caching`.

The relay carries the (clean) stream from the RX Pi to your PC. A raw `socat`
byte-relay is simplest; `ffmpeg -c copy` also works.

- **TCP relay (PC connects out; no inbound firewall rule needed):**
  ```bash
  # RX Pi (single reader):
  sudo pkill -9 ffmpeg socat
  socat -u UDP-RECV:5000 TCP-LISTEN:5001,reuseaddr
  ```
  ```powershell
  # PC (software decode, generous cache = clean):
  & "C:\Program Files\VideoLAN\VLC\vlc.exe" --avcodec-hw=none --network-caching=1000 "tcp://<PI_RX>:5001"
  ```
- **UDP relay (lower latency; needs a one-time firewall allow):**
  ```bash
  # RX Pi:
  sudo pkill -9 ffmpeg socat
  socat -u UDP-RECV:5000 UDP-SENDTO:<PC_IP>:5001
  ```
  ```powershell
  # PC (admin, once): allow inbound UDP 5001
  New-NetFirewallRule -DisplayName "udp-5001-in" -Direction Inbound -Protocol UDP -LocalPort 5001 -Action Allow -Profile Any
  # then (software decode, low cache for latency):
  & "C:\Program Files\VideoLAN\VLC\vlc.exe" --avcodec-hw=none --network-caching=300 "udp://@:5001"
  ```

> **VLC vs ffplay on Windows:** if `ffplay` shows a black window while VLC works,
> Windows Firewall has a per-application **block** rule for `ffplay.exe`
> (created from a dismissed first-run prompt). Block rules override port
> allows. Either use VLC, or remove the block as admin:
> `Get-NetFirewallApplicationFilter -Program *ffplay.exe* | Get-NetFirewallRule | ? Action -eq Block | Remove-NetFirewallRule`.
>
> **Isolating "blocks in live but the recording is clean":** capture the live
> on the PC to a file and play *that* (`ffmpeg -i "tcp://<PI_RX>:5001" -c copy
> -t 12 "$HOME\Downloads\pc_capture.ts"`). Clean file means it is the player
> (use `--avcodec-hw=none`). Corrupt file on a TCP relay means a second reader is
> stealing packets from UDP 5000.

---

## 6. Latency tuning

Latency is the sum of every buffer in the chain. On a lossy link there is a
hard trade-off: **less buffering = lower latency but more visible artifacts.**

| Lever | Where | Effect |
| --- | --- | --- |
| `MUXDELAY=0` (default 0.6) | `tools/vlc_tx_video.sh` | biggest single cut (~0.6 s) |
| `BUFSIZE` smaller | `tools/vlc_tx_video.sh` | tighter encoder VBV, less queueing |
| `--network-caching=200` | VLC on PC | from 1000 ms default |
| `--drop-late-frames` / `-framedrop` | player | drop late frames to keep realtime |
| `latency 25ms` | BBB `tc tbf` | shorter standing queue |
| UDP last hop | re-stream | drops instead of hoarding (TCP never drops) |

**Constant ~10 s of delay** that never recovers = a standing buffer that never
drains, classic with **TCP on a lossy link** (it retransmits instead of
dropping). Fix with `-framedrop`/`--drop-late-frames` and a clean restart, or
switch the last hop to UDP.

**Heavy macroblocking after going low-latency** = buffers cut too small for the
WiFi jitter on the Pi to PC hop (it is the WiFi hop, not the optical link; the
recorded file proves the link is clean). Raise the re-stream `fifo_size`, set
`pkt_size=1316`, and use a ~200 ms player cache.

Floor: encode + decode (one frame each) + link serialization + the re-stream
hop is realistically about **150-300 ms**; below that needs a display on the RX node
itself (no re-stream hop) or higher fps.

---

## 7. Parameter reference

### `tools/vlc_tx_video.sh` (TX video encoder)
| Variable | Default | Meaning |
| --- | --- | --- |
| `DEV` | `/dev/video0` | webcam device |
| `DEST` | `192.168.0.2` | RX tun0 IP (destination of the UDP stream) |
| `PORT` | `5000` | UDP port |
| `SIZE` | `640x360` | native Logitech C270 MJPEG capture mode |
| `FPS` | `15` | capture frame rate |
| `OUT_SIZE` | (= `SIZE`) | re-scaled output resolution (e.g. `854x480`) |
| `OUT_FPS` | (= `FPS`) | output frame rate |
| `CODEC` | `x264` | `x264` (H.264, better compression) or `mjpeg` (simpler) |
| `RATE_MODE` | `cbr` | `cbr` (constant rate) or `capped-crf` (constant quality, capped) |
| `BITRATE` | `500k` | H.264 elementary-stream rate; in capped-crf it is the **maxrate cap** |
| `MUXRATE` | `650k` | paced MPEG-TS rate on the wire (**keep below link capacity**) |
| `CRF` | `21` | capped-crf quality target (lower = sharper, more bits) |
| `BUFSIZE` | `150k` | VBV buffer; smaller = lower latency, less bursty |
| `PRESET` | `veryfast` | x264 speed/efficiency; slower = better quality per bit |
| `H264_PROFILE` | `main` | CABAC efficiency; B-frames remain disabled |
| `H264_LEVEL` | `3.0` | H.264 level |
| `GOP` | `=fps` | keyframe interval (1 IDR/sec); shorter = faster recovery |
| `MUXDELAY` | `0.60` | TS mux delay (seconds). Lower it for latency only after checking PCR/DTS warnings. |
| `PKT` | `752` | UDP payload = 4 * 188 TS packets (IP total 780 B); multiple of 188 |
| `SLICE_BYTES` | `600` | max H.264 slice size (smaller slice = a lost packet damages less) |
| `BURST_PACKETS` | `1` | TS burst grouping |
| `SEND_BUFFER` | `262144` | UDP socket send buffer |
| `INPUT_FORMAT` | `mjpeg` | compressed USB capture; recommended for the C270 |
| `THREAD_QUEUE_SIZE` | `256` | bounded V4L2 input queue |
| `CAMERA_TUNE` | `1` | apply stable-cadence C270 controls when available |
| `POWER_LINE_FREQUENCY` | `1` | anti-flicker mode: 1=50 Hz, 2=60 Hz |
| `EXPOSURE_AUTO_PRIORITY` | `0` | prevent auto exposure from lowering camera fps |
| `LOGLEVEL` | `info` | ffmpeg log level |

### Logitech C270

The validated camera advertises native MJPEG at `640x360`, `640x480`, and
`864x480`, including 15 and 20 fps. Prefer a native mode over capturing
`640x480` and stretching it to 16:9:

- stable: `640x360@15`, 500k video, 650k mux;
- low latency: `640x360@20`, 560k video, 760k mux;
- more detail: `864x480@15`, 680k video, 800k mux.

The launcher disables `exposure_auto_priority` when the control exists. This
keeps the requested frame cadence in low light. It does not affect optical PHY
jitter; it prevents camera-side frame timing variation and video stalls.

Verify the active camera mode while the encoder is stopped:

```bash
v4l2-ctl -d /dev/video0 --get-fmt-video
v4l2-ctl -d /dev/video0 --get-parm
v4l2-ctl -d /dev/video0 \
  --get-ctrl=exposure_auto_priority,power_line_frequency
```

During streaming, FFmpeg must remain near `speed=1.0x`. A lower value indicates
encoder starvation; it is independent of the optical timing metric.

#### Rate control: cbr vs capped-crf
- **cbr** - constant bits/s regardless of scene. Predictable link load, steady
  LED/AGC, no bursts that overflow a marginal channel; but wastes bits on
  static scenes and degrades on motion. **Safest on this link.**
- **capped-crf** - constant perceptual quality, bitrate floats up to `BITRATE`.
  Best quality-per-bit and low load on static scenes; bursts on motion can fill
  queues and cause artifacts/latency on a channel near capacity. Use for mostly
  static content with a small `BUFSIZE`.

### `tools/vlc_link_test.sh` (iperf2)
| Variable | Default | Meaning |
| --- | --- | --- |
| `ROLE` | `tx` | `tx` = client, `rx` = server |
| `DEST` | `192.168.0.2` | server IP (client mode) |
| `RATE` | `100k` | offered UDP rate |
| `DURATION` | `30` | duration |
| `PAYLOAD` | `752` | UDP payload bytes |
| `PORT` | `10001` | iperf port |
| `INTERVAL` | `1` | report interval (s) |

### `install/setup_tx_pi.sh` (TX Pi routing)
| Variable | Default | Meaning |
| --- | --- | --- |
| `BBB_IF` | `eth0` | Pi interface toward the BBB |
| `TX_PI_CIDR` | `10.0.0.2/24` | Pi address on the BBB link |
| `BBB_IP` | `10.0.0.1` | BBB gateway address |
| `VLC_SUBNET` | `192.168.0.0/24` | optical subnet routed via the BBB |
| `VLC_DEST` | `192.168.0.2` | RX host route (wins over DHCP/VPN) |
| `VLC_MTU` | `900` | path MTU |
| `TX_QUEUE_LEN` | `64` | egress queue / fq_codel limit |

### `install/setup_bbb_tx_router.sh` (BBB TX router; run on the BBB)
| Variable | Default | Meaning |
| --- | --- | --- |
| `PI_IF` | `eth0` | BBB interface receiving from the Pi |
| `BBB_ETH_CIDR` | `10.0.0.1/24` | BBB address on the Ethernet link |
| `VLC_MTU` | `900` | vlc0 MTU |
| `VLC_QDISC_LIMIT` | `24` | vlc0 FIFO limit |
| `OPENVLC_TX_SYMBOL_WAIT_BUDGET` | `50` | optical cell budget (matches RX rate) |
| `OPENVLC_TX_ENABLE_MODE` | `0` | Legacy BBB P8_46 auxiliary LED branch. Use `0`, which holds it low; it is not the packet enable. |
| `OPENVLC_TX_LINE_CODE` | `1` | 1 = Manchester |
| `OPENVLC_TX_WARMUP_BITS` | `0` | leading warm-up bits |

(The `beaglebone-tx/setup_bbb_tx_router.sh` variant runs the **budget-40**
optimized profile via `TX_setup_budget40.sh`.)

### Bridge service - `/etc/default/openvlc-rx`
| Variable | Default | Meaning |
| --- | --- | --- |
| `OPENVLC_SERIAL_PORT` | `auto` | STM32 VCP (auto-detected, or `/dev/ttyACM0`) |
| `OPENVLC_SERIAL_BAUD` | `2000000` | **must equal** firmware `OPENVLC_HOST_UART_BAUD` |
| `OPENVLC_TUN_DEVICE` | `tun0` | bridged TUN interface |
| `OPENVLC_TUN_CIDR` | `192.168.0.2/24` | RX address |
| `OPENVLC_SOURCE_ROUTE` | `10.0.0.0/24` | return route over tun0 |
| `OPENVLC_STATS_INTERVAL` | `5` | `[bridge]` stats period (s) |

### STM32 RX - key `openvlc_board.h` knobs
| Define | Typical | Meaning |
| --- | --- | --- |
| `OPENVLC_PHY_RATE_KBPS` | `1000` / `1250` | timing profile: 1000 = budget 50, 1250 = budget 40 |
| `OPENVLC_COMP_THRESHOLD_DAC` | `2350` | comparator slice level (DAC counts; V = 3.3 * DAC / 4096) |
| `OPENVLC_SFD_SYNC_PREAMBLE_CELLS` | `12` | preamble cells required before SFD lock |
| `OPENVLC_HOST_UART_BAUD` | `2000000` | host serial baud (match the bridge) |
| `OPENVLC_RX_HOST_FORWARD` | `1` | 1 = framed host forward, 0 = plain console |
| `OPENVLC_ENABLE_ICACHE` / `_DCACHE` | `1` / `1` | caches (DMA ring is non-cacheable via MPU) |
| `OPENVLC_BURST_TRACE` / `_THRESHOLD_SWEEP` | `0` / `0` | diagnostics; keep 0 in normal use |

---

## 8. Profile matching (TX budget vs RX rate)

**TX and RX must use the same optical timing**, or nothing decodes.

| Optical profile | TX (BBB) | RX (`OPENVLC_PHY_RATE_KBPS`) | Status |
| --- | --- | --- | --- |
| budget 50 (~0.5 us cell) | `TX_setup_budget50.sh` | `1000u` | **validated; measure on RX, roughly 0.8-1.0 Mbit/s on clean hardware** |
| budget 40 (~0.4 us cell) | `TX_setup_budget40.sh` | `1250u` | experimental, higher capacity |

Change one side, change the other. The validated fallback pair is budget 50 /
`1000u`. The STM32 working tree may be left on `1250u` after budget-40
experiments; the boot log is the authority for what is actually flashed.

---

## 9. Troubleshooting

| Symptom | Cause | Fix |
| --- | --- | --- |
| `clpru: No such file` building TX | running on the Pi, not the BBB | build the TX **on the BBB** (PRU compiler is BBB-only) |
| `scp ... path canonicalization failed` | new OpenSSH scp vs old BBB | `scp -O` + explicit `/home/debian/`, or `tar \| ssh` |
| GUI says `BBB TX ssh=FAIL getaddrinfo failed` | BBB host name is not resolvable from the PC or jump host | use numeric BBB host `192.168.7.2`; if needed set the TX Pi as jump host |
| GUI command fails with `sudo: a terminal is required` | the Pi user needs sudo but the GUI has no password to feed it | save the device SSH password in Settings or configure passwordless sudo for the lab user |
| LED stays off during a test | vlc0 TX not rising, driver/forwarding/route issue, or enable pin | check `ip -s link show vlc0`; verify `setup_*` ran on the right host; try `OPENVLC_TX_ENABLE_MODE=1/2` |
| RX decodes nothing | TX/RX budget mismatch, or wrong threshold | match [section 8](#8-profile-matching-tx-budget-vs-rx-rate); confirm the threshold plateau |
| `ffplay` black, VLC works | firewall blocks `ffplay.exe` inbound | use VLC, or remove the block rule (admin) |
| **blocks / frozen bands in LIVE only (recording is clean)** | **VLC hardware H.264 decode glitches on live streams** | **play with `--avcodec-hw=none`** (software decode) |
| blocks that come and go, "drastically worse" | leftover `ffmpeg`/`socat` still reading UDP 5000 (packet theft) | `sudo pkill -9 ffmpeg socat`; confirm `ss -lunp \| grep ':5000'` is empty |
| `dts < pcr, TS is invalid` on the TX | `MUXDELAY` too small for `BUFSIZE`/`MUXRATE` | set `MUXDELAY >= BUFSIZE/MUXRATE` (default 0.6 is safe) |
| live view ~10 s behind | TCP standing buffer / low-latency hacks removed slack | restart clean; control latency only via player `--network-caching` |
| `ringdrop` climbing in COMP | RX congestion (offered > capacity) | lower offered rate / `MUXRATE`; the 3/4-ring guard prevents collapse but drops |
| video corrupt only at high rate | offered above link capacity | keep `MUXRATE` under measured iperf capacity |

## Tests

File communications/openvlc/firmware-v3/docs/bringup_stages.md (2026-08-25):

# Bring-up stages

`OPENVLC_BOOT_STAGE` selects:

1. host UART and OpenVLC initialization;
2. initialization plus COMP1/TIM2 capture start;
3. full RX/TX polling (production default).

The active receiver starts DAC1 CH1, COMP1 on PB0, the internal COMP1-to-TIM2
TI4 route, and TIM2 CH4 circular DMA. The active transmitter uses PE9 TIM1 CH1
and DMA2. ADC1 and TIM6 are not part of any stage.

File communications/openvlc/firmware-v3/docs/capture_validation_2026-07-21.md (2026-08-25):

# 50-MS/s capture validation — 2026-07-21

Inputs:

- `node_a.csv`: 742129 samples, 14.84256 ms;
- `node_b.csv`: 740001 samples, 14.80000 ms;
- sample interval: 20 ns (50 MS/s).

Both files contain two full optical frames. At 1.50 V, their main bursts are:

| Capture | Raw edges | After deglitch | Duration | Recovered timing |
|---|---:|---:|---:|---|
| node A packet 1 | 11786 | 11776 | 7.369 ms | 26/38, T=32 ticks |
| node A packet 2 | 11801 | 11787 | 7.364 ms | 37/27, T=32 ticks |
| node B packet 1 | 11804 | 11800 | 7.359 ms | 28/36, T=32 ticks |
| node B packet 2 | 11828 | 11784 | 7.359 ms | 28/36, T=32 ticks |

The polarity-specific durations always sum to 64 ticks, confirming a stable
32-tick cell at the 1-Mbit/s profile. Their separation shows substantial
duty-cycle/crossing distortion, but not a clock-rate error.

## Decoder A/B

The rejected DPLL residual carry decoded 0/4 captured packets. Independent
run quantization decoded 3/4 at 1.50 V. Applying a conservative decision bias
of `T/16` (2 TIM2 ticks here) decoded 4/4 with no Manchester bad pairs:

| Capture | Result | Payload | LQI |
|---|---|---:|---:|
| node A packet 1 | RS/CRC OK | 828 | 93 |
| node A packet 2 | RS/CRC OK | 828 | 89 |
| node B packet 1 | RS/CRC OK | 828 | 98 |
| node B packet 2 | RS/CRC OK | 828 | 96 |

An iperf UDP length of 800 bytes appears as 828 bytes at the TUN/optical layer
because the IPv4 and UDP headers add 28 bytes.

The final decoder recovered node A at every tested threshold from 1.30 through
2.30 V. Node B recovered both packets from 1.50 through 2.30 V at the tested
0.10-V points. This supports retaining the firmware's 1.50-V initial threshold
and scan-based adaptation; no fixed threshold change was required.

## Offline replay

`firmware/tests/capture_decode.c` reads a two-column analog CSV, linearly
interpolates threshold crossings, converts them to TIM2 ticks, applies the same
short-pulse cancellation as firmware, segments bursts, and invokes the real
`openvlc_rx_edges_to_packet()` implementation. Its CMake target is
`capture_decode_fast`.

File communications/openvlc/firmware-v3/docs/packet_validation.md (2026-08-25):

# STM32 Packet Validation

This document defines the packet acceptance rules used by the STM32 comparator
receiver. A packet is delivered only when every required validation layer
returns `OPENVLC_OK`.

The receiver supports two frame families:

- BeagleBone-compatible frames produced by the current Linux/PRU transmitter;
- native STM32 frames produced by `openvlc_frame_build()`.

The physical synchronization path is shared. The final integrity check differs
between the two frame families.

## Validation Pipeline

```text
COMP1 edge capture
  -> capture and burst integrity
  -> short-pulse cancellation
  -> half-cell timing estimate
  -> alternating raw-preamble gate
  -> bounded-distance SFD correlation and polarity resolution
  -> Manchester pair recovery
  -> length and buffer bounds
  -> complete-frame and byte-alignment checks
  -> frame-family detection
       -> BeagleBone: Reed-Solomon correction and validation
       -> native STM32: CRC-16/CCITT validation
  -> packet delivery
```

## 1. Capture And Burst Integrity

TIM2 CH4 timestamps both comparator edges at 64 MHz. The platform layer drains
the circular DMA ring and groups edges into bursts separated by an idle gap.

The platform rejects or records:

- DMA or burst-buffer overflow;
- partial bursts lost during capture restart;
- bursts that are too short to contain the configured preamble;
- comparator chatter represented by short pulse pairs.

`openvlc_edge_cancel_short_pulses()` removes both edges of a narrow pulse. It
does not remove only one edge, because doing so would invert every reconstructed
level after the glitch.

## 2. Timing Classification

`comp_estimate_preamble_timing()` finds the longest alternating-preamble
interval run, estimates separate one-cell durations for the two edge
polarities, and averages them into the nominal cell period. A whole-burst
histogram is used only as a fallback.

The decoder rejects a burst when it cannot obtain a plausible timing estimate
or when the nominal cell period is below
`OPENVLC_COMP_MIN_HALFCELL_TICKS`.

## 3. Preamble-Gated SFD Synchronization

The current interoperability profile uses:

```text
raw preamble: 8 bytes of 0xAA
SFD:          0xA3, Manchester-coded
```

The SFD is represented by 16 Manchester line cells. The receiver correlates
against both the expected pattern and its bitwise inverse. The inverse match is
valid because the optical polarity at the comparator output is not assumed.

An SFD match is accepted only when the immediately preceding
`OPENVLC_SFD_SYNC_PREAMBLE_CELLS` reconstructed cells alternate. The validated
default is 12 cells, while the eight-byte raw preamble provides up to 64
cells. The shorter gate tolerates distortion at the start of an AGC burst
without removing the preamble requirement.

This gate prevents an isolated `0xA3`-equivalent sequence in noise, payload
data, or an incomplete burst from opening the frame decoder. After the gate
succeeds, the SFD may contain at most
`OPENVLC_SFD_SYNC_MAX_CELL_ERRORS` mismatches, currently two.

The `SFDSYNC pre_rej` diagnostic counts SFD candidates rejected by this
preamble condition. `SFDSYNC sfderr` reports the Hamming distance of the
accepted SFD. Such a rejection is expected behavior, not a packet integrity
failure.

## 4. Manchester Validation

After SFD lock, the receiver groups reconstructed line cells into Manchester
pairs.

A valid pair contains one low and one high cell. Equal pairs indicate a damaged
cell or a phase error. The current decoder:

- emits the second cell as a best-effort bit for an isolated equal pair;
- counts every invalid pair for link quality;
- allows the later Reed-Solomon or CRC stage to validate the complete frame;
- drops synchronization when a consecutive invalid-pair run exceeds
  `OPENVLC_SFD_SYNC_MAX_CONSECUTIVE_BAD_PAIRS`.

This is intentionally tolerant for BBB frames with FEC. It does not by itself
make a packet valid; the packet must still pass all framing and integrity
checks.

## 5. Length, Bounds, And Completeness

The first 16 recovered bits after the SFD are the raw length field.

For native STM32 frames, this field is the payload length. The receiver checks:

- payload length does not exceed `OPENVLC_MAX_PAYLOAD_BYTES`;
- the expected frame size fits the frame buffer;
- the recovered frame ends on a byte boundary;
- the final byte count exactly matches the declared payload length.

For BeagleBone-compatible frames, the raw field contains the physical encoded
symbol length rather than the payload length. The receiver validates that the
value maps to:

- a supported raw preamble length;
- the configured Manchester expansion;
- a complete byte frame;
- a valid number of 200-byte Reed-Solomon data blocks;
- the required 16 parity bytes for every block.

Random or false length values therefore fail before packet delivery.

## 6. Structural Frame Checks

`openvlc_frame_parse()` checks the canonical frame representation:

- expected preamble bytes;
- expected SFD byte;
- minimum frame size;
- exact native frame size or a valid BBB-compatible frame size;
- data and parity placement within the supplied frame.

In the comparator path, the canonical preamble and SFD bytes are seeded after
the physical preamble-gated SFD lock. Their parser checks are structural
consistency checks, not a second independent observation of the optical
preamble.

## 7. BeagleBone Reed-Solomon Validation

The current BBB transmitter protects:

```text
destination(2) | source(2) | protocol(2) | payload
```

Data is divided into blocks of at most 200 bytes. Each block has 16
Reed-Solomon parity bytes, allowing correction of up to eight unknown byte
errors per block.

The STM32 parser:

1. reconstructs the BBB payload length from the complete frame size;
2. verifies the number and position of parity blocks;
3. runs Reed-Solomon decoding on every block;
4. applies successful byte corrections before extracting the packet;
5. rejects the frame if any block is uncorrectable.

The current BBB frame does not transmit a separate CRC-16. Reed-Solomon is the
final link-layer integrity and correction mechanism for this frame family.

For compatibility with the existing counters, an uncorrectable RS block
returns `OPENVLC_ERR_CRC` and increments `crc_failed`. The `crc` log field
therefore means "final integrity failure" for BBB traffic, not a literal CRC
mismatch.

## 8. Native STM32 CRC Validation

Native STM32 frames append a two-byte CRC-16/CCITT. The CRC covers:

```text
length | destination | source | protocol | payload
```

The received CRC must exactly match the calculated CRC. A mismatch returns
`OPENVLC_ERR_CRC`; no native packet is delivered after a CRC failure.

Native STM32 frames currently use CRC but do not add the BBB Reed-Solomon
parity layout.

## 9. Delivery And Counters

`openvlc_app_rx_edges()` delivers a packet only when the complete decoder returns
`OPENVLC_OK`.

The main counters mean:

| Counter | Meaning |
| --- | --- |
| `seen` | Edge bursts submitted to the decoder |
| `ok` | Packets that passed every required validation layer |
| `crc` | Native CRC mismatch or uncorrectable BBB Reed-Solomon block |
| `sync` | Timing, preamble, SFD, Manchester, length, bounds, or completeness failure |
| `quality` | Reserved quality-policy rejection counter |

For delivered packets, the comparator profile reports the measured normalized
timing residual (`tjit`, shown as `jitter` by some tools), invalid Manchester
pairs (`bad`), longest invalid-pair run (`badrun`), large timing outliers
(`tout`), Reed-Solomon corrections (`rs`), and a combined link-quality
indicator (`lqi`, shown as `score` by some tools). These values are calculated
after synchronization and remain diagnostic only. None replaces the final RS
or CRC integrity decision.

## Checks Not Currently Used As Acceptance Gates

The parser extracts `dst`, `src`, and `protocol`, but it does not currently
reject a packet because:

- the destination does not match `OPENVLC_ADDR_SELF_DEFAULT`;
- the protocol is unknown;
- the packet duplicates a previously delivered STM32 packet.

These are MAC or application policy checks, not PHY integrity checks. They can
be added above `openvlc_platform_on_packet()` without changing synchronization
or FEC behavior.

## Validation Test Matrix

| Test | Expected result |
| --- | --- |
| Idle receiver, no TX | No increase in `ok` |
| SFD-like sequence without alternating preamble | `pre_rej` may increase; no packet delivery |
| Damaged Manchester pairs within RS capability | BBB packet may be corrected and delivered with `rs > 0` |
| More than eight byte errors in one BBB RS block | `crc` increases; packet rejected |
| Native frame with one modified protected byte | CRC mismatch; packet rejected |
| Invalid or random length | `sync` increases; packet rejected |
| Frame truncated before all data/parity bytes | `sync` increases; packet rejected |
| Valid BBB frame | `ok` increases; host-forward builds expose quality on `COMP qvalid=1`, debug builds may also print `VLC_RX packet` |

## Relevant Source Files

| File | Responsibility |
| --- | --- |
| `firmware/platform/stm32h7/openvlc_stm32_hal.c` | DMA drain, burst splitting, capture diagnostics |
| `firmware/openvlc/src/openvlc_phy.c` | Timing recovery, preamble gate, SFD lock, Manchester and length state machine |
| `firmware/openvlc/src/openvlc_frame.c` | Frame-size validation, BBB RS correction, native CRC-16 validation |
| `firmware/openvlc/src/openvlc_app.c` | Final counters, quality reporting, packet delivery |

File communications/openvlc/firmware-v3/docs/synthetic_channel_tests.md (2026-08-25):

# Synthetic channel campaign

`firmware/tests/host_loopback.c` builds the same 828-byte Reed-Solomon frame
used by the link test, converts it to Manchester cells and produces comparator
timestamps without involving the STM32 hardware.

Every configured PHY profile runs a deterministic campaign containing:

- clock offsets from -1% to +1% in the boundary grid and up to +/-1.5% in the
  seeded mixed cases;
- polarity-dependent comparator crossing delay from zero to one quarter cell;
- bounded independent edge jitter;
- captures with and without the artificial timestamp at the frame origin;
- narrow extra comparator pulse pairs passed through the contextual filter;
- missing transition pairs at positions distributed across the complete frame;
- grossly truncated frames.

The acceptance rules are strict:

1. Every impairment inside the supported envelope must decode the complete
   packet byte-for-byte.
2. A destructive impairment may be corrected exactly or rejected.
3. Returning `OPENVLC_OK` with different header or payload bytes is always a
   test failure.

All pseudo-random mixed cases use deterministic seeds. A failure prints its
case number, seed and channel parameters so it can be reproduced exactly.

Run the complete host suite after configuring the CMake build directory:

```sh
cmake --build firmware/build
ctest --test-dir firmware/build --output-on-failure
```

This campaign validates the digital timing and decoding envelope. It cannot
model analog effects that never reach TIM2, such as comparator metastability,
front-end saturation or a transition completely absent from the captured
edge stream. Version-2 raw captures remain the source for adding those real
waveforms as permanent regression cases.

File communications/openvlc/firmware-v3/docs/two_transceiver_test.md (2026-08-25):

# Two-transceiver full-duplex test

## Node identities

| Node | STM32 firmware | TUN address | Optical address |
|---|---|---|---|
| A | build with `OPENVLC_TRANSCEIVER_NODE=1` | `192.168.0.1/24` | `src=7`, `dst=8` |
| B | build with `OPENVLC_TRANSCEIVER_NODE=2` | `192.168.0.2/24` | `src=8`, `dst=7` |

Do not flash the same node firmware on both boards. Each receiver discards
frames carrying its own optical source address.

## Raspberry installation

On node A:

```bash
cd ~/raspberry-gateway
sudo bash ./install_transceiver_service.sh --node a
```

On node B:

```bash
cd ~/raspberry-gateway
sudo bash ./install_transceiver_service.sh --node b
```

Verify:

```bash
cat /etc/default/openvlc-transceiver
ip -br addr show tun0
systemctl status openvlc-transceiver --no-pager
```

Node A must report `192.168.0.1/24`; node B must report
`192.168.0.2/24`. No legacy `10.0.0.0/24` route is installed for this direct
two-node test.

## Optical wiring

Point node A TX LED at node B photodiode and node B TX LED at node A
photodiode. On the Pi HAT the local optical paths are PE9/OWC_TX and
PB0/COMP1_IN. Use an optical barrier between each board's own LED and receiver
to limit self-interference during simultaneous traffic.

## Connectivity

```bash
# Node A
ip route get 192.168.0.2
ping -c 5 192.168.0.2

# Node B
ip route get 192.168.0.1
ping -c 5 192.168.0.1
```

The route must use `tun0` and the local node address as source.

## Simultaneous iperf2

Start the receiver on node A:

```bash
iperf -u -s -p 10002 -i 1
```

Start the receiver on node B:

```bash
iperf -u -s -p 10001 -i 1
```

In a second terminal on node A, transmit toward B:

```bash
iperf -u -c 192.168.0.2 -b 800k -l 800 -p 10001 -t 120 -i 1
```

In a second terminal on node B, transmit toward A:

```bash
iperf -u -c 192.168.0.1 -b 800k -l 800 -p 10002 -t 120 -i 1
```

Monitor both bridges:

```bash
sudo journalctl -u openvlc-transceiver -f -o cat |
grep --line-buffered -E 'trx-bridge|COMP |TX uart'
```

At 800 kbit/s per direction, each bridge should remain near `125 fps` TX and
RX with `drop=0`, `qdrop=0`, `ringdrop=0` and stable `hwovf`.

The STM32 `TX` line must also keep `reorder=0`, `fifoerr=0`, `late=0`, and a
`maxpoll` safely below the approximately 41 ms capacity of the 8192-byte host
RX DMA ring at 2 Mbaud.

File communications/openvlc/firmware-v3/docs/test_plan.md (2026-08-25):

# Link test plan

1. Flash the v2 ELF and confirm `COMP1_PB0`, the intended `rate`, and 2-Mbaud
   USART3 in the init log.
2. With optical TX absent, confirm no packet rate and no sustained false burst
   rate. A raw edge counter may still show isolated noise.
3. Run one direction at a conservative UDP rate. Require increasing valid
   packet count, `ringdrop=0`, `hwovf=0`, and stable `t0/t1/tn`.
4. Repeat in the opposite direction.
5. Run full duplex and increase load gradually. Check TX `qdrop`, RX ring peak,
   CRC/RS, bad-pair run, and `trq` together.
6. If PC5 was enabled for scope correlation, disable it and repeat the final
   throughput test.

`trq / 256` is the largest packet run residual in TIM2 ticks. Treat it as a
diagnostic of the worst crossing, not as a feedback-loop state.

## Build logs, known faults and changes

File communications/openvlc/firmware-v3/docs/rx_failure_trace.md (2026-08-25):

# RX signal capture and offline replay

`OPENVLC_RX_CAPTURE` builds a balanced corpus of comparator bursts accepted and
rejected by the live decoder. The default quotas are 32 successful and 32
failed frames. Version-2 captures contain the TIM2 intervals before software
edge filtering, allowing legacy and timing-aware filters to be compared from
the same physical signal. It reuses one snapshot buffer and streams each
completed capture to the Pi before rearming, so increasing the quotas does not
allocate more STM32 RAM.

The recorder qualifies once after 20 consecutive successful packets, excluding
reset, AGC-settling and startup transients. Captures are then spaced by decoded
frames: a qualifying failure has priority after 20 frames, while a successful
frame is sampled after 64. Each snapshot contains up to 14000 adjacent TIM2 edge
intervals and requires a burst with at least 11000 edges. The spacing restarts
only after the previous binary capture has been completely queued, preventing
adjacent packets or a single failure cascade from dominating the population.
The snapshot also contains the decoder status, SFD/timing estimates, threshold,
PHY profile and timestamp. It does not alter the threshold, timing recovery,
Manchester decisions, Reed-Solomon processing or packet delivery.

Enable the recorder in `Core/Inc/openvlc_board.h`:

```c
#define OPENVLC_RX_CAPTURE 1u
#define OPENVLC_RX_CAPTURE_RAW 1u
```

The normal production default is `OPENVLC_RX_CAPTURE=0u`. Keep
`OPENVLC_RX_CAPTURE_RAW=1u` when collecting a corpus; set capture to `0u` for
an absolute minimum-memory production image. The snapshot
uses at most 28 KB of CPU-only RAM.

The two population sizes and their spacing are independently configurable:

```c
#define OPENVLC_RX_CAPTURE_MAX_FAILURES 32u
#define OPENVLC_RX_CAPTURE_MAX_SUCCESSES 32u
#define OPENVLC_RX_CAPTURE_MIN_FRAME_GAP 20u
#define OPENVLC_RX_CAPTURE_OK_FRAME_GAP 64u
```

Increasing this number does not allocate more STM32 RAM; it only allows the
same buffer to be reused for more events.

## Collection on Raspberry Pi

Install/update the bridge:

```sh
cd ~/Sunrise/communications/openvlc/raspberry-gateway
sudo ./install_transceiver_service.sh
```

Set a unique label in `/etc/default/openvlc-transceiver`:

```sh
OPENVLC_CAPTURE_NODE=node-a
OPENVLC_CAPTURE_DIR=/var/log/openvlc/captures
```

After flashing and resetting the STM32, run the normal traffic test. The
bridge validates every binary chunk and saves only a complete capture:

```sh
sudo journalctl -u openvlc-transceiver -f -o cat
sudo ls -lh /var/log/openvlc/captures
```

Track the two populations independently:

```sh
find /var/log/openvlc/captures -maxdepth 1 -name '*-ok.bin' | wc -l
find /var/log/openvlc/captures -maxdepth 1 -name '*.bin' ! -name '*-ok.bin' | wc -l
```

Completion is reported as:

```text
[rx-capture] saved /var/log/openvlc/captures/node-a-...-crc.bin
[rx-capture] saved /var/log/openvlc/captures/node-a-...-ok.bin
```

Each event produces:

- `.bin`: the exact 88-byte metadata header followed by big-endian `uint16`
  raw timer intervals;
- `.json`: human-readable decoder and acquisition metadata.

ID, offsets, interval count and FNV-1a hash are checked before the atomic
rename. Interrupted or corrupt captures are never exposed as valid files.
The bridge statistic `cap=records/saved/errors` reports collection health.

Create the archive to copy back to the development machine:

```sh
sudo tar -C /var/log/openvlc/captures -czf /tmp/openvlc-rx-captures.tar.gz .
sudo chown "$USER":"$USER" /tmp/openvlc-rx-captures.tar.gz
```

## Replay the firmware decoder

Copy the `.bin` file to the development machine and run the same decoder used
by the STM32 firmware:

```sh
cmake -S firmware -B firmware/build-host
cmake --build firmware/build-host --target failure_replay_fast
firmware/build-host/failure_replay_fast capture.bin
```

Version-2 raw captures automatically use the filter policy compiled into the
selected replay target. The profile-1000 realtime target mirrors the deployed
12-tick physical gate. Force a legacy threshold, or preserve every raw edge,
with:

```sh
firmware/build-host/failure_replay_fast_realtime capture.bin --deglitch=12
firmware/build-host/failure_replay_fast capture.bin --deglitch=0
```

For offline experiments only, a timing-aware filter can be selected explicitly
as `candidate,hard,margin`. This overrides the filter compiled into the replay
executable but never changes the STM32 image:

```sh
firmware/build-host/failure_replay_fast_realtime capture.bin --contextual=13,8,2
```

Add `--search` to run the existing diagnostic cell-override search:

```sh
firmware/build-host/failure_replay_fast capture.bin --search
```

The replay output reports `domain=raw|filtered`, `filter=...`, the active gate
and the number of removed edges. The tool uses the same decoder for both
`-ok.bin` and failure captures, and remains compatible with version-1 `.bin`,
older `RXFAIL_*` journal dumps and extracted CSV files.

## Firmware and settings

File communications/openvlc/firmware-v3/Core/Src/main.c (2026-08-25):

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
/* Includes ------------------------------------------------------------------*/
#include "main.h"
#include "comp.h"
#include "dac.h"
#include "dma.h"
#include "tim.h"
#include "usart.h"
#include "gpio.h"

/* USER CODE BEGIN Includes */
#include "openvlc_board.h"
#include "openvlc_stm32_hal.h"
#include "openvlc_stm32_tx_hal.h"
#include "openvlc_transceiver_host.h"
#include "stm32h7xx_it.h"
#include <stdio.h>

/* USER CODE END Includes */

/* USER CODE BEGIN PD */
/* See Core/Inc/openvlc_board.h for the bring-up stage table. */
#ifndef OPENVLC_BOOT_STAGE
#define OPENVLC_BOOT_STAGE 0
#endif

/* USER CODE END PD */


/* USER CODE BEGIN PV */
volatile uint32_t openvlc_boot_step = 0xB0070000u;
volatile uint32_t openvlc_main_loop_count;
volatile uint32_t openvlc_main_phase;
volatile uint32_t openvlc_main_last_tick;
static uint32_t openvlc_reset_flags;

/* USER CODE END PV */

void SystemClock_Config(void);
static void MPU_Config(void);
/* USER CODE BEGIN 0 */
static void openvlc_tx_boot_pin_test(void)
{
#if OPENVLC_TX_BOOT_PIN_TEST_MS > 0u
  const uint32_t period = OPENVLC_STM32_TX_TIMER_HZ /
                          OPENVLC_TX_BOOT_PIN_TEST_HZ;

  if (period < 2u)
    Error_Handler();

  /* TIM1_CH1 PWM on PE9, independent of UART RX, framing and DMA. */
  CLEAR_BIT(TIM1->CR1, TIM_CR1_CEN);
  CLEAR_BIT(TIM1->CCER, TIM_CCER_CC1E);
  CLEAR_BIT(TIM1->BDTR, TIM_BDTR_MOE);
  TIM1->PSC = 0u;
  TIM1->ARR = period - 1u;
  TIM1->CCR1 = period / 2u;
  MODIFY_REG(TIM1->CCMR1,
             TIM_CCMR1_CC1S | TIM_CCMR1_OC1M | TIM_CCMR1_OC1PE,
             (6u << TIM_CCMR1_OC1M_Pos) | TIM_CCMR1_OC1PE);
  CLEAR_BIT(TIM1->CCER, TIM_CCER_CC1P);
  TIM1->EGR = TIM_EGR_UG;
  TIM1->SR = 0u;
  SET_BIT(TIM1->CCER, TIM_CCER_CC1E);
  SET_BIT(TIM1->BDTR, TIM_BDTR_MOE);
  SET_BIT(TIM1->CR1, TIM_CR1_CEN);
  HAL_Delay(OPENVLC_TX_BOOT_PIN_TEST_MS);

  /* Restore the operational OpenVLC timer profile. */
  CLEAR_BIT(TIM1->CR1, TIM_CR1_CEN);
  CLEAR_BIT(TIM1->CCER, TIM_CCER_CC1E);
  CLEAR_BIT(TIM1->BDTR, TIM_BDTR_MOE);
  TIM1->PSC = 0u;
  TIM1->ARR = OPENVLC_STM32_TX_CELL_TICKS - 1u;
  TIM1->CCR1 = 0u;
  TIM1->CCR4 = OPENVLC_STM32_TX_CELL_TICKS /
               OPENVLC_TX_OC_DMA_PHASE_DIV;
  TIM1->CNT = 0u;
  TIM1->EGR = TIM_EGR_UG;
  TIM1->SR = 0u;
#endif
}

/* USER CODE END 0 */

/**
  * @brief  The application entry point.
  * @retval int
  */
int main(void)
{

  /* USER CODE BEGIN 1 */
  openvlc_reset_flags = RCC->RSR;
  RCC->RSR |= RCC_RSR_RMVF;

  /* USER CODE END 1 */

  /* MPU Configuration--------------------------------------------------------*/
  MPU_Config();

  /* USER CODE BEGIN CPU_CACHE_ENABLE */
#if OPENVLC_ENABLE_ICACHE
  /*
   * The edge decoder and Reed-Solomon parser execute from Flash. I-cache is
   * required for sustained reception.
   */
  SCB_InvalidateICache();
  SCB_EnableICache();
#endif
#if OPENVLC_ENABLE_DCACHE
  /*
   * D-cache halves the decode time (the RAM-bound hot path), restoring the
   * processing margin at the full 134 frame/s load. DMA coherency: the TIM2
     * capture ring occupies the first 160 KB of RAM_D1 and the three TIM1 TX
     * streams occupy the following ~94 KB. MPU region 1 therefore marks the
     * complete first 256 KB NON-CACHEABLE. The final 64 KB remains cacheable
     * for CPU-only RX/host buffers. This keeps TIM2 coherent and lets DMA2
     * prefetch TX cells without a per-frame D-cache clean on the shared AXI
     * bus.
   */
  {
    MPU_Region_InitTypeDef ring_region = {0};
    MPU_Region_InitTypeDef dma_region = {0};

    HAL_MPU_Disable();
    ring_region.Enable = MPU_REGION_ENABLE;
    ring_region.Number = MPU_REGION_NUMBER1;
    ring_region.BaseAddress = 0x24000000UL;
    ring_region.Size = MPU_REGION_SIZE_256KB;
    ring_region.SubRegionDisable = 0x00;
    ring_region.TypeExtField = MPU_TEX_LEVEL1;      /* normal memory */
    ring_region.AccessPermission = MPU_REGION_FULL_ACCESS;
    ring_region.DisableExec = MPU_INSTRUCTION_ACCESS_DISABLE;
    ring_region.IsShareable = MPU_ACCESS_NOT_SHAREABLE;
    ring_region.IsCacheable = MPU_ACCESS_NOT_CACHEABLE;
    ring_region.IsBufferable = MPU_ACCESS_NOT_BUFFERABLE;
    HAL_MPU_ConfigRegion(&ring_region);

    /* DMA1-visible D2 SRAM holds the circular USART3 RX buffer. */
    dma_region.Enable = MPU_REGION_ENABLE;
    dma_region.Number = MPU_REGION_NUMBER2;
    dma_region.BaseAddress = 0x30000000UL;
    dma_region.Size = MPU_REGION_SIZE_32KB;
    dma_region.SubRegionDisable = 0x00;
    dma_region.TypeExtField = MPU_TEX_LEVEL1;
    dma_region.AccessPermission = MPU_REGION_FULL_ACCESS;
    dma_region.DisableExec = MPU_INSTRUCTION_ACCESS_DISABLE;
    dma_region.IsShareable = MPU_ACCESS_NOT_SHAREABLE;
    dma_region.IsCacheable = MPU_ACCESS_NOT_CACHEABLE;
    dma_region.IsBufferable = MPU_ACCESS_NOT_BUFFERABLE;
    HAL_MPU_ConfigRegion(&dma_region);
    HAL_MPU_Enable(MPU_PRIVILEGED_DEFAULT);
  }
  SCB_EnableDCache();
#endif
  /* USER CODE END CPU_CACHE_ENABLE */

  /* MCU Configuration--------------------------------------------------------*/

  /* Reset of all peripherals, Initializes the Flash interface and the Systick. */
  HAL_Init();

  /* Configure the system clock */
  SystemClock_Config();

  /* Initialize all configured peripherals */
  MX_GPIO_Init();
  MX_DMA_Init();
  MX_TIM2_Init();
  MX_TIM1_Init();
  MX_USART3_UART_Init();
  MX_COMP1_Init();
  MX_DAC1_Init();
  /* USER CODE BEGIN 2 */
  openvlc_boot_step = 10u;
  openvlc_tx_boot_pin_test();
  {
    const uint8_t boot_msg[] = "BOOT: USART3 OK\r\n";
    openvlc_boot_step = 11u;
    HAL_UART_Transmit(&huart3, (uint8_t *)boot_msg, sizeof(boot_msg) - 1u, 100);
    openvlc_boot_step = 12u;
  }
  {
    uint32_t pclk2 = HAL_RCC_GetPCLK2Freq();
    uint32_t timclk = ((RCC->D2CFGR & RCC_D2CFGR_D2PPRE2) !=
                       RCC_D2CFGR_D2PPRE2_DIV1) ? pclk2 * 2u : pclk2;
    char hw_msg[128];
    int n = snprintf(hw_msg, sizeof(hw_msg),
                     "BOOT: H723 devid=0x%03lx sys=%lu tim=%lu\r\n",
                     (unsigned long)HAL_GetDEVID(),
                     (unsigned long)HAL_RCC_GetSysClockFreq(),
                     (unsigned long)timclk);
    if (n > 0)
      HAL_UART_Transmit(&huart3, (uint8_t *)hw_msg, (uint16_t)n, 100);
    /* Link identity banner: with three boards in the lab, a same-src pair
     * silently self-drops every peer frame (selfdrop==ok). Make the flashed
     * addressing visible at every boot so the mismatch is caught in seconds. */
    n = snprintf(hw_msg, sizeof(hw_msg),
                 "BOOT: node=%u src=%u dst=%u\r\n",
                 (unsigned int)OPENVLC_TRANSCEIVER_NODE,
                 (unsigned int)OPENVLC_TX_SRC_ADDR,
                 (unsigned int)OPENVLC_TX_DST_ADDR);
    if (n > 0)
      HAL_UART_Transmit(&huart3, (uint8_t *)hw_msg, (uint16_t)n, 100);
    if (HAL_GetDEVID() != 0x483u ||
        HAL_RCC_GetSysClockFreq() != 384000000u ||
        timclk != OPENVLC_STM32_TX_TIMER_HZ)
    {
      const uint8_t fail_msg[] = "BOOT: H723 device/clock mismatch\r\n";
      HAL_UART_Transmit(&huart3, (uint8_t *)fail_msg,
                        sizeof(fail_msg) - 1u, 100);
      Error_Handler();
    }
  }
  {
    char reset_msg[48];
    int n = snprintf(reset_msg, sizeof(reset_msg), "BOOT: reset_flags=0x%08lx\r\n",
                     (unsigned long)openvlc_reset_flags);
    if (n > 0)
    {
      HAL_UART_Transmit(&huart3, (uint8_t *)reset_msg, (uint16_t)n, 100);
    }
  }
#if OPENVLC_BOOT_STAGE >= 1
  openvlc_stm32_init();
#endif
#if OPENVLC_BOOT_STAGE >= 2
  if (openvlc_stm32_memory_selftest() != 0)
  {
    const uint8_t mem_fail_msg[] = "BOOT: RAM selftest failed\r\n";
    HAL_UART_Transmit(&huart3, (uint8_t *)mem_fail_msg, sizeof(mem_fail_msg) - 1u, 100);
    Error_Handler();
  }
  {
    const uint8_t mem_ok_msg[] = "BOOT: RAM selftest OK\r\n";
    HAL_UART_Transmit(&huart3, (uint8_t *)mem_ok_msg, sizeof(mem_ok_msg) - 1u, 100);
  }
  {
    const uint8_t start_msg[] = "BOOT: starting COMP1/DAC1/TIM2-IC\r\n";
    HAL_UART_Transmit(&huart3, (uint8_t *)start_msg, sizeof(start_msg) - 1u, 100);
  }
  if (openvlc_stm32_start() != 0)
  {
    const uint8_t fail_msg[] = "BOOT: openvlc_stm32_start failed\r\n";
    HAL_UART_Transmit(&huart3, (uint8_t *)fail_msg, sizeof(fail_msg) - 1u, 100);
    Error_Handler();
  }
  if (openvlc_transceiver_host_init() != 0)
  {
    const uint8_t fail_msg[] = "BOOT: TX/UART RX init failed\r\n";
    HAL_UART_Transmit(&huart3, (uint8_t *)fail_msg, sizeof(fail_msg) - 1u, 100);
    Error_Handler();
  }
  {
    const uint8_t ok_msg[] = "BOOT: COMP1/DAC1/TIM2-IC started\r\n";
    HAL_UART_Transmit(&huart3, (uint8_t *)ok_msg, sizeof(ok_msg) - 1u, 100);
  }
#endif

  /* USER CODE END 2 */

  /* Infinite loop */
  /* USER CODE BEGIN WHILE */
  while (1)
  {
    /* USER CODE END WHILE */

    /* USER CODE BEGIN 3 */
    static uint32_t last_alive_ms = 0;

#if OPENVLC_RX_DEEP_DEBUG_LOG
    openvlc_main_phase = 1u;
    openvlc_main_loop_count++;
    openvlc_main_last_tick = HAL_GetTick();
#endif
#if OPENVLC_BOOT_STAGE >= 3
#if OPENVLC_RX_DEEP_DEBUG_LOG
    openvlc_main_phase = 2u;
#endif
    openvlc_stm32_rx_comparator_poll();
#endif
#if OPENVLC_RX_DEEP_DEBUG_LOG
    openvlc_main_phase = 3u;
#endif
    openvlc_transceiver_host_poll();
    /* Release the TX idle keep-alive when the host stops sending. */
    openvlc_stm32_tx_idle_poll();
#if OPENVLC_TX_HW_DIAG
    openvlc_stm32_tx_diag_poll();
#endif
#if OPENVLC_BOOT_STAGE >= 2
#if OPENVLC_RX_DEEP_DEBUG_LOG
    openvlc_main_phase = 4u;
#endif
#if OPENVLC_RX_DIAG_LOG || OPENVLC_COMP_THRESHOLD_AUTO || \
    OPENVLC_COMP_DUTY_SERVO
    openvlc_stm32_debug_poll(HAL_GetTick());
#endif
#if OPENVLC_TX_DIAG_LOG
    openvlc_transceiver_host_log(HAL_GetTick());
#endif
#endif
#if OPENVLC_RX_DEEP_DEBUG_LOG
    openvlc_main_phase = 5u;
#endif
#if OPENVLC_RX_HOST_FORWARD
    openvlc_stm32_host_poll();
#endif
    if (HAL_GetTick() - last_alive_ms >= 1000u)
    {
      HAL_GPIO_TogglePin(OPENVLC_HEARTBEAT_GPIO_PORT,
                        OPENVLC_HEARTBEAT_GPIO_PIN);
#if OPENVLC_ALIVE_LOG
#if OPENVLC_RX_HOST_FORWARD
      last_alive_ms = HAL_GetTick();
      openvlc_platform_log("ALIVE\r\n");
#else
      const uint8_t alive_msg[] = "ALIVE\r\n";
      last_alive_ms = HAL_GetTick();
      HAL_UART_Transmit(&huart3, (uint8_t *)alive_msg, sizeof(alive_msg) - 1u, 10);
#endif
#else
      last_alive_ms = HAL_GetTick();
#endif
    }
#if OPENVLC_RX_DEEP_DEBUG_LOG
    openvlc_main_phase = 6u;
#endif
  }
  /* USER CODE END 3 */
}

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
 /* MPU Configuration */

void MPU_Config(void)
{
  MPU_Region_InitTypeDef MPU_InitStruct = {0};

  /* Disables the MPU */
  HAL_MPU_Disable();

  /** Initializes and configures the Region and the memory to be protected
  */
  MPU_InitStruct.Enable = MPU_REGION_ENABLE;
  MPU_InitStruct.Number = MPU_REGION_NUMBER0;
  MPU_InitStruct.BaseAddress = 0x0;
  MPU_InitStruct.Size = MPU_REGION_SIZE_4GB;
  MPU_InitStruct.SubRegionDisable = 0x87;
  MPU_InitStruct.TypeExtField = MPU_TEX_LEVEL0;
  MPU_InitStruct.AccessPermission = MPU_REGION_NO_ACCESS;
  MPU_InitStruct.DisableExec = MPU_INSTRUCTION_ACCESS_DISABLE;
  MPU_InitStruct.IsShareable = MPU_ACCESS_SHAREABLE;
  MPU_InitStruct.IsCacheable = MPU_ACCESS_NOT_CACHEABLE;
  MPU_InitStruct.IsBufferable = MPU_ACCESS_NOT_BUFFERABLE;

  HAL_MPU_ConfigRegion(&MPU_InitStruct);
  /* Enables the MPU */
  HAL_MPU_Enable(MPU_PRIVILEGED_DEFAULT);

}

/**
  * @brief  This function is executed in case of error occurrence.
  * @retval None
  */
void Error_Handler(void)
{
  /* USER CODE BEGIN Error_Handler_Debug */
  openvlc_fault_capture(
      6u, NULL, (uint32_t)(uintptr_t)__builtin_return_address(0));
  /* USER CODE END Error_Handler_Debug */
}
#ifdef USE_FULL_ASSERT
/**
  * @brief  Reports the name of the source file and the source line number
  *         where the assert_param error has occurred.
  * @param  file: pointer to the source file name
  * @param  line: assert_param error line source number
  * @retval None
  */
void assert_failed(uint8_t *file, uint32_t line)
{
  /* USER CODE BEGIN 6 */
  /* User can add his own implementation to report the file name and line number,
     ex: printf("Wrong parameters value: file %s on line %d\r\n", file, line) */
  /* USER CODE END 6 */
}
#endif /* USE_FULL_ASSERT */

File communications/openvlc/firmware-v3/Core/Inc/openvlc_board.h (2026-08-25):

#ifndef OPENVLC_BOARD_H
#define OPENVLC_BOARD_H

#include "stm32h7xx_hal.h"

#if !defined(STM32H723xx)
#error "stm32-transceiver-pi-hat must be built for STM32H723xx"
#endif

/*
 * Bring-up gate retained from the validated comparator receiver.
 *
 * 0: UART heartbeat only.
 * 1: UART + OpenVLC init.
 * 2: UART + OpenVLC init + COMP1/TIM2 capture start.
 * 3: full OpenVLC runtime polling.
 */
#ifndef OPENVLC_BOOT_STAGE
#define OPENVLC_BOOT_STAGE 3
#endif

/*
 * Runtime instrumentation profile.
 *
 * 0 = production: no periodic STM32 text logs, no 10 kHz TX register monitor
 *                  and no diagnostic second pass over captured bursts.
 * 1 = compact:    one RX/TX health record per logging period.
 * 2 = deep:       register snapshots, TX pin probe, decoder detail and the
 *                 one-shot RXFAIL interval capture.
 *
 * Functional counters used by capture protection and threshold control remain
 * active at every level. Change this single define when collecting a trace.
 */
#ifndef OPENVLC_DIAGNOSTIC_LEVEL
#define OPENVLC_DIAGNOSTIC_LEVEL 1u
#endif

#if OPENVLC_DIAGNOSTIC_LEVEL > 2u
#error "OPENVLC_DIAGNOSTIC_LEVEL must be 0, 1, or 2"
#endif

#ifndef OPENVLC_BURST_TRACE
#define OPENVLC_BURST_TRACE 0
#endif

#ifndef OPENVLC_MAX_PAYLOAD_BYTES
#define OPENVLC_MAX_PAYLOAD_BYTES 900u
#endif

#ifndef OPENVLC_BEAGLEBONE_RS_ECC_BYTES
#define OPENVLC_BEAGLEBONE_RS_ECC_BYTES 8u
#endif

/*
 * STM32 RX uses the internal comparator as the optical slicer:
 * PB0 -> COMP1 IN+, DAC1_CH1 threshold, COMP1 output -> TIM2 CH4 input capture.
 * The decoder consumes edge timestamps, matching the BeagleBone PRU receiver.
 */
#ifndef OPENVLC_RX_COMPARATOR
#define OPENVLC_RX_COMPARATOR 1
#endif

/*
 * Host forwarding to a Raspberry Pi bridge. When 1, decoded IP payloads and
 * runtime logs are queued and sent over USART3 instead of blocking the optical
 * decoder. Set 0 for a plain-text bring-up console.
 */
#ifndef OPENVLC_RX_HOST_FORWARD
#define OPENVLC_RX_HOST_FORWARD 1
#endif

/*
 * 2 Mbaud, the proven rate (4 Mbaud produced no output on this board's
 * ST-LINK VCP). The old ring-wrap problem at 2 Mbaud came from the BLOCKING
 * record send and later from a TXE interrupt for every byte. Host UART TX now
 * uses normal-mode DMA, so the main loop is not stalled or preempted per byte.
 * The 2 Mbaud line rate (134 records/s = ~1.06 Mbit/s payload, 53% duty) is
 * sufficient. Keep the Pi bridge at --baud 2000000.
 */
#ifndef OPENVLC_HOST_UART_BAUD
#if OPENVLC_RX_HOST_FORWARD
#define OPENVLC_HOST_UART_BAUD 2000000u
#else
#define OPENVLC_HOST_UART_BAUD 115200u
#endif
#endif

/*
 * Host-forward queue. Each decoded packet enqueues an IP record plus its log
 * lines, and the continuous-capture poll can decode several back-to-back
 * packets in ONE iteration during iperf bursts, so 8 slots overflowed and
 * dropped IP frames (hostdrop). 32 slots (~29 KB, lives in RAM_D1) absorb a
 * whole burst train.
 */
#ifndef OPENVLC_HOST_QUEUE_DEPTH
#define OPENVLC_HOST_QUEUE_DEPTH 32u
#endif

/*
 * Comparator slice level, expressed directly in MILLIVOLTS against the analog
 * reference (VREF). The firmware converts mV -> 12-bit DAC counts with
 * OPENVLC_MV_TO_DAC(). This is the human-readable knob; keep the DAC count as a
 * derived value only.
 *
 * Optimum = the signal DC mean, because a DC-balanced Manchester waveform has
 * its single-cell eye centred exactly there. Two oscilloscope captures at
 * 12.5 MS/s put the mean at ~1998 mV (single-cell eye 1920..2077 mV, only
 * ~157 mV open; the double-cell eye is ~397 mV). A threshold even ~80 mV high
 * drops the single cells and the impossible-run (>=4 cell) count explodes. So
 * centre on the mean, not on any fixed "plateau".
 */
#ifndef OPENVLC_VREF_MV
#define OPENVLC_VREF_MV 3300u
#endif
#define OPENVLC_MV_TO_DAC(mv) \
	((uint32_t)(((uint32_t)(mv) * 4095u + OPENVLC_VREF_MV / 2u) / \
		    OPENVLC_VREF_MV))
#define OPENVLC_DAC_TO_MV(dac) \
	((uint32_t)(((uint32_t)(dac) * OPENVLC_VREF_MV + 2047u) / 4095u))
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

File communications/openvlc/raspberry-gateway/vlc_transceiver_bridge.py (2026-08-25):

#!/usr/bin/env python3
"""Bidirectional Linux TUN <-> STM32 OpenVLC transceiver bridge."""

import argparse
import pathlib
import socket
import fcntl
import ipaddress
import os
import select
import signal
import subprocess
import sys
import time
from collections import deque
from typing import Optional

from vlc_host_protocol import (
    HostFrameParser,
    TYPE_CAPTURE,
    TYPE_IP,
    TYPE_LOG,
    encode_frame,
    validate_ip_packet,
)
from vlc_capture import CaptureAssembler
from vlc_pacing import advance_paced_deadline
from vlc_stm32_tx_bridge import configure_tun, open_tun, resolve_serial_port


def packet_destination(packet: bytes):
    version = packet[0] >> 4
    if version == 4:
        return ipaddress.ip_address(packet[16:20])
    return ipaddress.ip_address(packet[24:40])


# Logs and captures live beside this script, so they travel with the
# deployment instead of scattering into /var/log. Resolved from __file__
# rather than the working directory: systemd starts this from /.
LOG_DIR = pathlib.Path(__file__).resolve().parent / "logs"
DEFAULT_CAPTURE_DIR = LOG_DIR / "captures"


def main() -> int:
    cli = argparse.ArgumentParser(
        description="Bidirectional STM32 OpenVLC transceiver bridge"
    )
    cli.add_argument("--port", default="auto")
    cli.add_argument("--baud", type=int, default=2_000_000)
    cli.add_argument("--dev", default="tun0")
    cli.add_argument("--ip", default="192.168.0.2/24")
    cli.add_argument("--peer-ip", default="192.168.0.1")
    cli.add_argument(
        "--source-route",
        default="10.0.0.0/24",
        help="return route for sources behind a legacy BBB; empty disables it",
    )
    cli.add_argument("--mtu", type=int, default=900)
    cli.add_argument("--max-payload", type=int, default=900)
    cli.add_argument("--stats-interval", type=float, default=5.0)
    cli.add_argument(
        "--tx-max-fps",
        type=float,
        default=125.0,
        help=(
            "maximum host records sent to the STM32 per second; "
            "0 disables pacing (default: 125)"
        ),
    )
    cli.add_argument("--quiet-stm32", action="store_true")
    cli.add_argument(
        "--capture-dir",
        default=str(DEFAULT_CAPTURE_DIR),
        help="directory for validated STM32 RX captures",
    )
    cli.add_argument(
        "--capture-node",
        default=socket.gethostname(),
        help="node label in capture filenames (default: this hostname)",
    )
    cli.add_argument(
        "--no-capture-save",
        action="store_true",
        help="validate but do not persist STM32 RX captures",
    )
    cli.add_argument("--no-configure", action="store_true")
    cli.add_argument(
        "--tx-allow",
        action="append",
        default=[],
        metavar="CIDR",
        help="TX destination prefix; repeat as needed (default: peer /32 only)",
    )
    cli.add_argument(
        "--forward-all",
        action="store_true",
        help="forward every TUN egress packet, including kernel feedback",
    )
    args = cli.parse_args()
    if args.tx_max_fps < 0:
        cli.error("--tx-max-fps must be >= 0")

    local_ip = str(ipaddress.ip_interface(args.ip).ip)
    if local_ip == args.peer_ip:
        cli.error("--ip and --peer-ip must identify different nodes")
    tx_allow = [ipaddress.ip_network(value, strict=False) for value in args.tx_allow]
    if not tx_allow:
        peer = ipaddress.ip_address(args.peer_ip)
        tx_allow = [ipaddress.ip_network(f"{peer}/{peer.max_prefixlen}")]

    try:
        import serial
    except ImportError:
        sys.stderr.write("pyserial is required: sudo apt install python3-serial\n")
        return 2

    serial_path = resolve_serial_port(args.port)
    tun = open_tun(args.dev)
    if not args.no_configure:
        configure_tun(args.dev, args.ip, args.peer_ip, args.mtu)
        if args.source_route:
            subprocess.run(
                [
                    "ip",
                    "route",
                    "replace",
                    args.source_route,
                    "dev",
                    args.dev,
                ],
                check=True,
            )
    port = serial.Serial(
        serial_path,
        args.baud,
        timeout=0,
        write_timeout=0,
        rtscts=False,
        dsrdtr=False,
    )
    # A blocking serial write used to stall the WHOLE pump (both directions)
    # for up to 1 s whenever the ST-Link VCP back-pressured under bidirectional
    # load - the STM32 TX queue then drained and the LED gapped. The fd is now
    # non-blocking and downlink frames wait in a bounded backlog drained via
    # select's write set, so uplink congestion can never freeze the downlink.
    port_fd = port.fileno()
    fcntl.fcntl(port_fd, fcntl.F_SETFL,
                fcntl.fcntl(port_fd, fcntl.F_GETFL) | os.O_NONBLOCK)
    serial_backlog: deque = deque()
    # ~0.5 s of downlink at 125 fps; beyond this the serial link is genuinely
    # saturated and dropping (UDP semantics) beats unbounded latency.
    serial_backlog_max = 64
    serial_interval_ns = (
        int(1_000_000_000 / args.tx_max_fps)
        if args.tx_max_fps > 0
        else 0
    )
    next_serial_frame_ns = 0
    serial_frame_in_progress = False
    parser = HostFrameParser(args.max_payload)
    capture_assembler = CaptureAssembler(
        args.capture_dir,
        args.capture_node,
        persist=not args.no_capture_save,
    )
    stopped = False

    def stop_handler(_signum, _frame):
        nonlocal stopped
        stopped = True

    signal.signal(signal.SIGINT, stop_handler)
    signal.signal(signal.SIGTERM, stop_handler)

    tx_sequence = 0
    expected_rx_sequence: Optional[int] = None
    tx_frames = tx_bytes = tx_drops = tx_filtered = 0
    serial_frames_completed = 0
    rx_frames = rx_bytes = rx_invalid = rx_gaps = rx_resets = 0
    log_frames = capture_frames = captures_saved = capture_errors = 0
    serial_errors = tun_errors = 0
    previous = (0, 0, 0, 0, 0)
    interval_start = time.monotonic()
    next_stats = interval_start + args.stats_interval

    sys.stderr.write(
        f"[trx-bridge] {args.dev} {args.ip} <-> "
        f"{serial_path}@{args.baud}, peer={args.peer_ip}, mtu={args.mtu}, "
        f"source_route={args.source_route or 'off'}, "
        f"tx_allow={'all' if args.forward_all else ','.join(map(str, tx_allow))}, "
        f"tx_max_fps={args.tx_max_fps:g}\n"
    )
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

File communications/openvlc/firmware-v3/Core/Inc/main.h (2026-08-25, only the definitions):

#define HOST_UART_TX_Pin GPIO_PIN_10
#define HOST_UART_TX_GPIO_Port GPIOB
#define HOST_UART_RX_Pin GPIO_PIN_11
#define HOST_UART_RX_GPIO_Port GPIOB
#define JTMS_Pin GPIO_PIN_13
#define JTMS_GPIO_Port GPIOA
#define JTCK_Pin GPIO_PIN_14
#define JTCK_GPIO_Port GPIOA

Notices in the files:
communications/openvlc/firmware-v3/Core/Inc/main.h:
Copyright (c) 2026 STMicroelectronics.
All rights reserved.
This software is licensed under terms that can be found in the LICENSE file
